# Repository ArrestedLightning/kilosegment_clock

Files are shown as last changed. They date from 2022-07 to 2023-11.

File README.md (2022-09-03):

Kilosegment Clock
==================

Contents of the Firmware directory is licensed under GPLv3.

All other content in this repository is licensed under CC BY 4.0.

Acknowledgments
=================

Firmware for this project is based substantially on John Bradnam's work here: https://create.arduino.cc/projecthub/john-bradnam/7-segment-array-clock-cd5b07

His project, in turn, was based in part upon Frugha's project here: https://hackaday.io/project/169632-7-segment-display-array-clock

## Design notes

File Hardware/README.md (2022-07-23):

Kilosegment Clock Hardware
===============

Rev A and Rev B should be functionally identical.  Rev A is designed with individual 7-segment displays, and Rev B uses 4-digit displays, which substantially reduces the number of through-hole pins that need to be soldered.

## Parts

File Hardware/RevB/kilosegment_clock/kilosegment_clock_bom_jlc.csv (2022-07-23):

Comment | Designator | Footprint | LCSC Part #
Battery_Cell | BT1 | BatteryHolder_CR2032-BS-6-1_1x2032 | C964764
0.1uF | C10,C11,C12,C13,C20,C21,C22,C24,C23 | C_0805_2012Metric_Pad1.18x1.45mm_HandSolder | C49678
1uF | C14,C15,C25,C1,C2,C3,C4,C5,C6,C7,C8,C9 | C_0805_2012Metric_Pad1.18x1.45mm_HandSolder | C28323
12pF | C16,C17 | C_0805_2012Metric_Pad1.18x1.45mm_HandSolder | C1792
20pF | C18,C19 | C_0805_2012Metric_Pad1.18x1.45mm_HandSolder | C1798
LED | D1 | LED_0805_2012Metric_Pad1.15x1.40mm_HandSolder | C84256
FJ5461AHred | D6,D5,D4,D3,D10,D9,D8,D7,D14,D13,D12,D11,D18,D17,D16,D15,D22,D21,D20,D19,D26,D25,D24,D23,D30,D29,D28,D27,D34,D33,D32,D31,D38,D37,D36,D35 | LED-SEG-TH_FJ5461AH | C54396
LM75BDP | IC1 | MSOP-8_3x3mm_P0.65mm | C2837470
USB_C_Receptacle_USB2.0 | J3 | USB_C_Receptacle_HRO_TYPE-C-31-M-12 | C165948
Speaker | LS1 | BUZ-TH_PKM13EPYH4002-B0 | C128650
AO3400A | Q1 | SOT-23_Handsoldering | C20917
2.7K | R1,R2 | R_0805_2012Metric_Pad1.20x1.40mm_HandSolder | C17530
0 | R3,R8 | R_0805_2012Metric_Pad1.20x1.40mm_HandSolder | C17477
5.1K | R4,R5,R9 | R_0805_2012Metric_Pad1.20x1.40mm_HandSolder | C27834
1K | R7,R6 | R_0805_2012Metric_Pad1.20x1.40mm_HandSolder | C17513
SW_Push | SW1,SW2,SW3,SW4 | SW_SPST_TL3342 | C318886
GN6932 | U0,U1,U2,U3,U4,U5,U6,U7,U8 | SOP-32_L21.0-W7.5-P1.27-LS10.4-BL | C265476
HT7533-1-SOT89 | U9 | SOT-89-3 | C14289
STM32F103C8T6 | U10 | LQFP-48_7x7mm_P0.5mm | C77994
SN74ACT244PWRG4 | U12,U11 | TSSOP-20_4.4x6.5mm_P0.65mm | C6930
LTR-303ALS-01 | U13 | SOT-363_SC-70-6_Handsoldering | C364577
32.768KHz | Y1 | Crystal_SMD_3215-2Pin_3.2x1.5mm | C32346
8MHz | Y2 | Crystal_SMD_5032-2Pin_5.0x3.2mm_HandSoldering | C115962

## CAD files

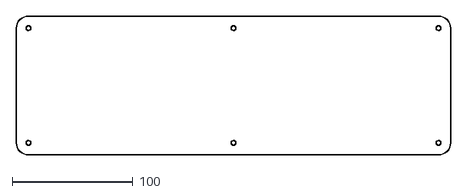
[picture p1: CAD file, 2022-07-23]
Hardware/RevB/kilosegment_clock/Board Outline.dxf
360.0 x 115.0

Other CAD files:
Hardware/RevB/Board Outline.FCStd
Hardware/RevA/Board Outline.FCStd

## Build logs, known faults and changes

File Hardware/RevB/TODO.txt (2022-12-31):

Label for D31 is in the wrong location (obviously not a functional issue).
Add a header input for 5V so it can be powered without USB.
Add letters below OSHW logo
Add more thermal isolation to temperature sensor IC.
Consider increasing capacitor size on display drivers and enhancing ground/power connections.
USB series and pull up resistors
Stronger pullup on reset pin

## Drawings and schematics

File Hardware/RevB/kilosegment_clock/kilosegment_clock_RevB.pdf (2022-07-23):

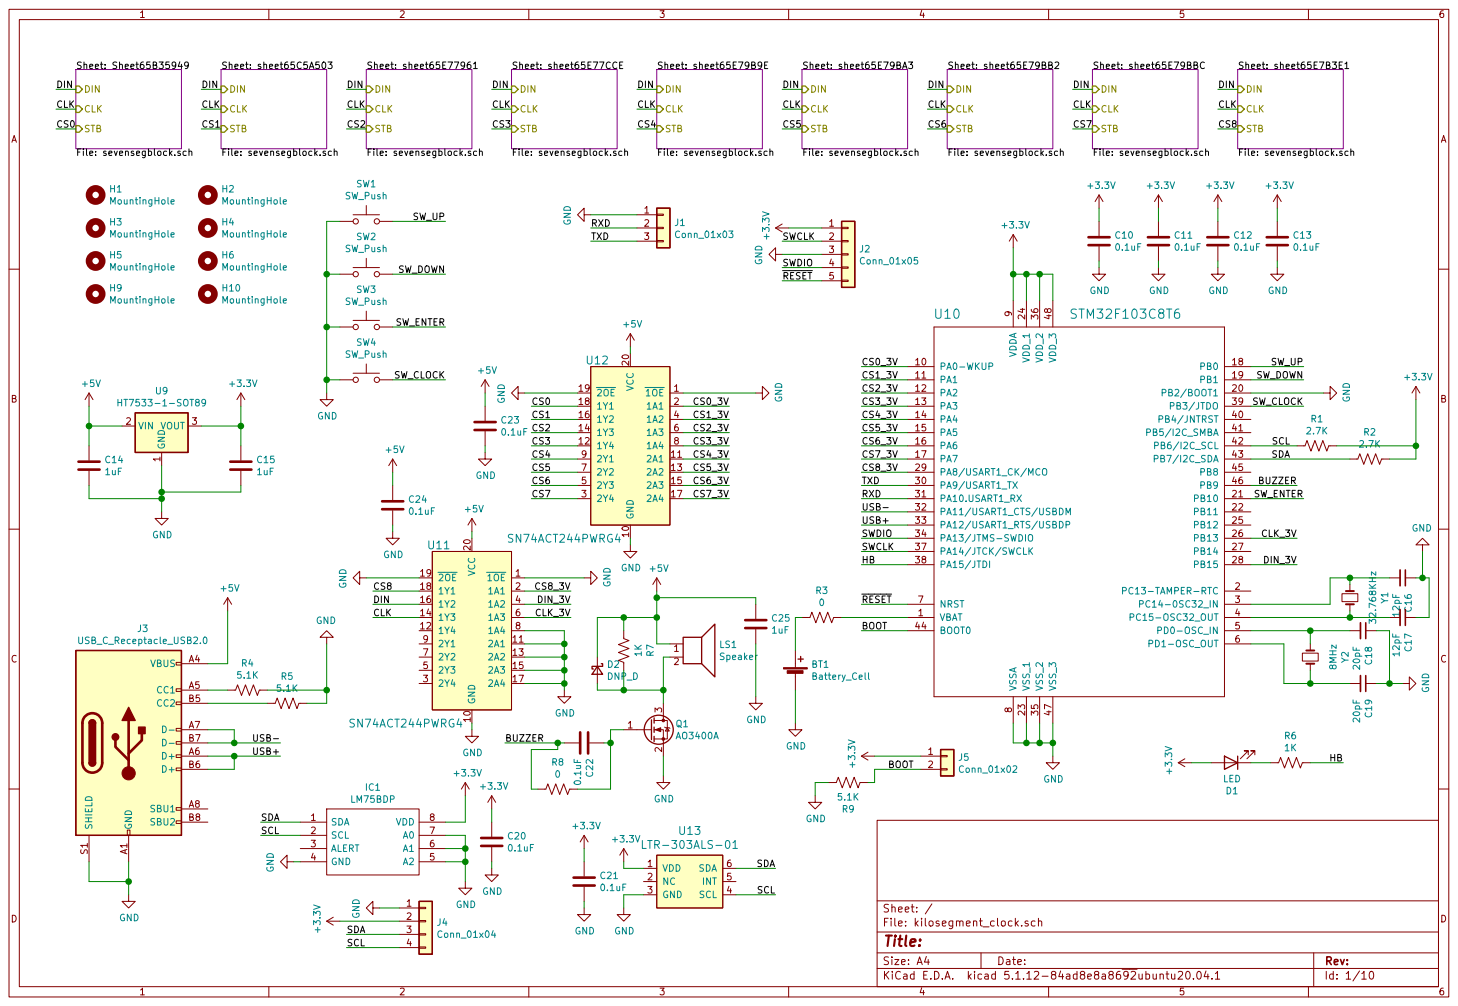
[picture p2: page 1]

File: sevensegblock.sch DIN
CLK
STB

Sheet: Sheet65B35949 File: sevensegblock.sch DIN
DIN

Sheet: sheet65C5A503 File: sevensegblock.sch DIN
CS8_3V CS0_3V DIN

Sheet: sheet65E77961 File: sevensegblock.sch DIN
SW_UP CLK DIN

Sheet: sheet65E79BA3 File: sevensegblock.sch DIN

Sheet: sheet65E79BB2 File: sevensegblock.sch DIN

Sheet: sheet65E7B3E1 File: sevensegblock.sch DIN

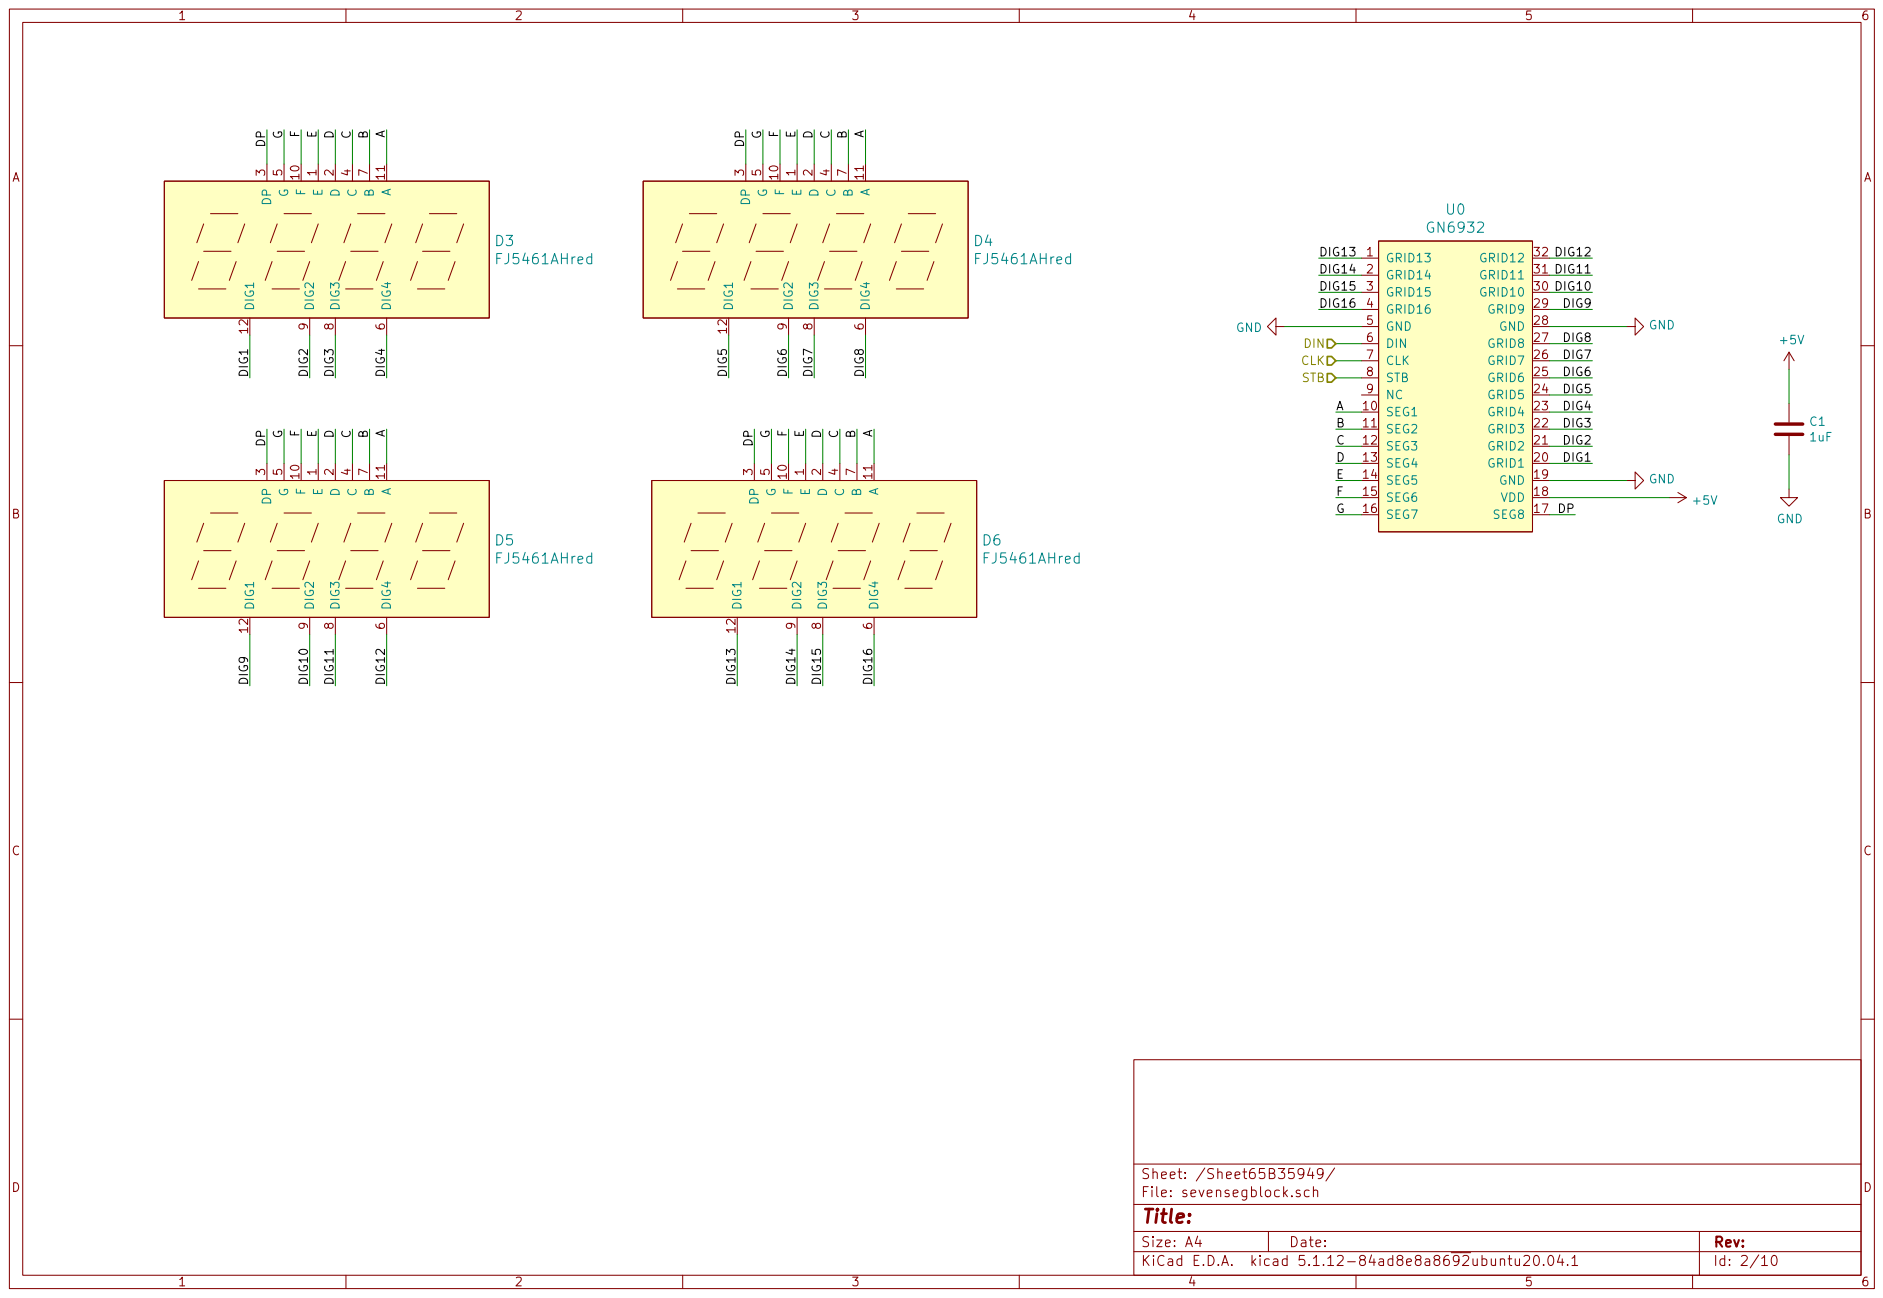
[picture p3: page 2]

File: sevensegblock.sch Sheet: /Sheet65B35949/
Id: 2/10 Title:

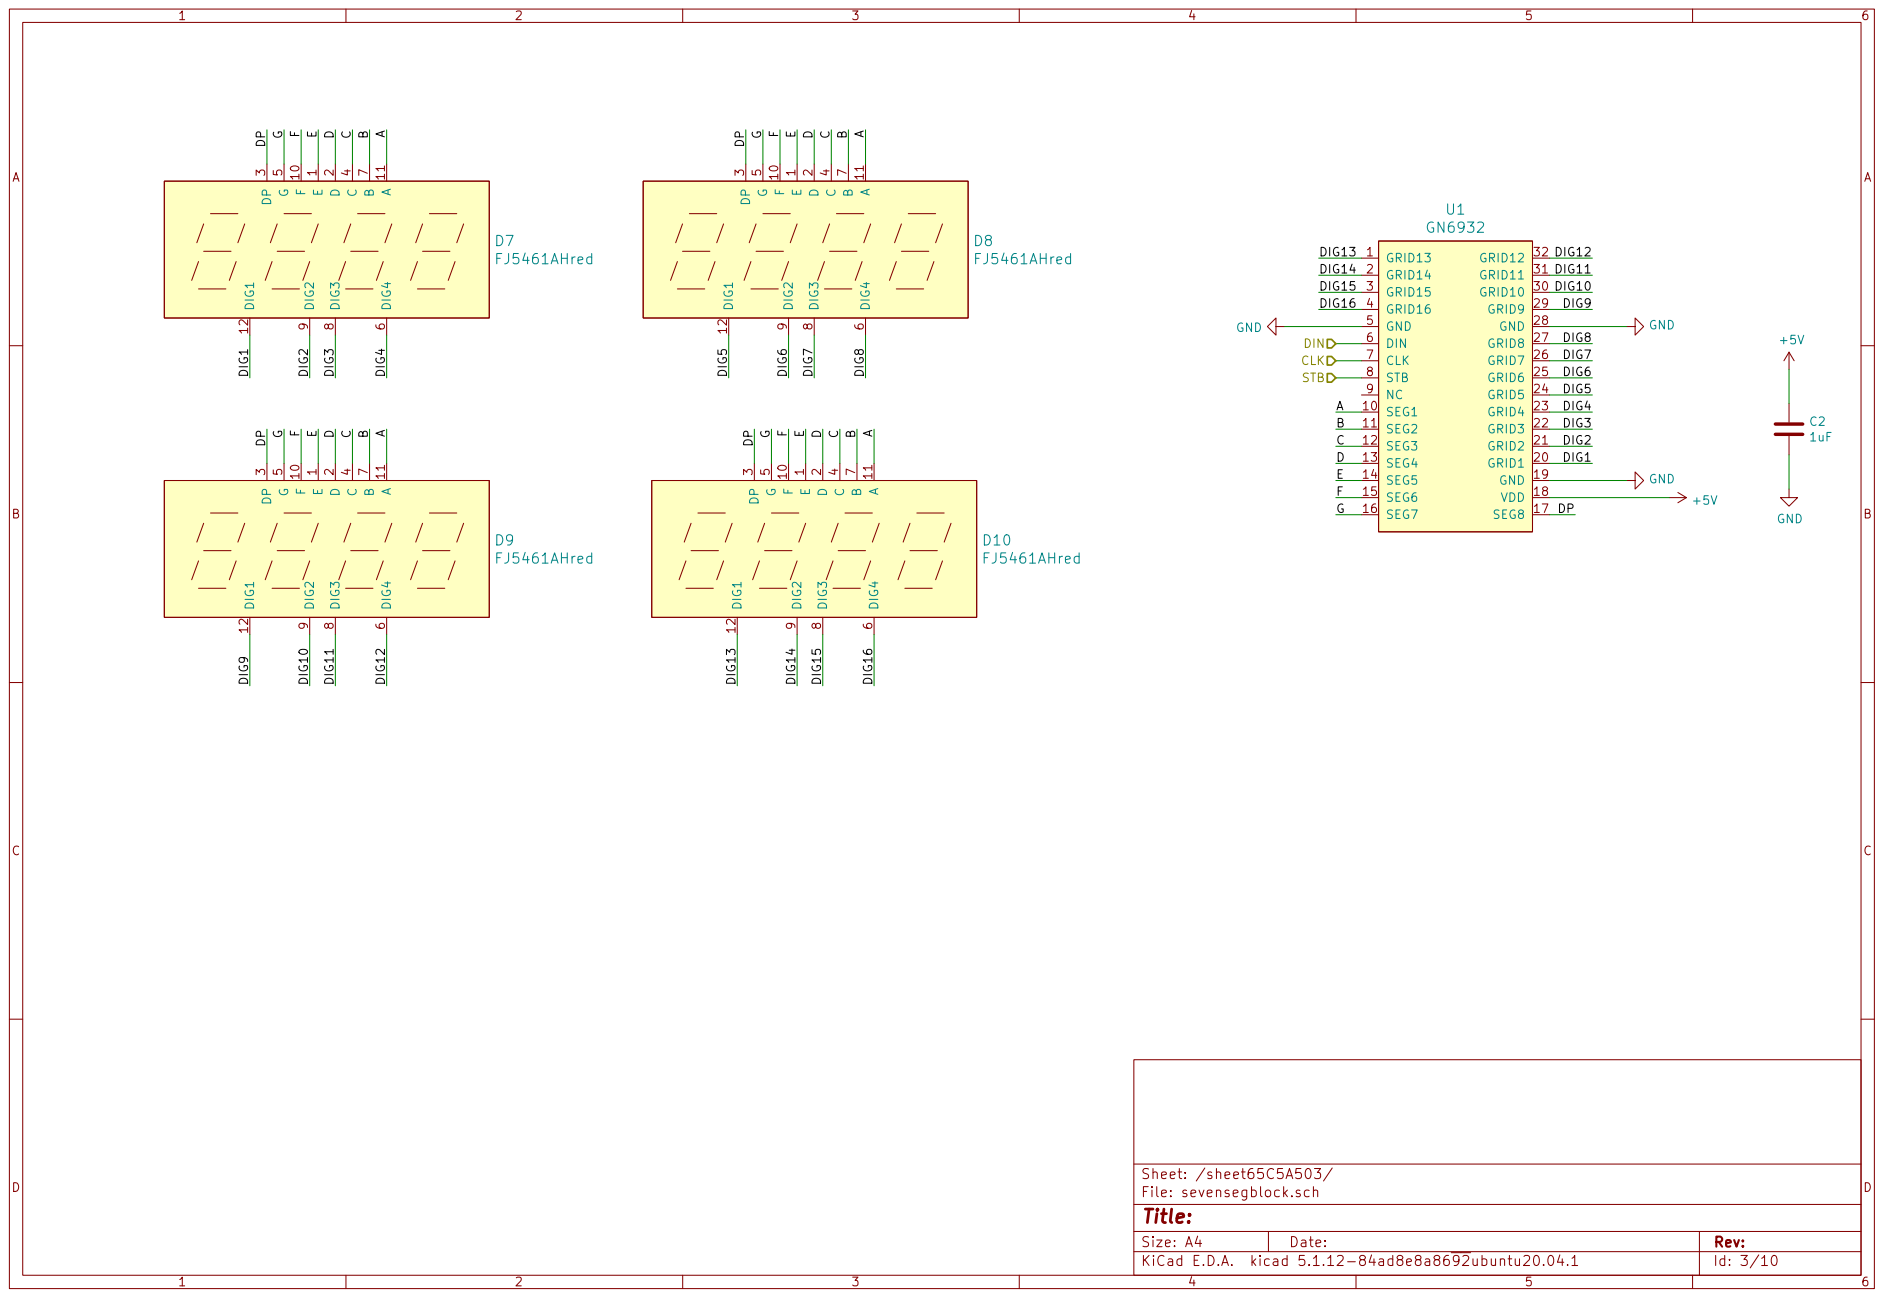
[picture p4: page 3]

File: sevensegblock.sch Sheet: /sheet65C5A503/
Id: 3/10 Title:

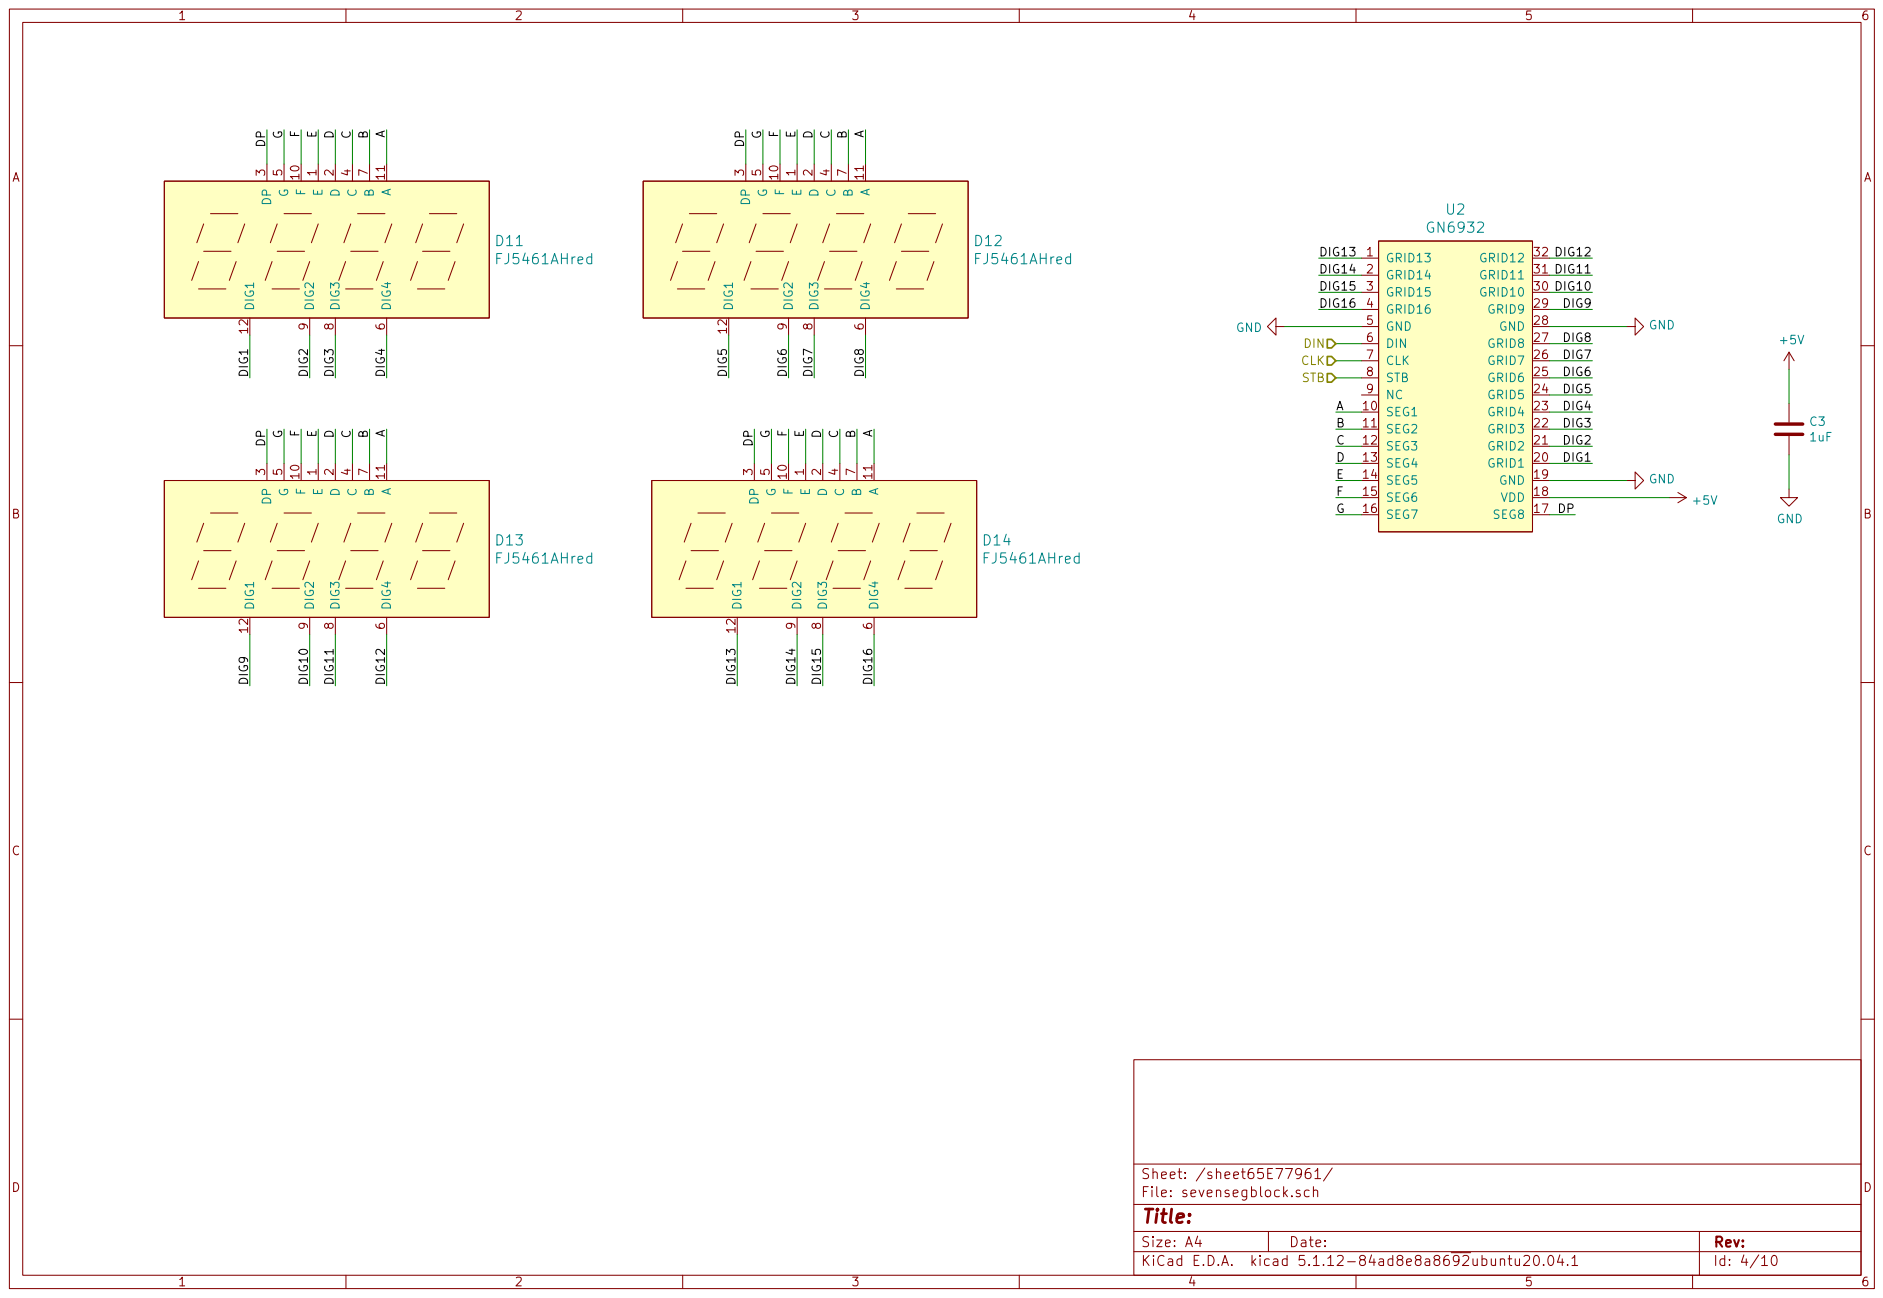
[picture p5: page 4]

File: sevensegblock.sch Sheet: /sheet65E77961/
Id: 4/10 Title:

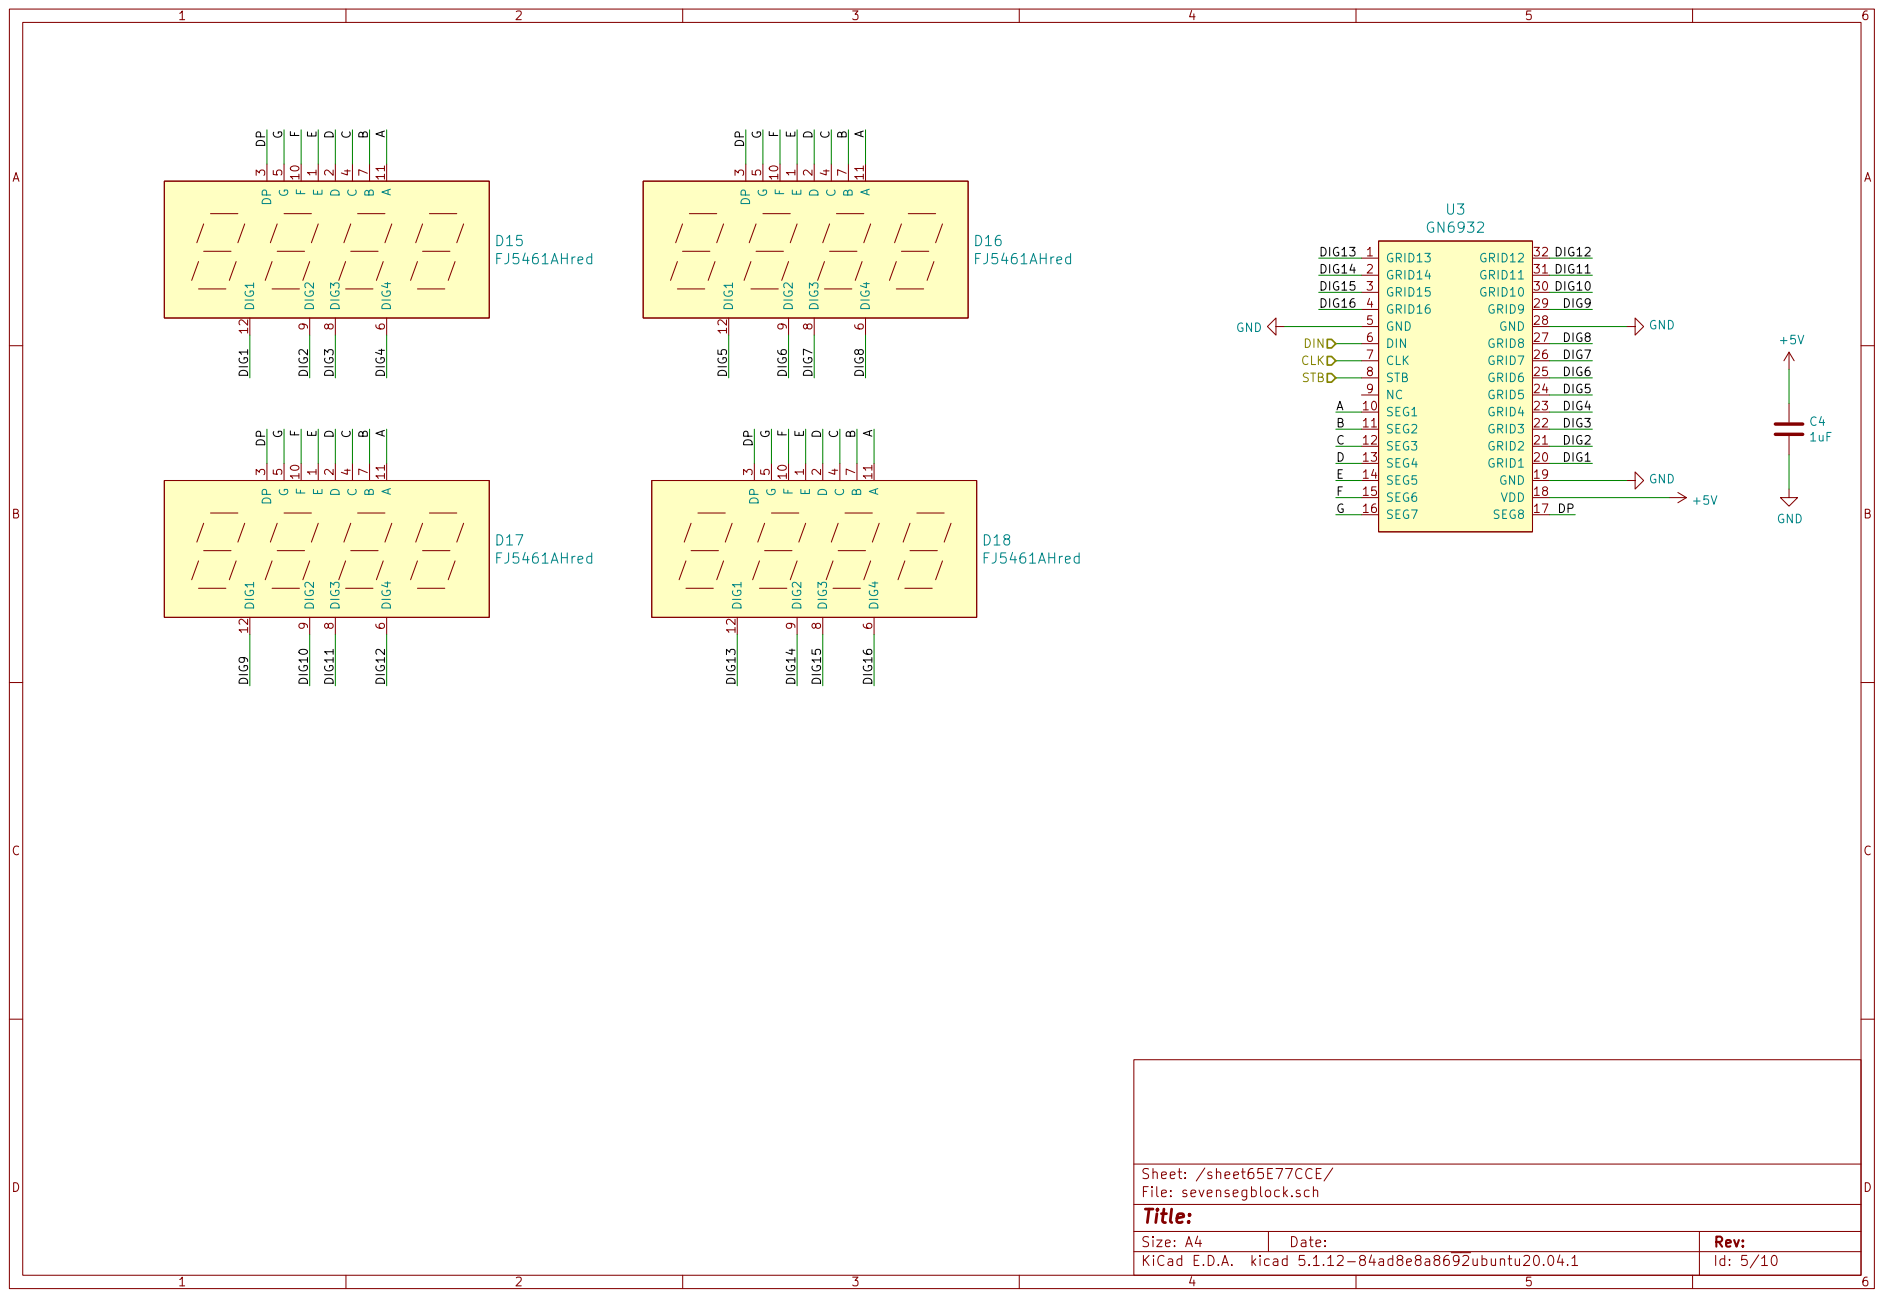
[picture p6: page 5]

File: sevensegblock.sch Sheet: /sheet65E77CCE/
Id: 5/10 Title:

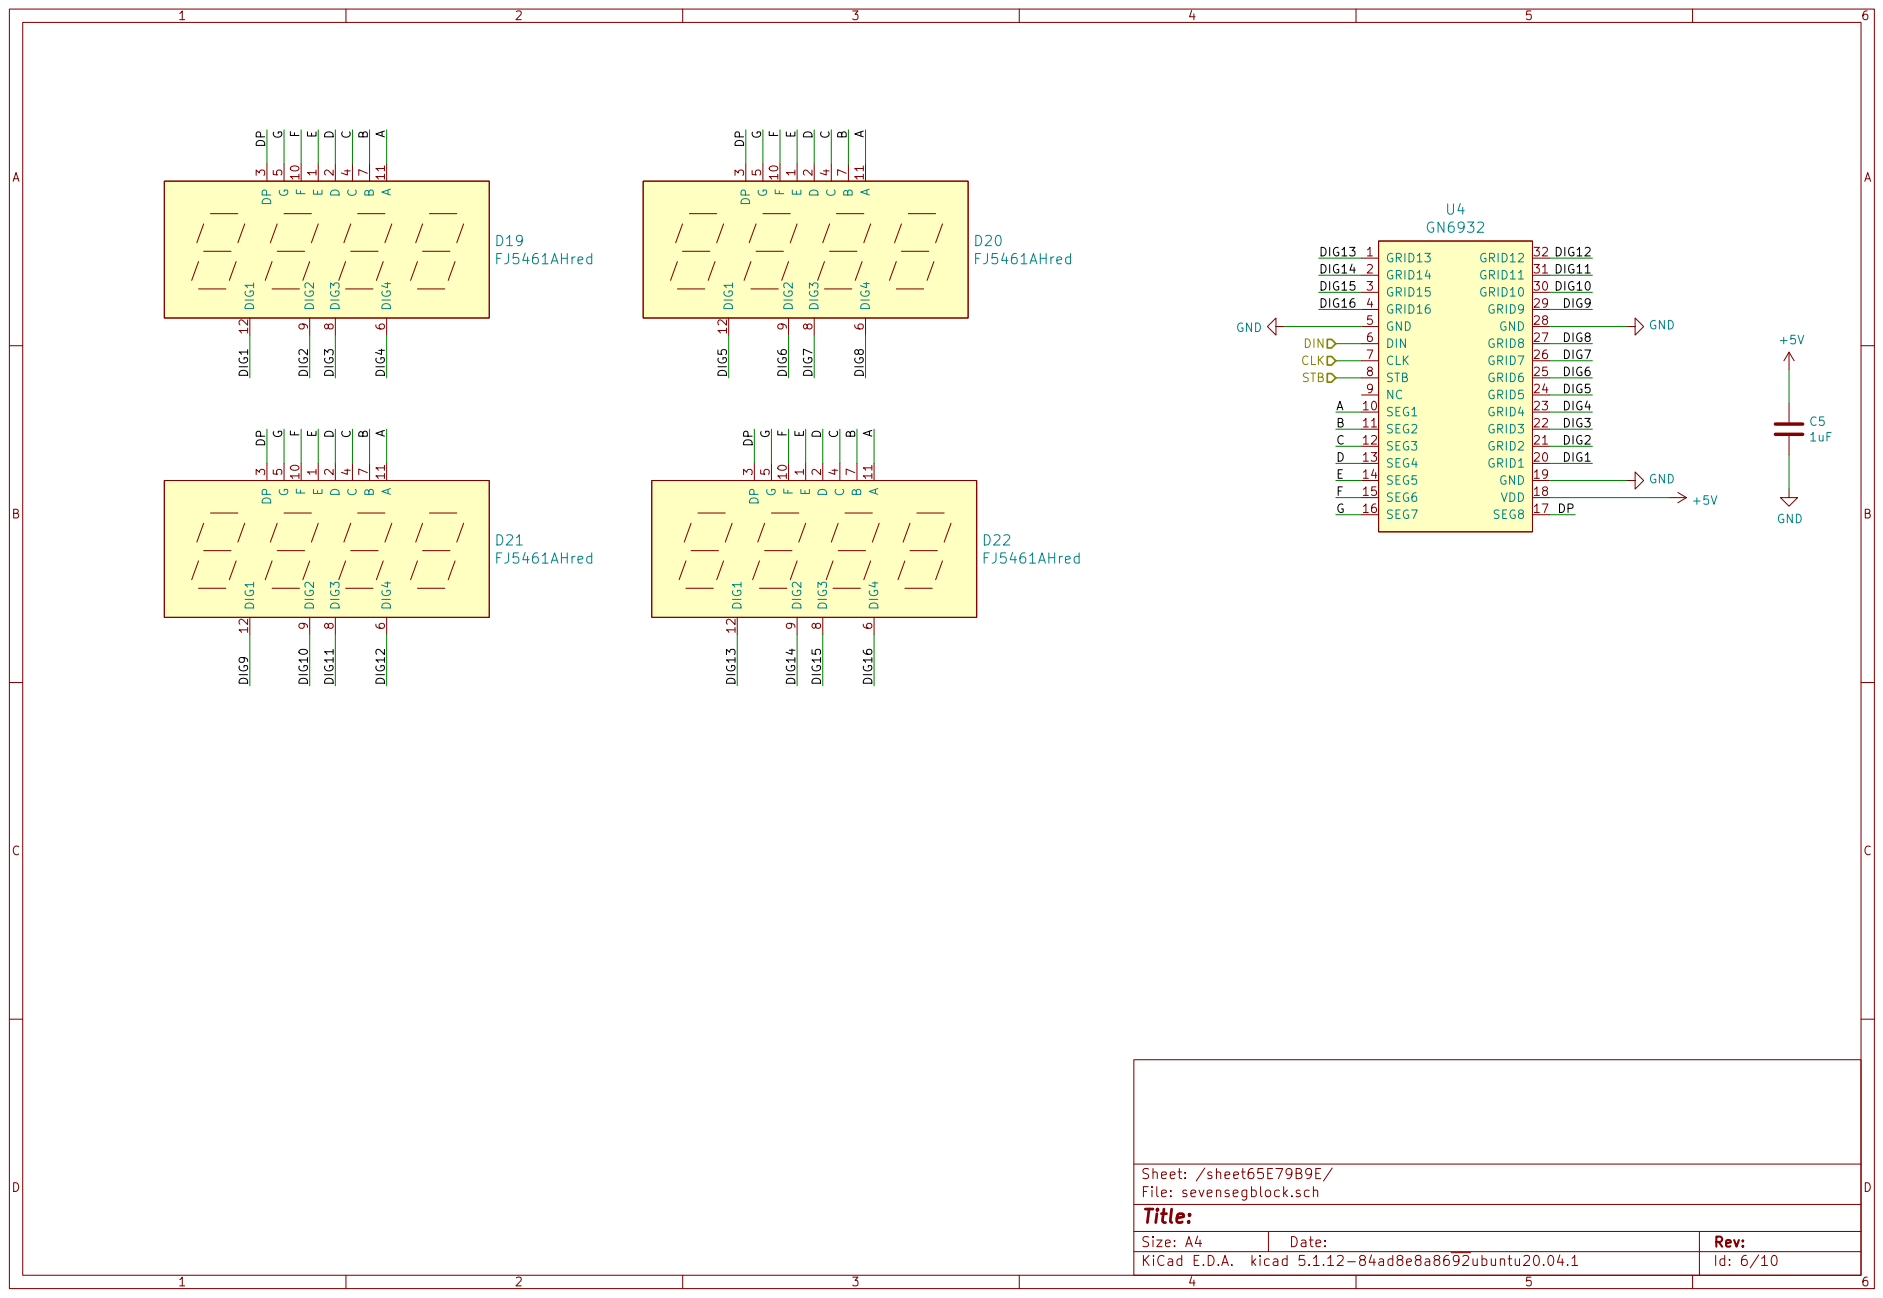
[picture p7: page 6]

File: sevensegblock.sch Sheet: /sheet65E79B9E/
Id: 6/10 Title:

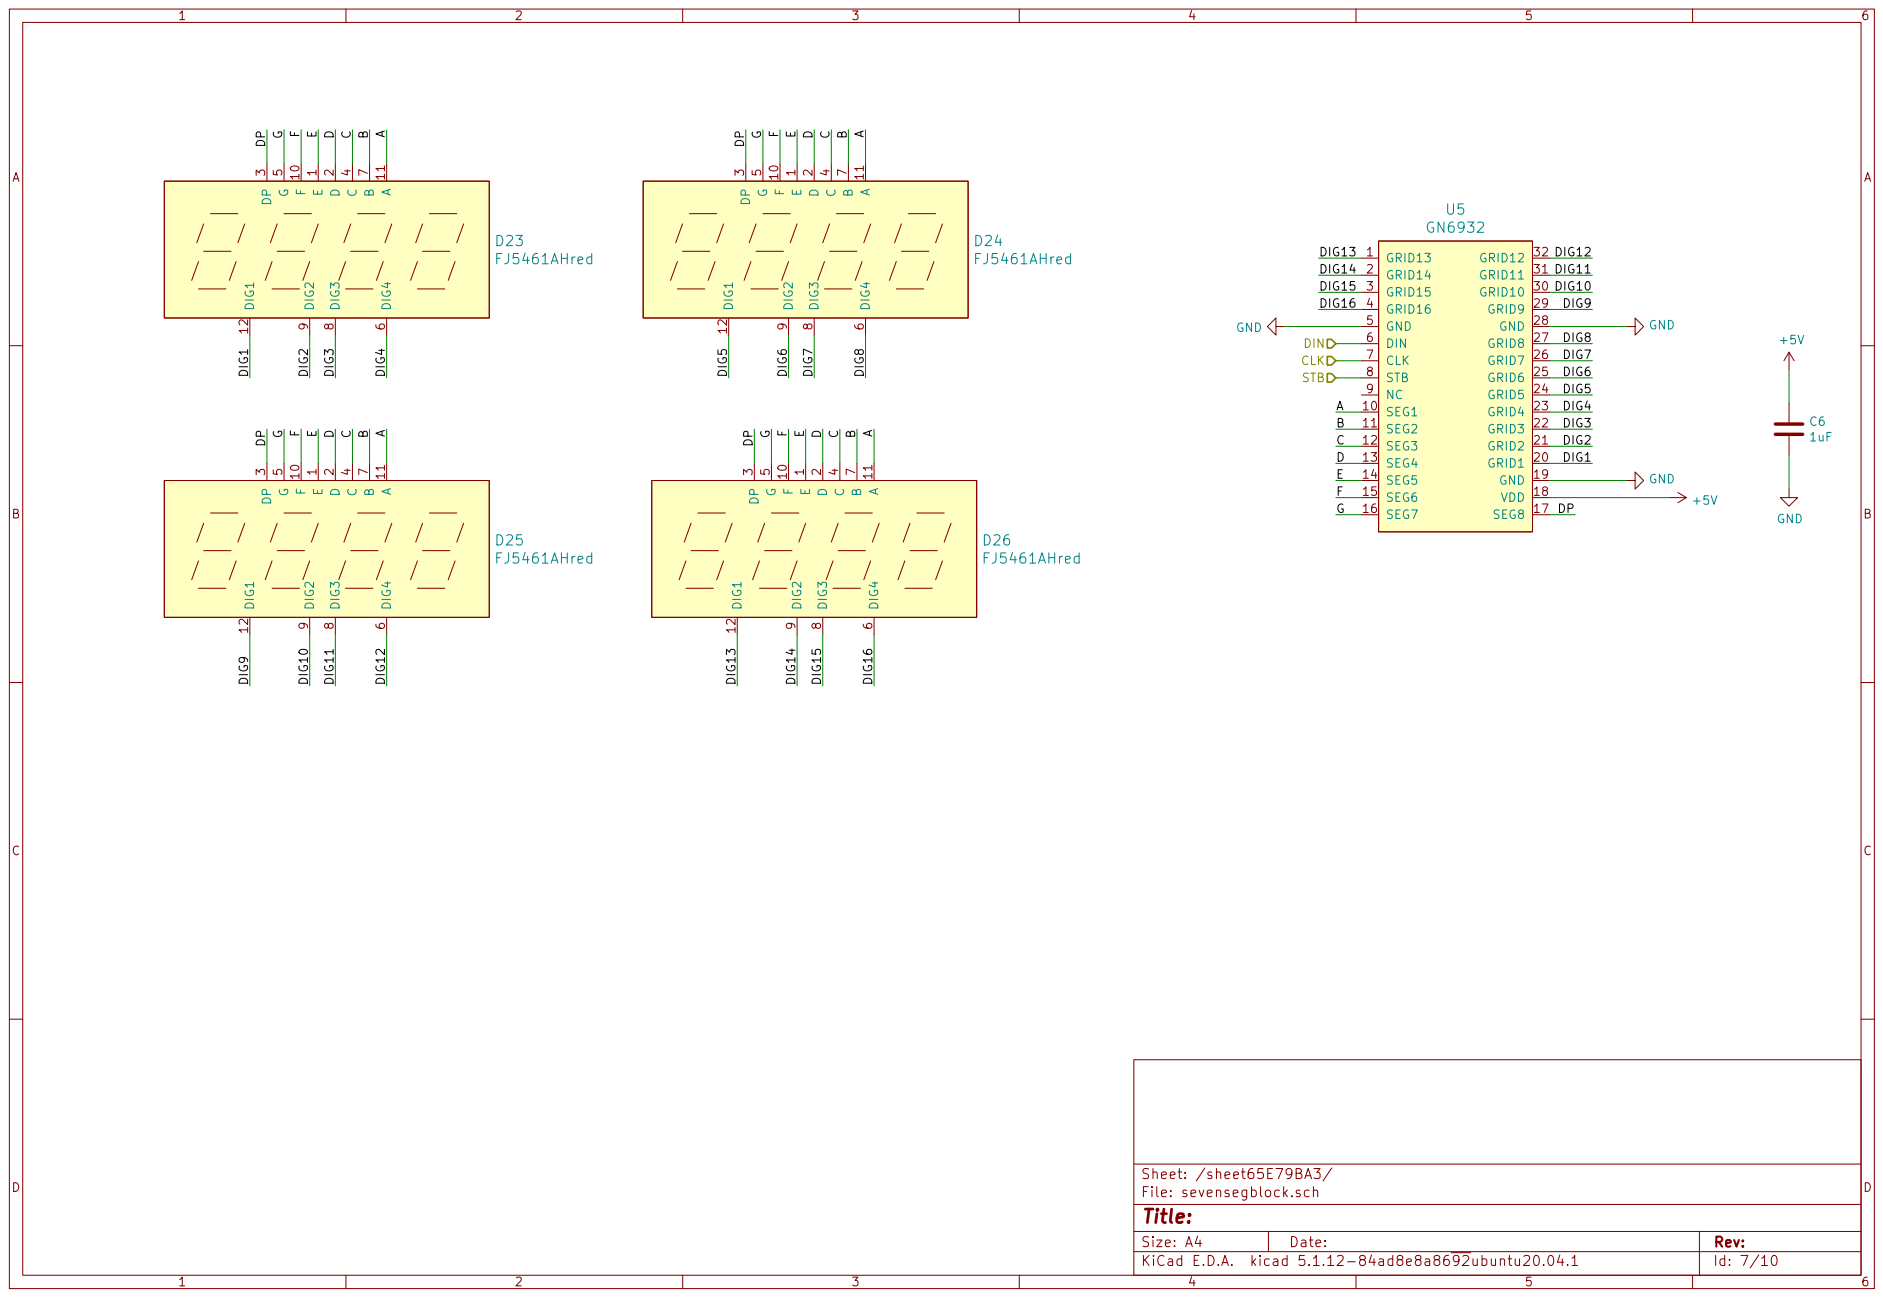
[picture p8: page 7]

File: sevensegblock.sch Sheet: /sheet65E79BA3/
Id: 7/10 Title:

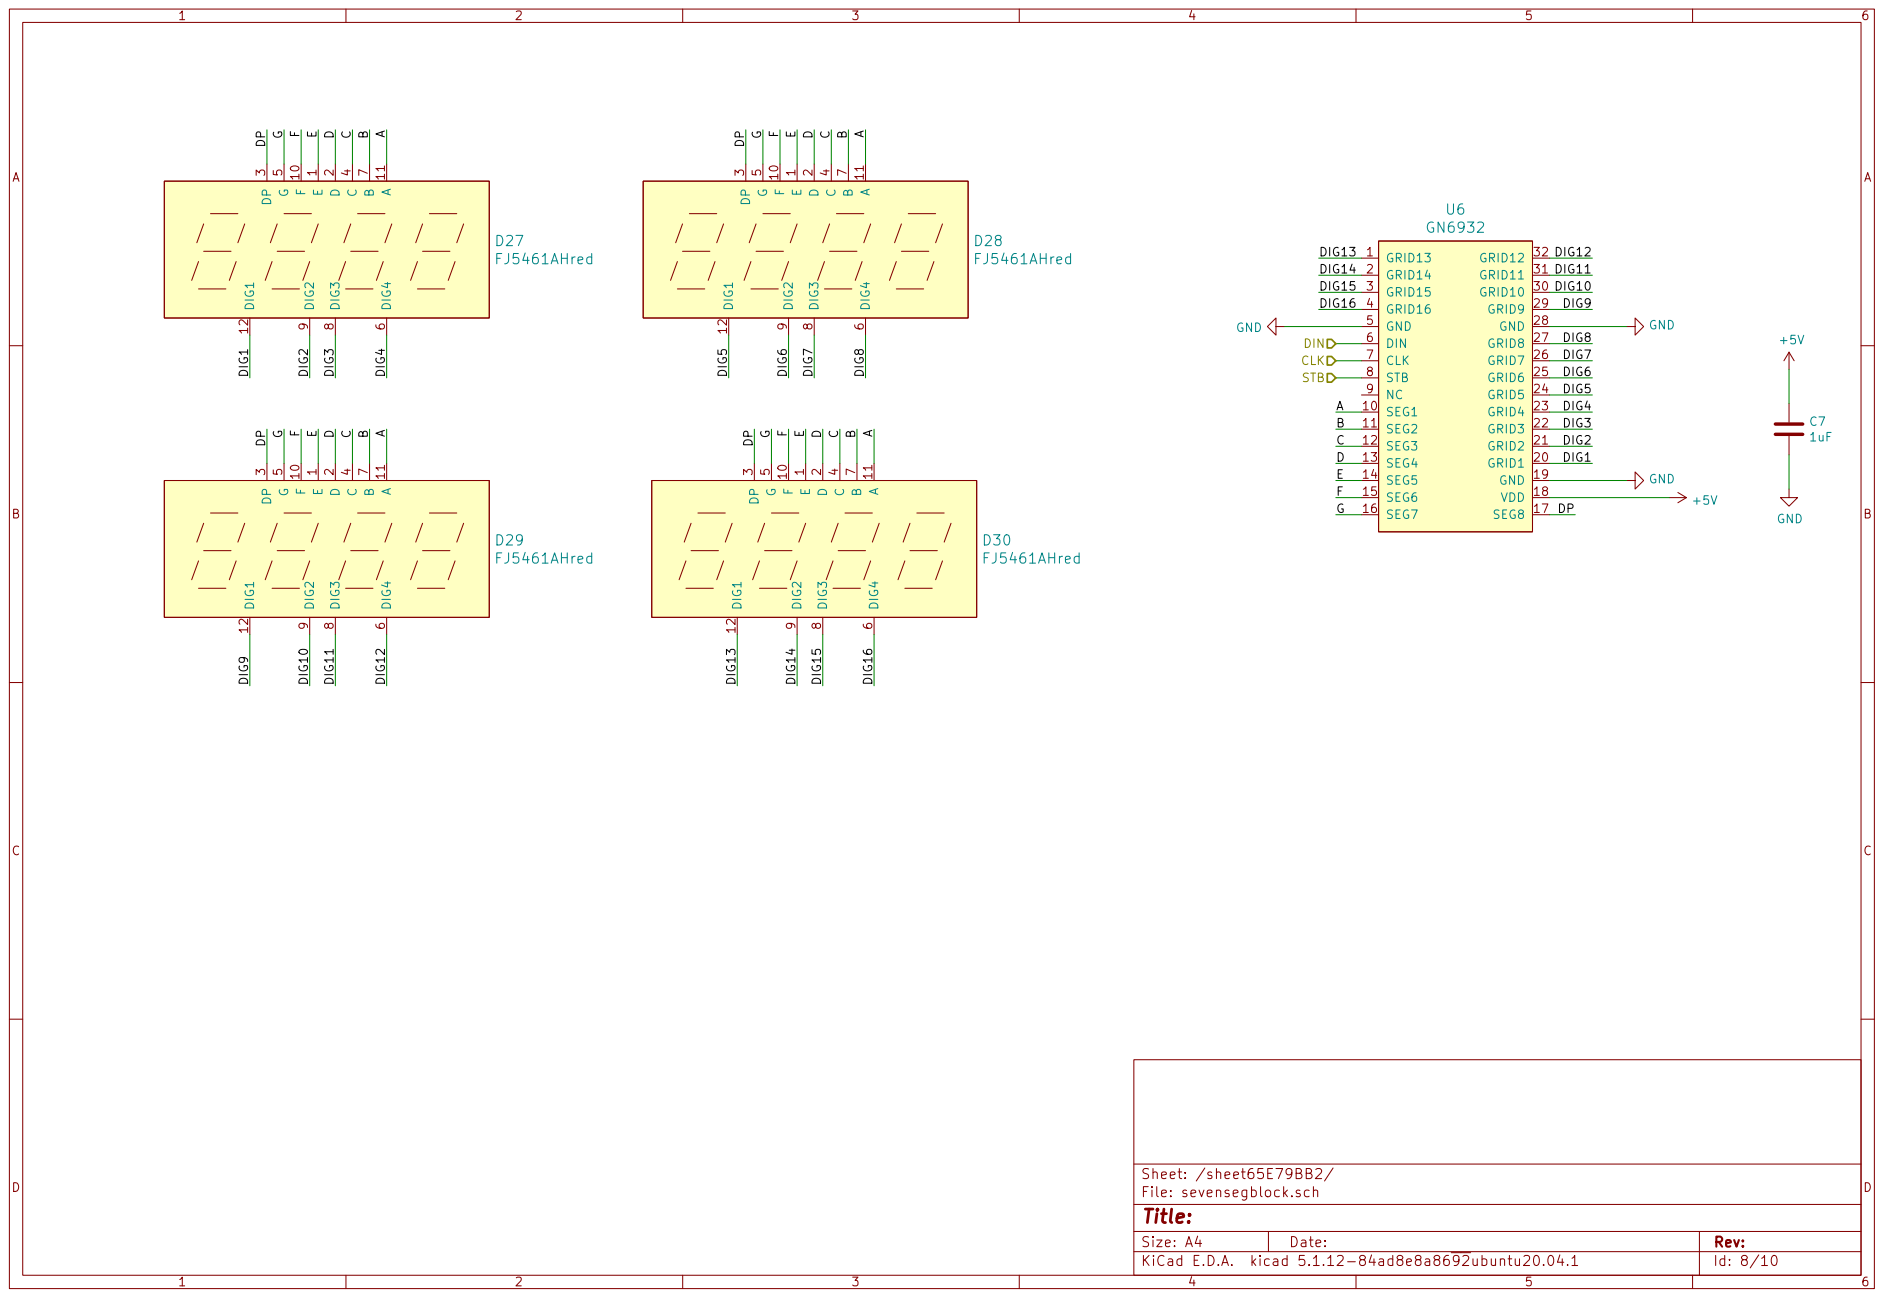
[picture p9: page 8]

File: sevensegblock.sch Sheet: /sheet65E79BB2/
Id: 8/10 Title:

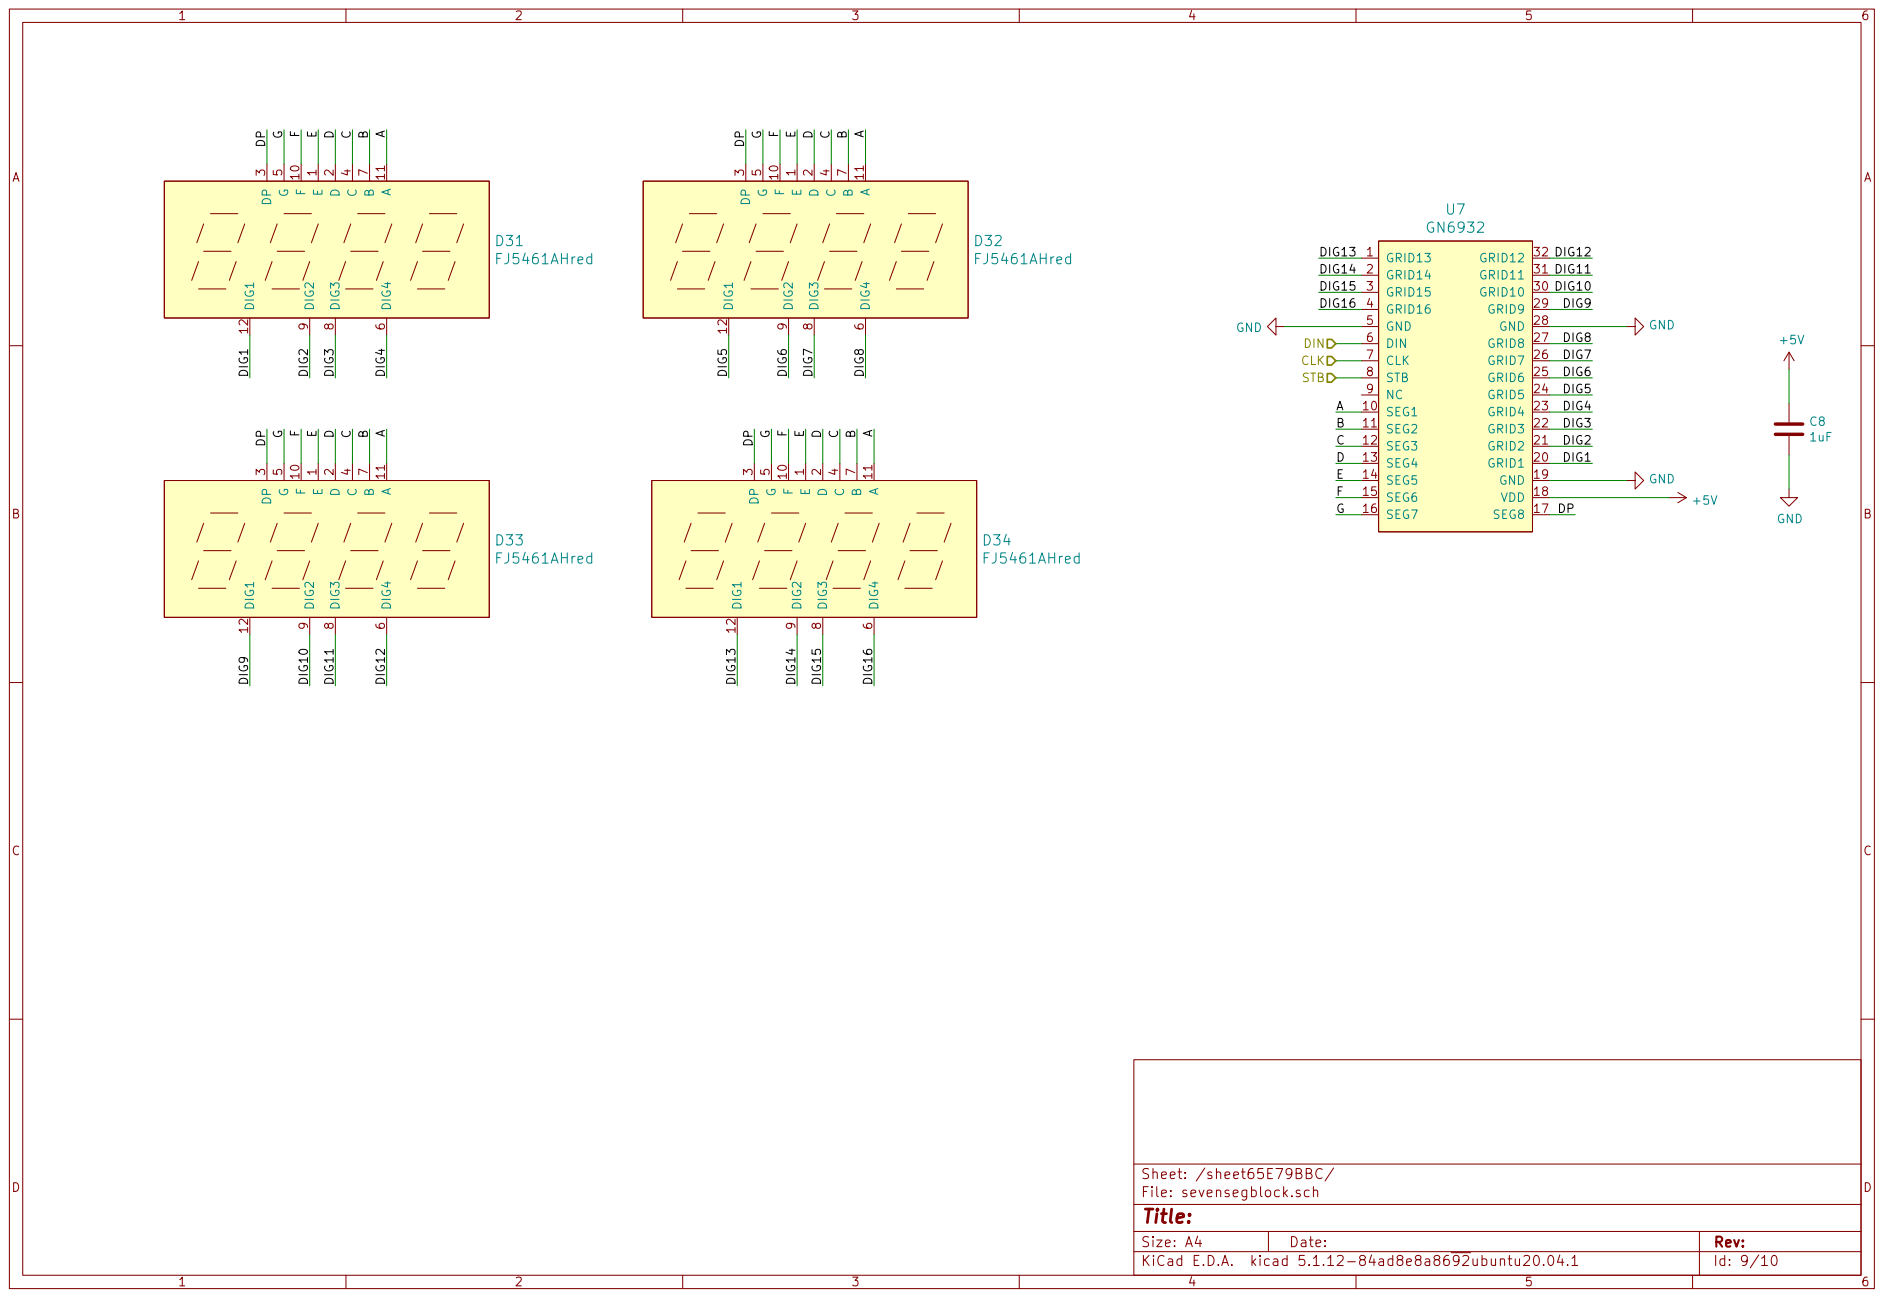
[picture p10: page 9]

File: sevensegblock.sch Sheet: /sheet65E79BBC/
Id: 9/10 Title:

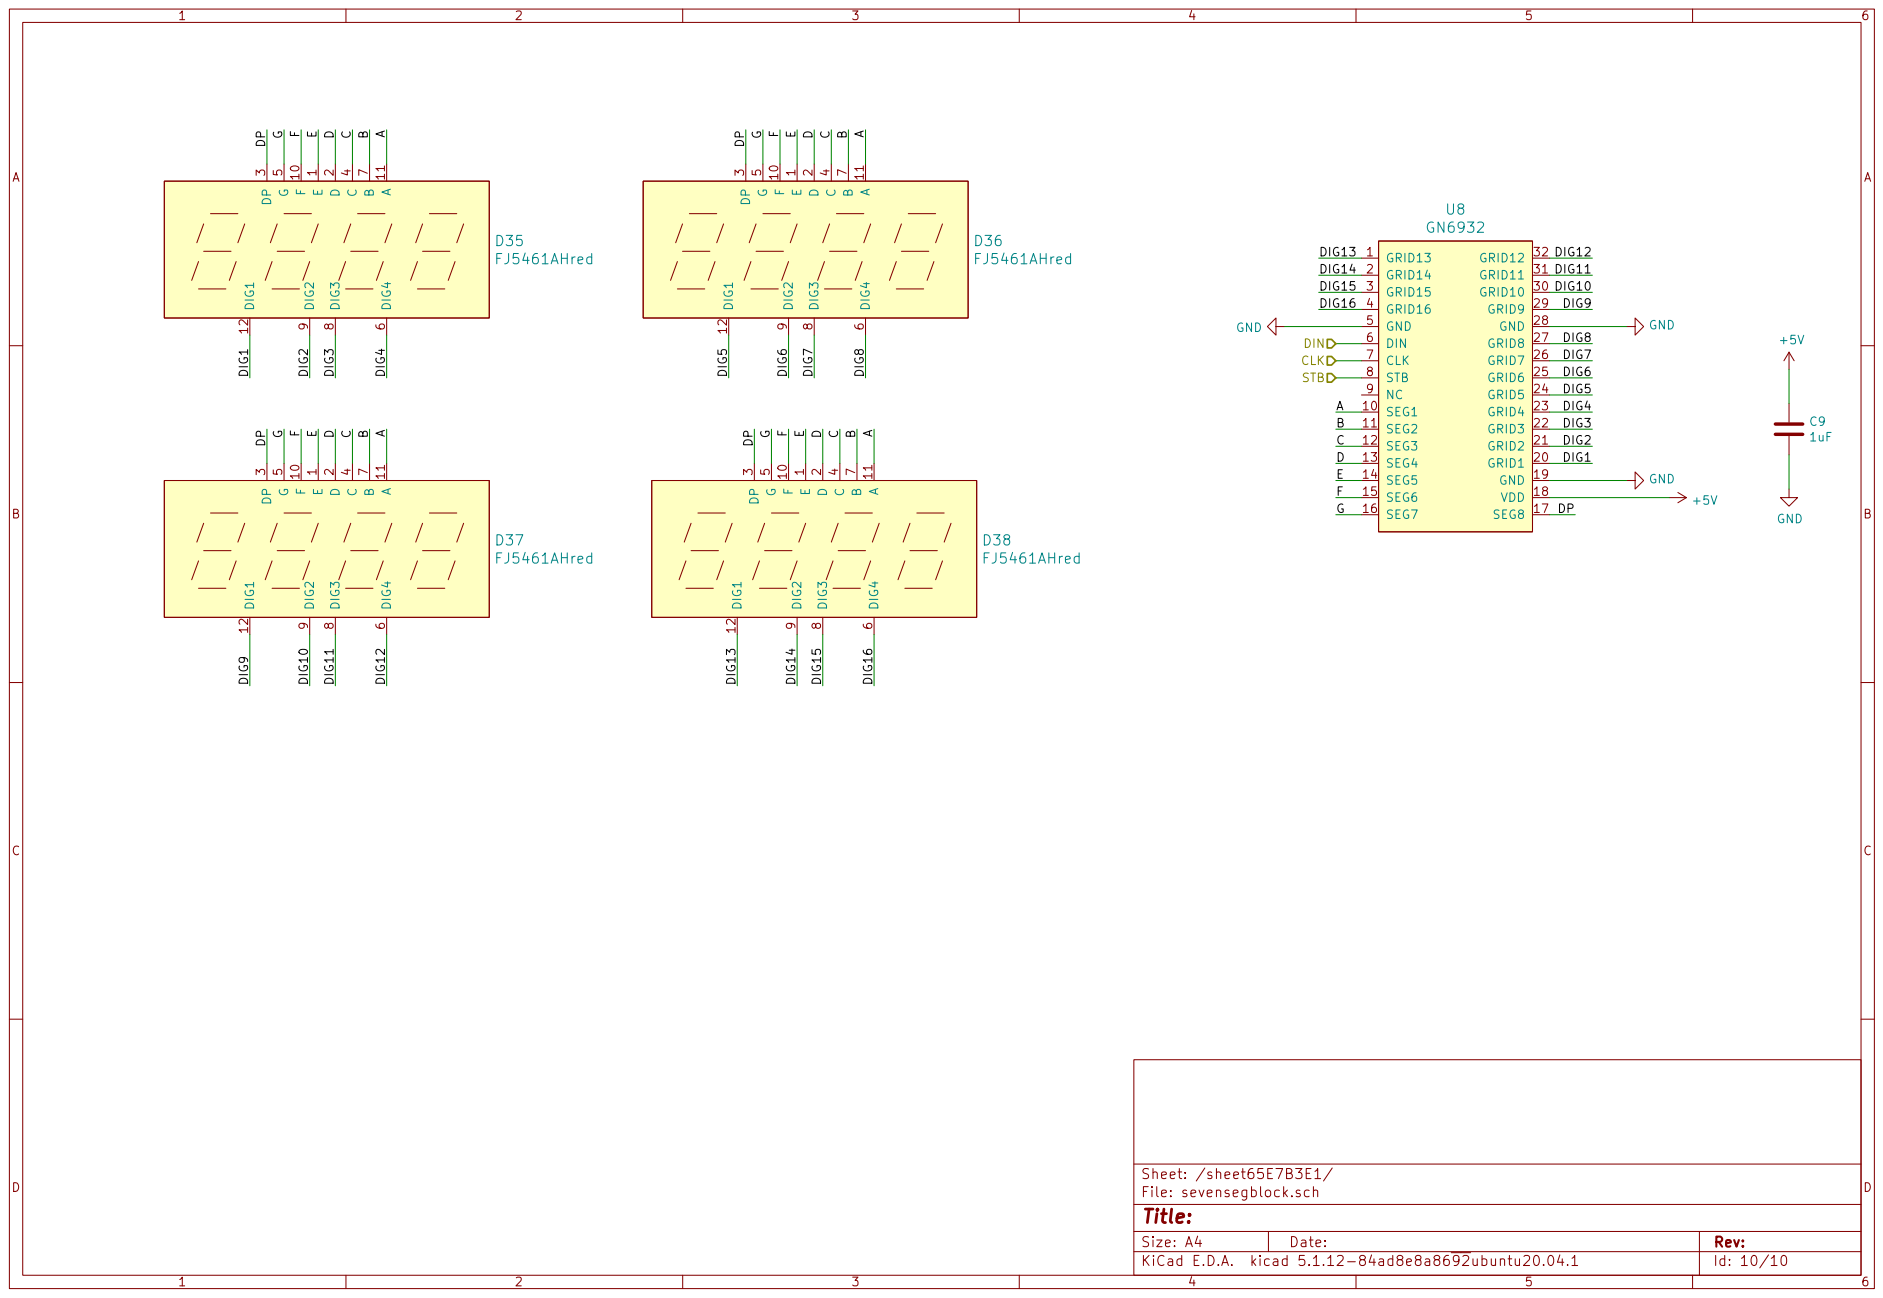
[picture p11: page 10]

File: sevensegblock.sch Sheet: /sheet65E7B3E1/
Id: 10/10 Title:

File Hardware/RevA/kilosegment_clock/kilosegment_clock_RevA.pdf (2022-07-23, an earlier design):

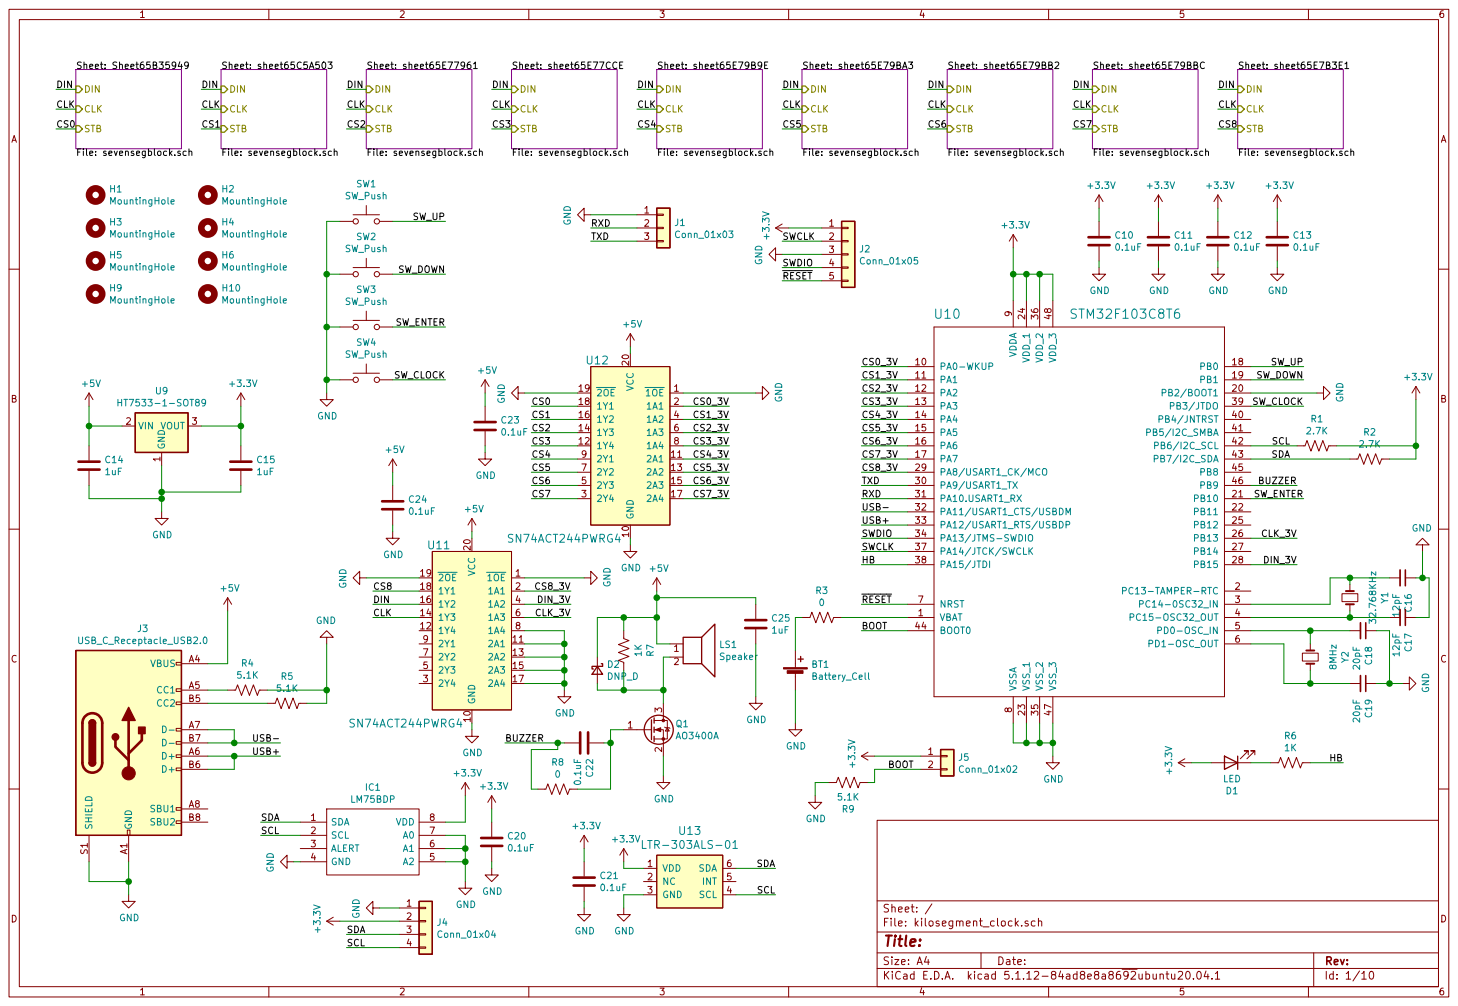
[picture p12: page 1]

File: sevensegblock.sch DIN
CLK
STB

Sheet: Sheet65B35949 File: sevensegblock.sch DIN
DIN

Sheet: sheet65C5A503 File: sevensegblock.sch DIN
CS8_3V CS0_3V DIN

Sheet: sheet65E77961 File: sevensegblock.sch DIN
SW_UP CLK DIN

Sheet: sheet65E79BA3 File: sevensegblock.sch DIN

Sheet: sheet65E79BB2 File: sevensegblock.sch DIN

Sheet: sheet65E7B3E1 File: sevensegblock.sch DIN

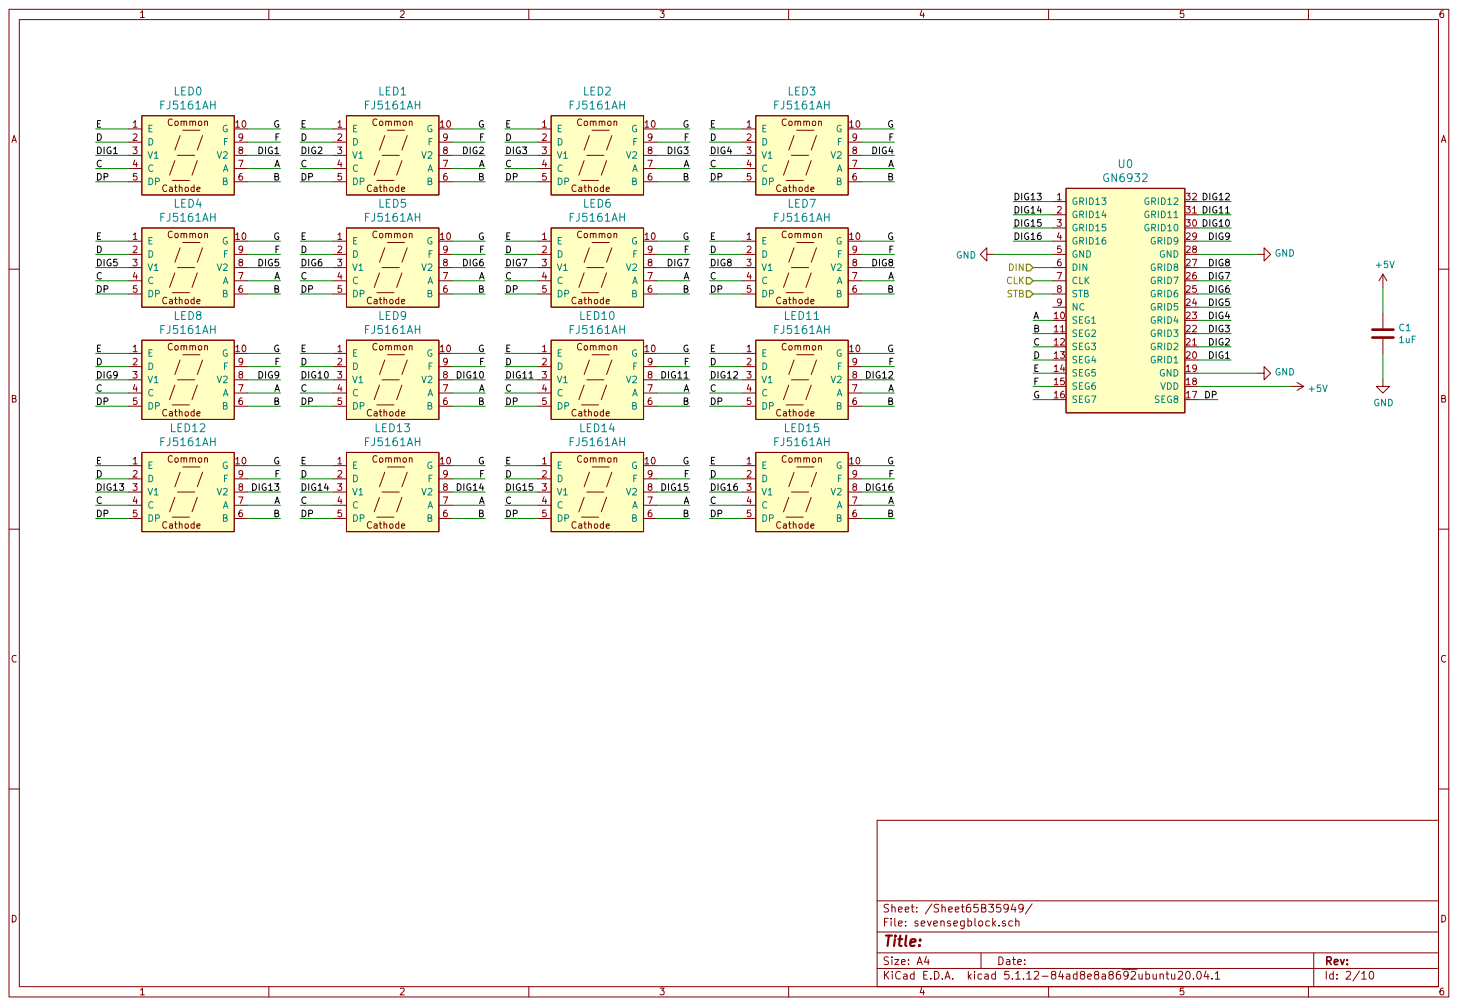
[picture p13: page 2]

File: sevensegblock.sch Sheet: /Sheet65B35949/
Id: 2/10 Title:


File: sevensegblock.sch Sheet: /sheet65C5A503/
Id: 3/10 Title:


File: sevensegblock.sch Sheet: /sheet65E77961/
Id: 4/10 Title:


File: sevensegblock.sch Sheet: /sheet65E77CCE/
Id: 5/10 Title:


File: sevensegblock.sch Sheet: /sheet65E79B9E/
Id: 6/10 Title:


File: sevensegblock.sch Sheet: /sheet65E79BA3/
Id: 7/10 Title:


File: sevensegblock.sch Sheet: /sheet65E79BB2/
Id: 8/10 Title:


File: sevensegblock.sch Sheet: /sheet65E79BBC/
Id: 9/10 Title:


File: sevensegblock.sch Sheet: /sheet65E7B3E1/
Id: 10/10 Title:

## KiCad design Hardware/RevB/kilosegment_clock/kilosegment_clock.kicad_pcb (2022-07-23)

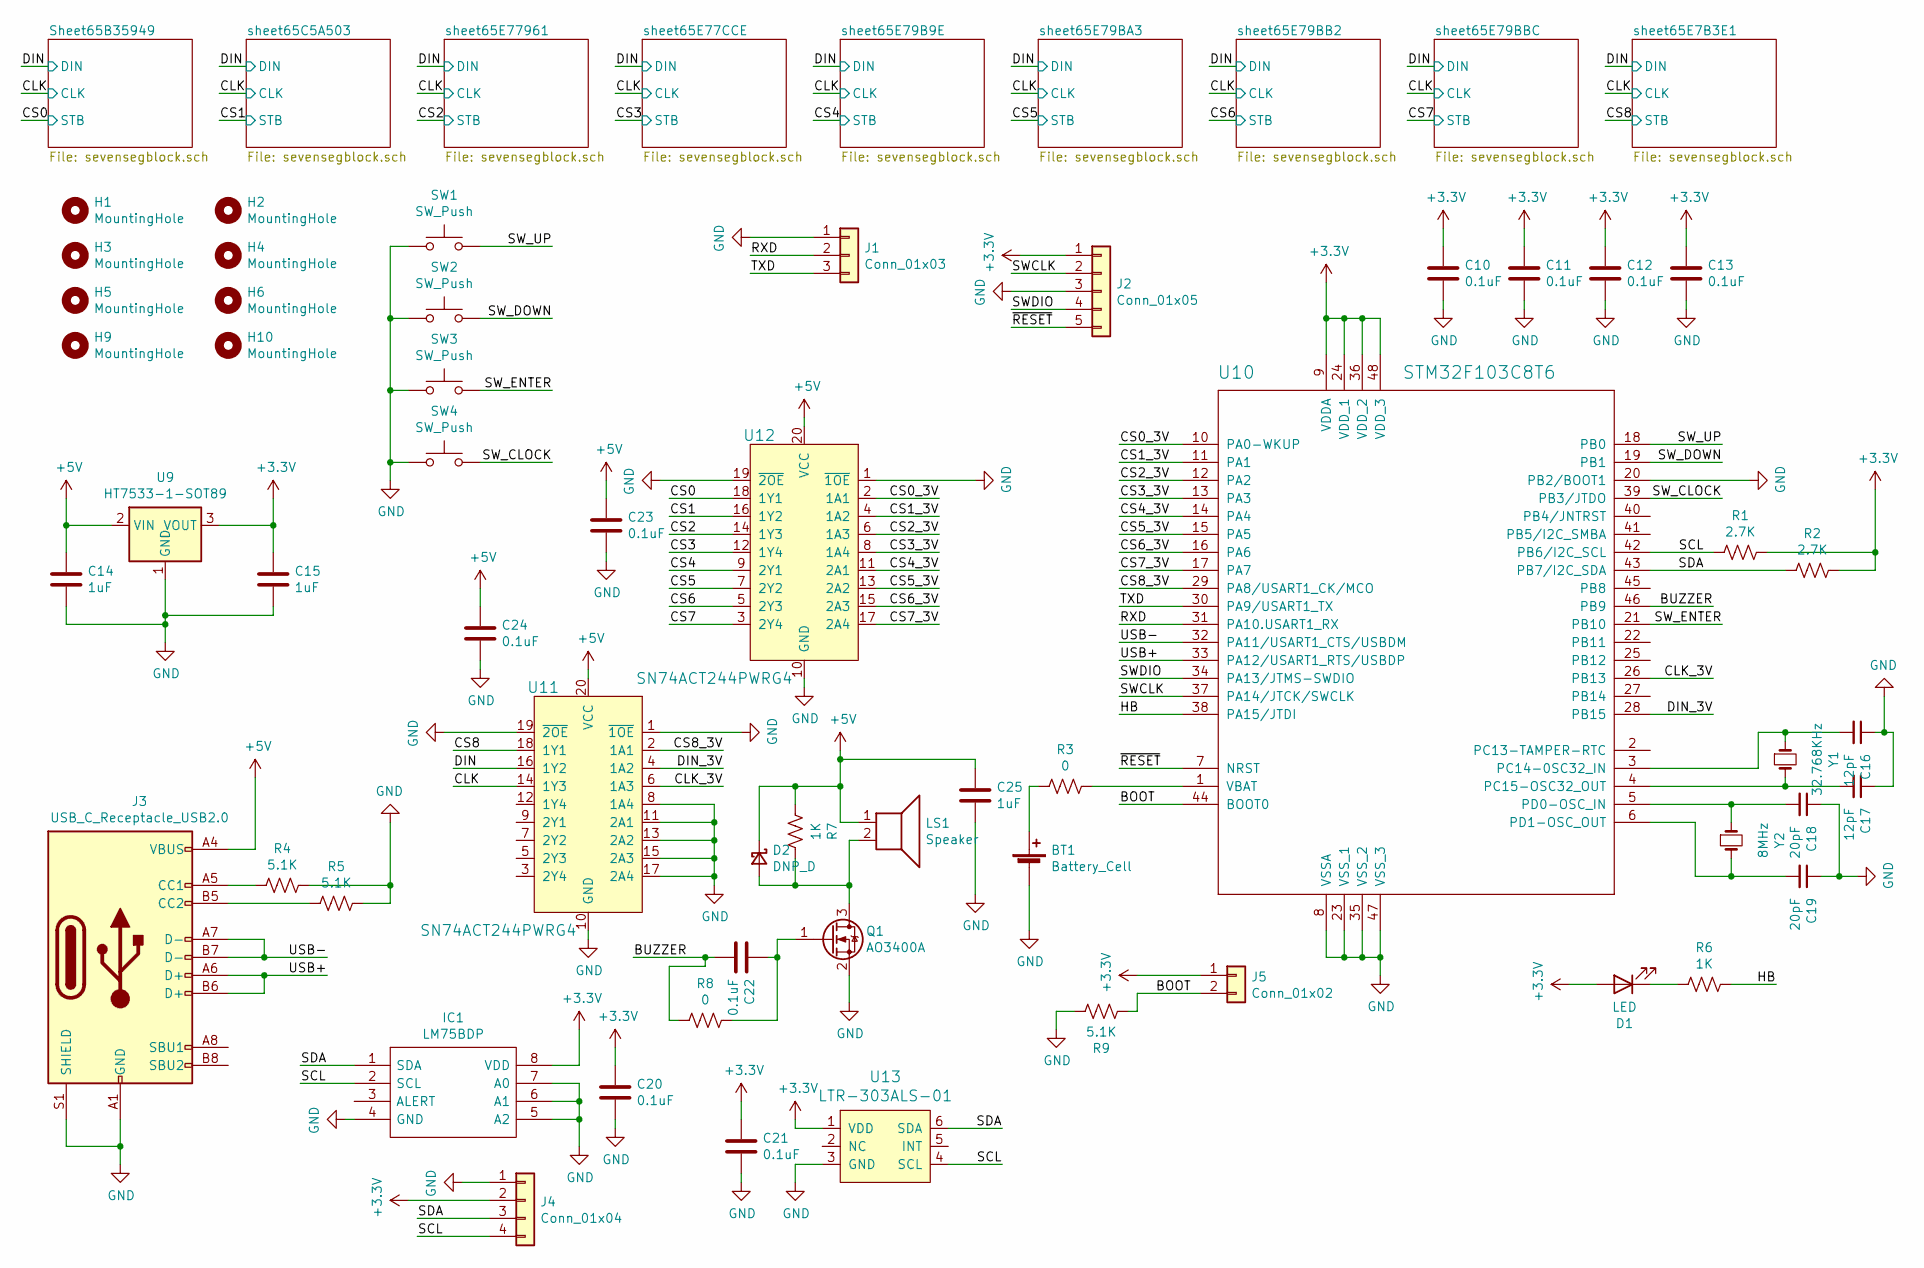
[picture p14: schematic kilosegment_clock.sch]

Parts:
BT1: Battery_Cell; BatteryHolder_CR2032-BS-6-1_1x2032; Digikey BH-49A-5-T-BK
C10, C11, C12, C13, C20, C21, C22, C23, C24: 0.1uF; C_0805_2012Metric_Pad1.18x1.45mm_HandSolder; Digikey 1276-1003-1-ND
C14, C15, C25: 1uF; C_0805_2012Metric_Pad1.18x1.45mm_HandSolder; Digikey 1276-1026-1-ND
C16, C17: 12pF; C_0805_2012Metric_Pad1.18x1.45mm_HandSolder; Digikey CML0805C0G120JT50V
C18, C19: 20pF; C_0805_2012Metric_Pad1.18x1.45mm_HandSolder; Digikey 738-CML0805C0G200JT50VCT-ND
D1: LED; LED_0805_2012Metric_Pad1.15x1.40mm_HandSolder; Digikey 754-1132-1-ND
D2: DNP_D; D_SOD-123
H1, H2, H3, H4, H5, H6, H9, H10: MountingHole; pcb_nut_m3
IC1: LM75BDP; MSOP-8_3x3mm_P0.65mm; Digikey 568-4768-1-ND
J1: Conn_01x03; PinHeader_1x03_P2.54mm_Vertical
J2: Conn_01x05; PinHeader_1x05_P2.54mm_Vertical
J3: USB_C_Receptacle_USB2.0; USB_C_Receptacle_HRO_TYPE-C-31-M-12; Digikey 664-12402012E212ACT-ND
J4: Conn_01x04; PinHeader_1x04_P2.54mm_Vertical
J5: Conn_01x02; PinHeader_1x02_P2.54mm_Vertical
LS1: Speaker; BUZ-TH_PKM13EPYH4002-B0; Digikey 490-4697-ND
Q1: AO3400A; SOT-23_Handsoldering; LCSC Part C20917
R1, R2: 2.7K; R_0805_2012Metric_Pad1.20x1.40mm_HandSolder; Digikey RMCF0805FT2K70CT-ND
R3, R8: 0; R_0805_2012Metric_Pad1.20x1.40mm_HandSolder; Digikey RMCF0805ZT0R00CT-ND
R4, R5, R9: 5.1K; R_0805_2012Metric_Pad1.20x1.40mm_HandSolder; Digikey RMCF0805FT5K10CT-ND
R6, R7: 1K; R_0805_2012Metric_Pad1.20x1.40mm_HandSolder; Digikey RMCF0805FT1K00CT-ND
SW1, SW2, SW3, SW4: SW_Push; SW_SPST_TL3342; Digikey CKN12222-1-ND
U9: HT7533-1-SOT89; SOT-89-3; Digikey 2129-RH5RL33AA-T1-FECT-ND
U10: STM32F103C8T6; LQFP-48_7x7mm_P0.5mm; Digikey 497-11517-ND
U11, U12: SN74ACT244PWRG4; TSSOP-20_4.4x6.5mm_P0.65mm; LCSC Part C6930
U13: LTR-303ALS-01; SOT-363_SC-70-6_Handsoldering; LCSC Part C364577
Y1: 32.768KHz; Crystal_SMD_3215-2Pin_3.2x1.5mm; Digikey 9H03200031-ND
Y2: 8MHz; Crystal_SMD_5032-2Pin_5.0x3.2mm_HandSoldering; Digikey XC2103CT-ND

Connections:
+3V3: C10.1, C11.1, C12.1, C13.1, C15.1, C20.1, C21.1, D1.2 (A), IC1.8 (VDD), J2.1, J4.2, J5.1, R1.1, R2.1, U9.3 (VOUT), U10.9 (VDDA), U10.24 (VDD_1), U10.36 (VDD_2), U10.48 (VDD_3), U13.1 (VDD)
+5V: C14.1, C23.1, C24.1, C25.1, D2.1 (K), J3.A4 (VBUS), J3.A9 (VBUS), J3.B4 (VBUS), J3.B9 (VBUS), LS1.1, R7.2, U9.2 (VIN), U11.20 (VCC), U12.20 (VCC); also elsewhere on the board
/BOOT: J5.2, R9.2, U10.44 (BOOT0)
/BUZZER: C22.2, R8.2, U10.46 (PB9)
/CLK: U11.14 (1Y3); also elsewhere on the board
/CLK_3V: U10.26 (PB13), U11.6 (1A3)
/CS0: U12.18 (1Y1); also elsewhere on the board
/CS0_3V: U10.10 (PA0-WKUP), U12.2 (1A1)
/CS1: U12.16 (1Y2); also elsewhere on the board
/CS1_3V: U10.11 (PA1), U12.4 (1A2)
/CS2: U12.14 (1Y3); also elsewhere on the board
/CS2_3V: U10.12 (PA2), U12.6 (1A3)
/CS3: U12.12 (1Y4); also elsewhere on the board
/CS3_3V: U10.13 (PA3), U12.8 (1A4)
/CS4: U12.9 (2Y1); also elsewhere on the board
/CS4_3V: U10.14 (PA4), U12.11 (2A1)
/CS5: U12.7 (2Y2); also elsewhere on the board
/CS5_3V: U10.15 (PA5), U12.13 (2A2)
/CS6: U12.5 (2Y3); also elsewhere on the board
/CS6_3V: U10.16 (PA6), U12.15 (2A3)
/CS7: U12.3 (2Y4); also elsewhere on the board
/CS7_3V: U10.17 (PA7), U12.17 (2A4)
/CS8: U11.18 (1Y1); also elsewhere on the board
/CS8_3V: U10.29 (PA8/USART1_CK/MCO), U11.2 (1A1)
/DIN: U11.16 (1Y2); also elsewhere on the board
/DIN_3V: U10.28 (PB15), U11.4 (1A2)
/HB: R6.1, U10.38 (PA15/JTDI)
/RXD: J1.2, U10.31 (PA10.USART1_RX)
/SCL: IC1.2 (SCL), J4.4, R1.2, U10.42 (PB6/I2C_SCL), U13.4 (SCL)
/SDA: IC1.1 (SDA), J4.3, R2.2, U10.43 (PB7/I2C_SDA), U13.6 (SDA)
/SWCLK: J2.2, U10.37 (PA14/JTCK/SWCLK)
/SWDIO: J2.4, U10.34 (PA13/JTMS-SWDIO)
/SW_CLOCK: SW4.2, U10.39 (PB3/JTDO)
/SW_DOWN: SW2.2, U10.19 (PB1)
/SW_ENTER: SW3.2, U10.21 (PB10)
/SW_UP: SW1.2, U10.18 (PB0)
/TXD: J1.3, U10.30 (PA9/USART1_TX)
/USB+: J3.A6 (D+), J3.B6 (D+), U10.33 (PA12/USART1_RTS/USBDP)
/USB-: J3.A7 (D-), J3.B7 (D-), U10.32 (PA11/USART1_CTS/USBDM)
/~RESET: J2.5, U10.7 (NRST)
GND: BT1.2 (-), C10.2, C11.2, C12.2, C13.2, C14.2, C15.2, C16.1, C17.1, C18.1, C19.1, C20.2, C21.2, C23.2, C24.2, C25.2, IC1.4 (GND), IC1.5 (A2), IC1.6 (A1), IC1.7 (A0), J1.1, J2.3, J3.A1 (GND), J3.A12 (GND), J3.B1 (GND), J3.B12 (GND), J3.S1 (SHIELD), J4.1, Q1.2 (S), R4.1, R5.1, R9.1, SW1.1, SW2.1, SW3.1, SW4.1, U9.1 (GND), U10.8 (VSSA), U10.20 (PB2/BOOT1), U10.23 (VSS_1), U10.35 (VSS_2), U10.47 (VSS_3), U11.1 (~1OE), U11.8 (1A4), U11.10 (GND), U11.11 (2A1), U11.13 (2A2), U11.15 (2A3), U11.17 (2A4), U11.19 (~2OE), U12.1 (~1OE), U12.10 (GND), U12.19 (~2OE), U13.3 (GND); also elsewhere on the board
unnamed: BT1.1 (+), R3.2
unnamed: C16.2, U10.3 (PC14-0SC32_IN), Y1.1
unnamed: C17.2, U10.4 (PC15-OSC32_OUT), Y1.2
unnamed: C18.2, U10.5 (PD0-OSC_IN), Y2.1
unnamed: C19.2, U10.6 (PD1-OSC_OUT), Y2.2
unnamed: C22.1, Q1.1 (G), R8.1
unnamed: D1.1 (K), R6.2
unnamed: D2.2 (A), LS1.2, Q1.3 (D), R7.1
unnamed: J3.A5 (CC1), R4.2
unnamed: J3.B5 (CC2), R5.2
unnamed: R3.1, U10.1 (VBAT)

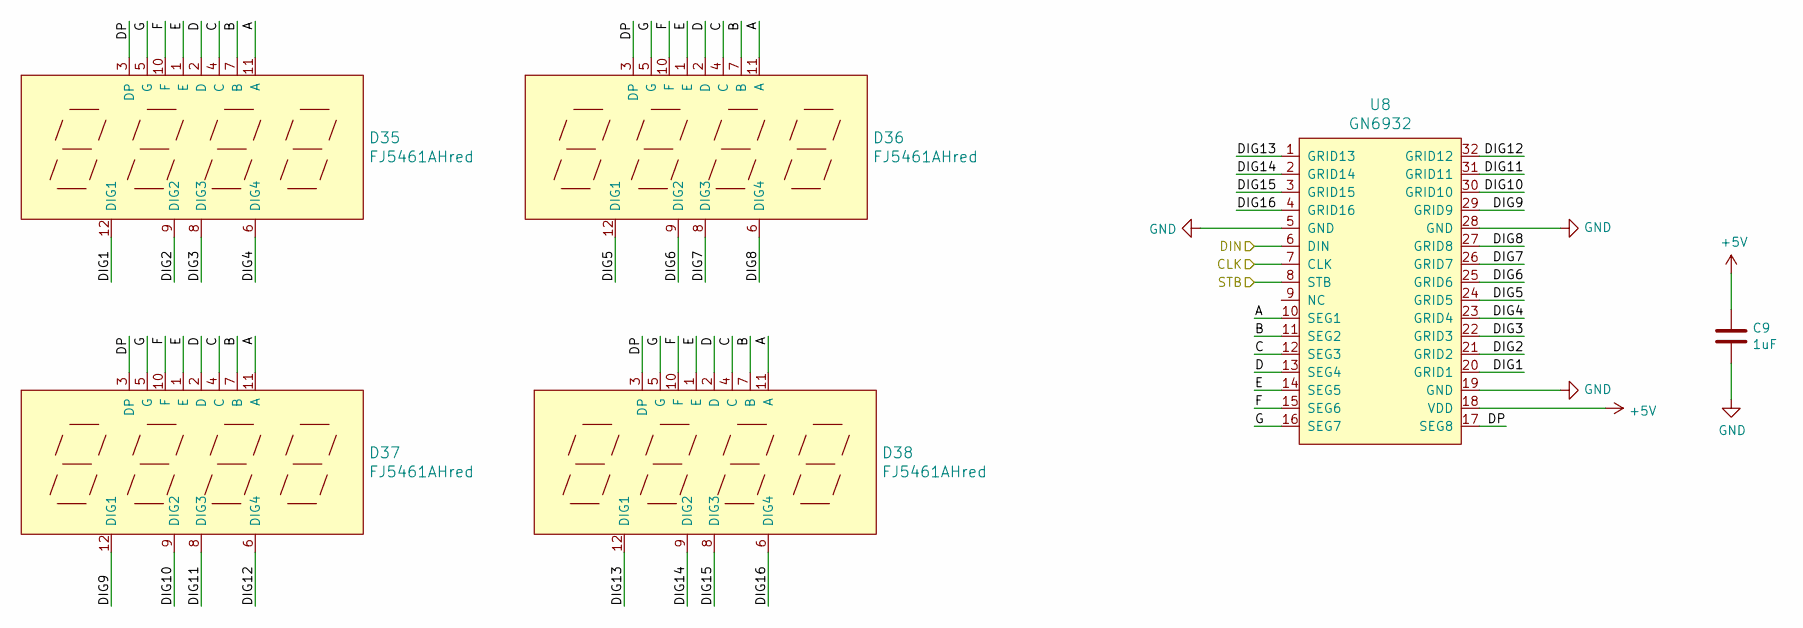
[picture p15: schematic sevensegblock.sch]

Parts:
C1: 1uF; C_0805_2012Metric_Pad1.18x1.45mm_HandSolder; Digikey 1276-1026-1-ND
D3, D4, D5, D6: FJ5461AHred; LED-SEG-TH_FJ5461AH; LCSC Part C54396
U0: GN6932; SOP-32_L21.0-W7.5-P1.27-LS10.4-BL; LCSC Part C265476

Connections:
+5V: C1.1, U0.18 (VDD); also elsewhere on the board
/CLK: U0.7 (CLK); also elsewhere on the board
/CS0: U0.8 (STB); also elsewhere on the board
/DIN: U0.6 (DIN); also elsewhere on the board
/Sheet65B35949/A: D3.11 (A), D4.11 (A), D5.11 (A), D6.11 (A), U0.10 (SEG1)
/Sheet65B35949/B: D3.7 (B), D4.7 (B), D5.7 (B), D6.7 (B), U0.11 (SEG2)
/Sheet65B35949/C: D3.4 (C), D4.4 (C), D5.4 (C), D6.4 (C), U0.12 (SEG3)
/Sheet65B35949/D: D3.2 (D), D4.2 (D), D5.2 (D), D6.2 (D), U0.13 (SEG4)
/Sheet65B35949/DIG1: D3.12 (DIG1), U0.20 (GRID1)
/Sheet65B35949/DIG2: D3.9 (DIG2), U0.21 (GRID2)
/Sheet65B35949/DIG3: D3.8 (DIG3), U0.22 (GRID3)
/Sheet65B35949/DIG4: D3.6 (DIG4), U0.23 (GRID4)
/Sheet65B35949/DIG5: D4.12 (DIG1), U0.24 (GRID5)
/Sheet65B35949/DIG6: D4.9 (DIG2), U0.25 (GRID6)
/Sheet65B35949/DIG7: D4.8 (DIG3), U0.26 (GRID7)
/Sheet65B35949/DIG8: D4.6 (DIG4), U0.27 (GRID8)
/Sheet65B35949/DIG9: D5.12 (DIG1), U0.29 (GRID9)
/Sheet65B35949/DIG10: D5.9 (DIG2), U0.30 (GRID10)
/Sheet65B35949/DIG11: D5.8 (DIG3), U0.31 (GRID11)
/Sheet65B35949/DIG12: D5.6 (DIG4), U0.32 (GRID12)
/Sheet65B35949/DIG13: D6.12 (DIG1), U0.1 (GRID13)
/Sheet65B35949/DIG14: D6.9 (DIG2), U0.2 (GRID14)
/Sheet65B35949/DIG15: D6.8 (DIG3), U0.3 (GRID15)
/Sheet65B35949/DIG16: D6.6 (DIG4), U0.4 (GRID16)
/Sheet65B35949/DP: D3.3 (DP), D4.3 (DP), D5.3 (DP), D6.3 (DP), U0.17 (SEG8)
/Sheet65B35949/E: D3.1 (E), D4.1 (E), D5.1 (E), D6.1 (E), U0.14 (SEG5)
/Sheet65B35949/F: D3.10 (F), D4.10 (F), D5.10 (F), D6.10 (F), U0.15 (SEG6)
/Sheet65B35949/G: D3.5 (G), D4.5 (G), D5.5 (G), D6.5 (G), U0.16 (SEG7)
GND: C1.2, U0.5 (GND), U0.19 (GND), U0.28 (GND); also elsewhere on the board

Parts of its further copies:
C2, C3, C4, C5, C6, C7, C8, C9: 1uF; C_0805_2012Metric_Pad1.18x1.45mm_HandSolder; Digikey 1276-1026-1-ND
D7, D8, D9, D10, D11, D12, D13, D14, D15, D16, D17, D18, D19, D20, D21, D22, D23, D24, D25, D26, D27, D28, D29, D30, D31, D32, D33, D34, D35, D36, D37, D38: FJ5461AHred; LED-SEG-TH_FJ5461AH; LCSC Part C54396
U1, U2, U3, U4, U5, U6, U7, U8: GN6932; SOP-32_L21.0-W7.5-P1.27-LS10.4-BL; LCSC Part C265476

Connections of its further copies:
+5V: C2.1, C3.1, C4.1, C5.1, C6.1, C7.1, C8.1, C9.1, U1.18 (VDD), U2.18 (VDD), U3.18 (VDD), U4.18 (VDD), U5.18 (VDD), U6.18 (VDD), U7.18 (VDD), U8.18 (VDD); also elsewhere on the board
/CLK: U1.7 (CLK), U2.7 (CLK), U3.7 (CLK), U4.7 (CLK), U5.7 (CLK), U6.7 (CLK), U7.7 (CLK), U8.7 (CLK); also elsewhere on the board
/CS1: U1.8 (STB); also elsewhere on the board
/CS2: U2.8 (STB); also elsewhere on the board
/CS3: U3.8 (STB); also elsewhere on the board
/CS4: U4.8 (STB); also elsewhere on the board
/CS5: U5.8 (STB); also elsewhere on the board
/CS6: U6.8 (STB); also elsewhere on the board
/CS7: U7.8 (STB); also elsewhere on the board
/CS8: U8.8 (STB); also elsewhere on the board
/DIN: U1.6 (DIN), U2.6 (DIN), U3.6 (DIN), U4.6 (DIN), U5.6 (DIN), U6.6 (DIN), U7.6 (DIN), U8.6 (DIN); also elsewhere on the board
/sheet65C5A503/A: D7.11 (A), D8.11 (A), D9.11 (A), D10.11 (A), U1.10 (SEG1)
/sheet65C5A503/B: D7.7 (B), D8.7 (B), D9.7 (B), D10.7 (B), U1.11 (SEG2)
/sheet65C5A503/C: D7.4 (C), D8.4 (C), D9.4 (C), D10.4 (C), U1.12 (SEG3)
/sheet65C5A503/D: D7.2 (D), D8.2 (D), D9.2 (D), D10.2 (D), U1.13 (SEG4)
/sheet65C5A503/DIG1: D7.12 (DIG1), U1.20 (GRID1)
/sheet65C5A503/DIG2: D7.9 (DIG2), U1.21 (GRID2)
/sheet65C5A503/DIG3: D7.8 (DIG3), U1.22 (GRID3)
/sheet65C5A503/DIG4: D7.6 (DIG4), U1.23 (GRID4)
/sheet65C5A503/DIG5: D8.12 (DIG1), U1.24 (GRID5)
/sheet65C5A503/DIG6: D8.9 (DIG2), U1.25 (GRID6)
/sheet65C5A503/DIG7: D8.8 (DIG3), U1.26 (GRID7)
/sheet65C5A503/DIG8: D8.6 (DIG4), U1.27 (GRID8)
/sheet65C5A503/DIG9: D9.12 (DIG1), U1.29 (GRID9)
/sheet65C5A503/DIG10: D9.9 (DIG2), U1.30 (GRID10)
/sheet65C5A503/DIG11: D9.8 (DIG3), U1.31 (GRID11)
/sheet65C5A503/DIG12: D9.6 (DIG4), U1.32 (GRID12)
/sheet65C5A503/DIG13: D10.12 (DIG1), U1.1 (GRID13)
/sheet65C5A503/DIG14: D10.9 (DIG2), U1.2 (GRID14)
/sheet65C5A503/DIG15: D10.8 (DIG3), U1.3 (GRID15)
/sheet65C5A503/DIG16: D10.6 (DIG4), U1.4 (GRID16)
/sheet65C5A503/DP: D7.3 (DP), D8.3 (DP), D9.3 (DP), D10.3 (DP), U1.17 (SEG8)
/sheet65C5A503/E: D7.1 (E), D8.1 (E), D9.1 (E), D10.1 (E), U1.14 (SEG5)
/sheet65C5A503/F: D7.10 (F), D8.10 (F), D9.10 (F), D10.10 (F), U1.15 (SEG6)
/sheet65C5A503/G: D7.5 (G), D8.5 (G), D9.5 (G), D10.5 (G), U1.16 (SEG7)
/sheet65E7B3E1/A: D35.11 (A), D36.11 (A), D37.11 (A), D38.11 (A), U8.10 (SEG1)
/sheet65E7B3E1/B: D35.7 (B), D36.7 (B), D37.7 (B), D38.7 (B), U8.11 (SEG2)
/sheet65E7B3E1/C: D35.4 (C), D36.4 (C), D37.4 (C), D38.4 (C), U8.12 (SEG3)
/sheet65E7B3E1/D: D35.2 (D), D36.2 (D), D37.2 (D), D38.2 (D), U8.13 (SEG4)
/sheet65E7B3E1/DIG1: D35.12 (DIG1), U8.20 (GRID1)
/sheet65E7B3E1/DIG2: D35.9 (DIG2), U8.21 (GRID2)
/sheet65E7B3E1/DIG3: D35.8 (DIG3), U8.22 (GRID3)
/sheet65E7B3E1/DIG4: D35.6 (DIG4), U8.23 (GRID4)
/sheet65E7B3E1/DIG5: D36.12 (DIG1), U8.24 (GRID5)
/sheet65E7B3E1/DIG6: D36.9 (DIG2), U8.25 (GRID6)
/sheet65E7B3E1/DIG7: D36.8 (DIG3), U8.26 (GRID7)
/sheet65E7B3E1/DIG8: D36.6 (DIG4), U8.27 (GRID8)
/sheet65E7B3E1/DIG9: D37.12 (DIG1), U8.29 (GRID9)
/sheet65E7B3E1/DIG10: D37.9 (DIG2), U8.30 (GRID10)
/sheet65E7B3E1/DIG11: D37.8 (DIG3), U8.31 (GRID11)
/sheet65E7B3E1/DIG12: D37.6 (DIG4), U8.32 (GRID12)
/sheet65E7B3E1/DIG13: D38.12 (DIG1), U8.1 (GRID13)
/sheet65E7B3E1/DIG14: D38.9 (DIG2), U8.2 (GRID14)
/sheet65E7B3E1/DIG15: D38.8 (DIG3), U8.3 (GRID15)
/sheet65E7B3E1/DIG16: D38.6 (DIG4), U8.4 (GRID16)
/sheet65E7B3E1/DP: D35.3 (DP), D36.3 (DP), D37.3 (DP), D38.3 (DP), U8.17 (SEG8)
/sheet65E7B3E1/E: D35.1 (E), D36.1 (E), D37.1 (E), D38.1 (E), U8.14 (SEG5)
/sheet65E7B3E1/F: D35.10 (F), D36.10 (F), D37.10 (F), D38.10 (F), U8.15 (SEG6)
/sheet65E7B3E1/G: D35.5 (G), D36.5 (G), D37.5 (G), D38.5 (G), U8.16 (SEG7)
/sheet65E77CCE/A: D15.11 (A), D16.11 (A), D17.11 (A), D18.11 (A), U3.10 (SEG1)
/sheet65E77CCE/B: D15.7 (B), D16.7 (B), D17.7 (B), D18.7 (B), U3.11 (SEG2)
/sheet65E77CCE/C: D15.4 (C), D16.4 (C), D17.4 (C), D18.4 (C), U3.12 (SEG3)
/sheet65E77CCE/D: D15.2 (D), D16.2 (D), D17.2 (D), D18.2 (D), U3.13 (SEG4)
/sheet65E77CCE/DIG1: D15.12 (DIG1), U3.20 (GRID1)
/sheet65E77CCE/DIG2: D15.9 (DIG2), U3.21 (GRID2)
/sheet65E77CCE/DIG3: D15.8 (DIG3), U3.22 (GRID3)
/sheet65E77CCE/DIG4: D15.6 (DIG4), U3.23 (GRID4)
/sheet65E77CCE/DIG5: D16.12 (DIG1), U3.24 (GRID5)
/sheet65E77CCE/DIG6: D16.9 (DIG2), U3.25 (GRID6)
/sheet65E77CCE/DIG7: D16.8 (DIG3), U3.26 (GRID7)
/sheet65E77CCE/DIG8: D16.6 (DIG4), U3.27 (GRID8)
/sheet65E77CCE/DIG9: D17.12 (DIG1), U3.29 (GRID9)
/sheet65E77CCE/DIG10: D17.9 (DIG2), U3.30 (GRID10)
/sheet65E77CCE/DIG11: D17.8 (DIG3), U3.31 (GRID11)
/sheet65E77CCE/DIG12: D17.6 (DIG4), U3.32 (GRID12)
/sheet65E77CCE/DIG13: D18.12 (DIG1), U3.1 (GRID13)
/sheet65E77CCE/DIG14: D18.9 (DIG2), U3.2 (GRID14)
/sheet65E77CCE/DIG15: D18.8 (DIG3), U3.3 (GRID15)
/sheet65E77CCE/DIG16: D18.6 (DIG4), U3.4 (GRID16)
/sheet65E77CCE/DP: D15.3 (DP), D16.3 (DP), D17.3 (DP), D18.3 (DP), U3.17 (SEG8)
/sheet65E77CCE/E: D15.1 (E), D16.1 (E), D17.1 (E), D18.1 (E), U3.14 (SEG5)
/sheet65E77CCE/F: D15.10 (F), D16.10 (F), D17.10 (F), D18.10 (F), U3.15 (SEG6)
/sheet65E77CCE/G: D15.5 (G), D16.5 (G), D17.5 (G), D18.5 (G), U3.16 (SEG7)
/sheet65E79B9E/A: D19.11 (A), D20.11 (A), D21.11 (A), D22.11 (A), U4.10 (SEG1)
/sheet65E79B9E/B: D19.7 (B), D20.7 (B), D21.7 (B), D22.7 (B), U4.11 (SEG2)
/sheet65E79B9E/C: D19.4 (C), D20.4 (C), D21.4 (C), D22.4 (C), U4.12 (SEG3)
/sheet65E79B9E/D: D19.2 (D), D20.2 (D), D21.2 (D), D22.2 (D), U4.13 (SEG4)
/sheet65E79B9E/DIG1: D19.12 (DIG1), U4.20 (GRID1)
/sheet65E79B9E/DIG2: D19.9 (DIG2), U4.21 (GRID2)
/sheet65E79B9E/DIG3: D19.8 (DIG3), U4.22 (GRID3)
/sheet65E79B9E/DIG4: D19.6 (DIG4), U4.23 (GRID4)
/sheet65E79B9E/DIG5: D20.12 (DIG1), U4.24 (GRID5)
/sheet65E79B9E/DIG6: D20.9 (DIG2), U4.25 (GRID6)
/sheet65E79B9E/DIG7: D20.8 (DIG3), U4.26 (GRID7)
/sheet65E79B9E/DIG8: D20.6 (DIG4), U4.27 (GRID8)
/sheet65E79B9E/DIG9: D21.12 (DIG1), U4.29 (GRID9)
/sheet65E79B9E/DIG10: D21.9 (DIG2), U4.30 (GRID10)
/sheet65E79B9E/DIG11: D21.8 (DIG3), U4.31 (GRID11)
/sheet65E79B9E/DIG12: D21.6 (DIG4), U4.32 (GRID12)
/sheet65E79B9E/DIG13: D22.12 (DIG1), U4.1 (GRID13)
/sheet65E79B9E/DIG14: D22.9 (DIG2), U4.2 (GRID14)
/sheet65E79B9E/DIG15: D22.8 (DIG3), U4.3 (GRID15)
/sheet65E79B9E/DIG16: D22.6 (DIG4), U4.4 (GRID16)
/sheet65E79B9E/DP: D19.3 (DP), D20.3 (DP), D21.3 (DP), D22.3 (DP), U4.17 (SEG8)
/sheet65E79B9E/E: D19.1 (E), D20.1 (E), D21.1 (E), D22.1 (E), U4.14 (SEG5)
/sheet65E79B9E/F: D19.10 (F), D20.10 (F), D21.10 (F), D22.10 (F), U4.15 (SEG6)
/sheet65E79B9E/G: D19.5 (G), D20.5 (G), D21.5 (G), D22.5 (G), U4.16 (SEG7)
/sheet65E79BA3/A: D23.11 (A), D24.11 (A), D25.11 (A), D26.11 (A), U5.10 (SEG1)
/sheet65E79BA3/B: D23.7 (B), D24.7 (B), D25.7 (B), D26.7 (B), U5.11 (SEG2)
/sheet65E79BA3/C: D23.4 (C), D24.4 (C), D25.4 (C), D26.4 (C), U5.12 (SEG3)
/sheet65E79BA3/D: D23.2 (D), D24.2 (D), D25.2 (D), D26.2 (D), U5.13 (SEG4)
/sheet65E79BA3/DIG1: D23.12 (DIG1), U5.20 (GRID1)
/sheet65E79BA3/DIG2: D23.9 (DIG2), U5.21 (GRID2)
/sheet65E79BA3/DIG3: D23.8 (DIG3), U5.22 (GRID3)
/sheet65E79BA3/DIG4: D23.6 (DIG4), U5.23 (GRID4)
/sheet65E79BA3/DIG5: D24.12 (DIG1), U5.24 (GRID5)
/sheet65E79BA3/DIG6: D24.9 (DIG2), U5.25 (GRID6)
/sheet65E79BA3/DIG7: D24.8 (DIG3), U5.26 (GRID7)
/sheet65E79BA3/DIG8: D24.6 (DIG4), U5.27 (GRID8)
/sheet65E79BA3/DIG9: D25.12 (DIG1), U5.29 (GRID9)
/sheet65E79BA3/DIG10: D25.9 (DIG2), U5.30 (GRID10)
/sheet65E79BA3/DIG11: D25.8 (DIG3), U5.31 (GRID11)
/sheet65E79BA3/DIG12: D25.6 (DIG4), U5.32 (GRID12)
/sheet65E79BA3/DIG13: D26.12 (DIG1), U5.1 (GRID13)
/sheet65E79BA3/DIG14: D26.9 (DIG2), U5.2 (GRID14)
/sheet65E79BA3/DIG15: D26.8 (DIG3), U5.3 (GRID15)
/sheet65E79BA3/DIG16: D26.6 (DIG4), U5.4 (GRID16)
/sheet65E79BA3/DP: D23.3 (DP), D24.3 (DP), D25.3 (DP), D26.3 (DP), U5.17 (SEG8)
/sheet65E79BA3/E: D23.1 (E), D24.1 (E), D25.1 (E), D26.1 (E), U5.14 (SEG5)
/sheet65E79BA3/F: D23.10 (F), D24.10 (F), D25.10 (F), D26.10 (F), U5.15 (SEG6)
/sheet65E79BA3/G: D23.5 (G), D24.5 (G), D25.5 (G), D26.5 (G), U5.16 (SEG7)
/sheet65E79BB2/A: D27.11 (A), D28.11 (A), D29.11 (A), D30.11 (A), U6.10 (SEG1)
/sheet65E79BB2/B: D27.7 (B), D28.7 (B), D29.7 (B), D30.7 (B), U6.11 (SEG2)
/sheet65E79BB2/C: D27.4 (C), D28.4 (C), D29.4 (C), D30.4 (C), U6.12 (SEG3)
/sheet65E79BB2/D: D27.2 (D), D28.2 (D), D29.2 (D), D30.2 (D), U6.13 (SEG4)
/sheet65E79BB2/DIG1: D27.12 (DIG1), U6.20 (GRID1)
/sheet65E79BB2/DIG2: D27.9 (DIG2), U6.21 (GRID2)
/sheet65E79BB2/DIG3: D27.8 (DIG3), U6.22 (GRID3)
/sheet65E79BB2/DIG4: D27.6 (DIG4), U6.23 (GRID4)
/sheet65E79BB2/DIG5: D28.12 (DIG1), U6.24 (GRID5)
/sheet65E79BB2/DIG6: D28.9 (DIG2), U6.25 (GRID6)
/sheet65E79BB2/DIG7: D28.8 (DIG3), U6.26 (GRID7)
/sheet65E79BB2/DIG8: D28.6 (DIG4), U6.27 (GRID8)
/sheet65E79BB2/DIG9: D29.12 (DIG1), U6.29 (GRID9)
/sheet65E79BB2/DIG10: D29.9 (DIG2), U6.30 (GRID10)
/sheet65E79BB2/DIG11: D29.8 (DIG3), U6.31 (GRID11)
/sheet65E79BB2/DIG12: D29.6 (DIG4), U6.32 (GRID12)
/sheet65E79BB2/DIG13: D30.12 (DIG1), U6.1 (GRID13)
/sheet65E79BB2/DIG14: D30.9 (DIG2), U6.2 (GRID14)
/sheet65E79BB2/DIG15: D30.8 (DIG3), U6.3 (GRID15)
/sheet65E79BB2/DIG16: D30.6 (DIG4), U6.4 (GRID16)
/sheet65E79BB2/DP: D27.3 (DP), D28.3 (DP), D29.3 (DP), D30.3 (DP), U6.17 (SEG8)
/sheet65E79BB2/E: D27.1 (E), D28.1 (E), D29.1 (E), D30.1 (E), U6.14 (SEG5)
/sheet65E79BB2/F: D27.10 (F), D28.10 (F), D29.10 (F), D30.10 (F), U6.15 (SEG6)
/sheet65E79BB2/G: D27.5 (G), D28.5 (G), D29.5 (G), D30.5 (G), U6.16 (SEG7)
/sheet65E79BBC/A: D31.11 (A), D32.11 (A), D33.11 (A), D34.11 (A), U7.10 (SEG1)
/sheet65E79BBC/B: D31.7 (B), D32.7 (B), D33.7 (B), D34.7 (B), U7.11 (SEG2)
/sheet65E79BBC/C: D31.4 (C), D32.4 (C), D33.4 (C), D34.4 (C), U7.12 (SEG3)
/sheet65E79BBC/D: D31.2 (D), D32.2 (D), D33.2 (D), D34.2 (D), U7.13 (SEG4)
/sheet65E79BBC/DIG1: D31.12 (DIG1), U7.20 (GRID1)
/sheet65E79BBC/DIG2: D31.9 (DIG2), U7.21 (GRID2)
/sheet65E79BBC/DIG3: D31.8 (DIG3), U7.22 (GRID3)
/sheet65E79BBC/DIG4: D31.6 (DIG4), U7.23 (GRID4)
/sheet65E79BBC/DIG5: D32.12 (DIG1), U7.24 (GRID5)
/sheet65E79BBC/DIG6: D32.9 (DIG2), U7.25 (GRID6)
/sheet65E79BBC/DIG7: D32.8 (DIG3), U7.26 (GRID7)
/sheet65E79BBC/DIG8: D32.6 (DIG4), U7.27 (GRID8)
/sheet65E79BBC/DIG9: D33.12 (DIG1), U7.29 (GRID9)
/sheet65E79BBC/DIG10: D33.9 (DIG2), U7.30 (GRID10)
/sheet65E79BBC/DIG11: D33.8 (DIG3), U7.31 (GRID11)
/sheet65E79BBC/DIG12: D33.6 (DIG4), U7.32 (GRID12)
/sheet65E79BBC/DIG13: D34.12 (DIG1), U7.1 (GRID13)
/sheet65E79BBC/DIG14: D34.9 (DIG2), U7.2 (GRID14)
/sheet65E79BBC/DIG15: D34.8 (DIG3), U7.3 (GRID15)
/sheet65E79BBC/DIG16: D34.6 (DIG4), U7.4 (GRID16)
/sheet65E79BBC/DP: D31.3 (DP), D32.3 (DP), D33.3 (DP), D34.3 (DP), U7.17 (SEG8)
/sheet65E79BBC/E: D31.1 (E), D32.1 (E), D33.1 (E), D34.1 (E), U7.14 (SEG5)
/sheet65E79BBC/F: D31.10 (F), D32.10 (F), D33.10 (F), D34.10 (F), U7.15 (SEG6)
/sheet65E79BBC/G: D31.5 (G), D32.5 (G), D33.5 (G), D34.5 (G), U7.16 (SEG7)
/sheet65E77961/A: D11.11 (A), D12.11 (A), D13.11 (A), D14.11 (A), U2.10 (SEG1)
/sheet65E77961/B: D11.7 (B), D12.7 (B), D13.7 (B), D14.7 (B), U2.11 (SEG2)
/sheet65E77961/C: D11.4 (C), D12.4 (C), D13.4 (C), D14.4 (C), U2.12 (SEG3)
/sheet65E77961/D: D11.2 (D), D12.2 (D), D13.2 (D), D14.2 (D), U2.13 (SEG4)
/sheet65E77961/DIG1: D11.12 (DIG1), U2.20 (GRID1)
/sheet65E77961/DIG2: D11.9 (DIG2), U2.21 (GRID2)
/sheet65E77961/DIG3: D11.8 (DIG3), U2.22 (GRID3)
/sheet65E77961/DIG4: D11.6 (DIG4), U2.23 (GRID4)
/sheet65E77961/DIG5: D12.12 (DIG1), U2.24 (GRID5)
/sheet65E77961/DIG6: D12.9 (DIG2), U2.25 (GRID6)
/sheet65E77961/DIG7: D12.8 (DIG3), U2.26 (GRID7)
/sheet65E77961/DIG8: D12.6 (DIG4), U2.27 (GRID8)
/sheet65E77961/DIG9: D13.12 (DIG1), U2.29 (GRID9)
/sheet65E77961/DIG10: D13.9 (DIG2), U2.30 (GRID10)
/sheet65E77961/DIG11: D13.8 (DIG3), U2.31 (GRID11)
/sheet65E77961/DIG12: D13.6 (DIG4), U2.32 (GRID12)
/sheet65E77961/DIG13: D14.12 (DIG1), U2.1 (GRID13)
/sheet65E77961/DIG14: D14.9 (DIG2), U2.2 (GRID14)
/sheet65E77961/DIG15: D14.8 (DIG3), U2.3 (GRID15)
/sheet65E77961/DIG16: D14.6 (DIG4), U2.4 (GRID16)
/sheet65E77961/DP: D11.3 (DP), D12.3 (DP), D13.3 (DP), D14.3 (DP), U2.17 (SEG8)
/sheet65E77961/E: D11.1 (E), D12.1 (E), D13.1 (E), D14.1 (E), U2.14 (SEG5)
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

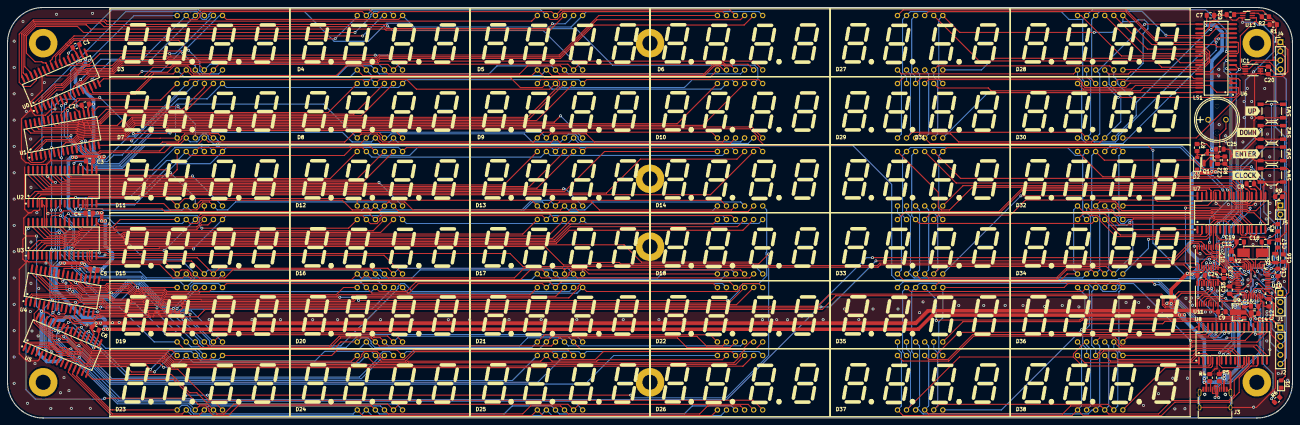
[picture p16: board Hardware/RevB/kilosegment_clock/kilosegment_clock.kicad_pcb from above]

Board: 2 copper layers, 360.0 x 115.0 mm, 113 parts (1 on the bottom side), 268 nets.

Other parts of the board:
kibuzzard-6249F0CC, kibuzzard-6249F13F, kibuzzard-6249F15D, kibuzzard-6249F086: G***; label

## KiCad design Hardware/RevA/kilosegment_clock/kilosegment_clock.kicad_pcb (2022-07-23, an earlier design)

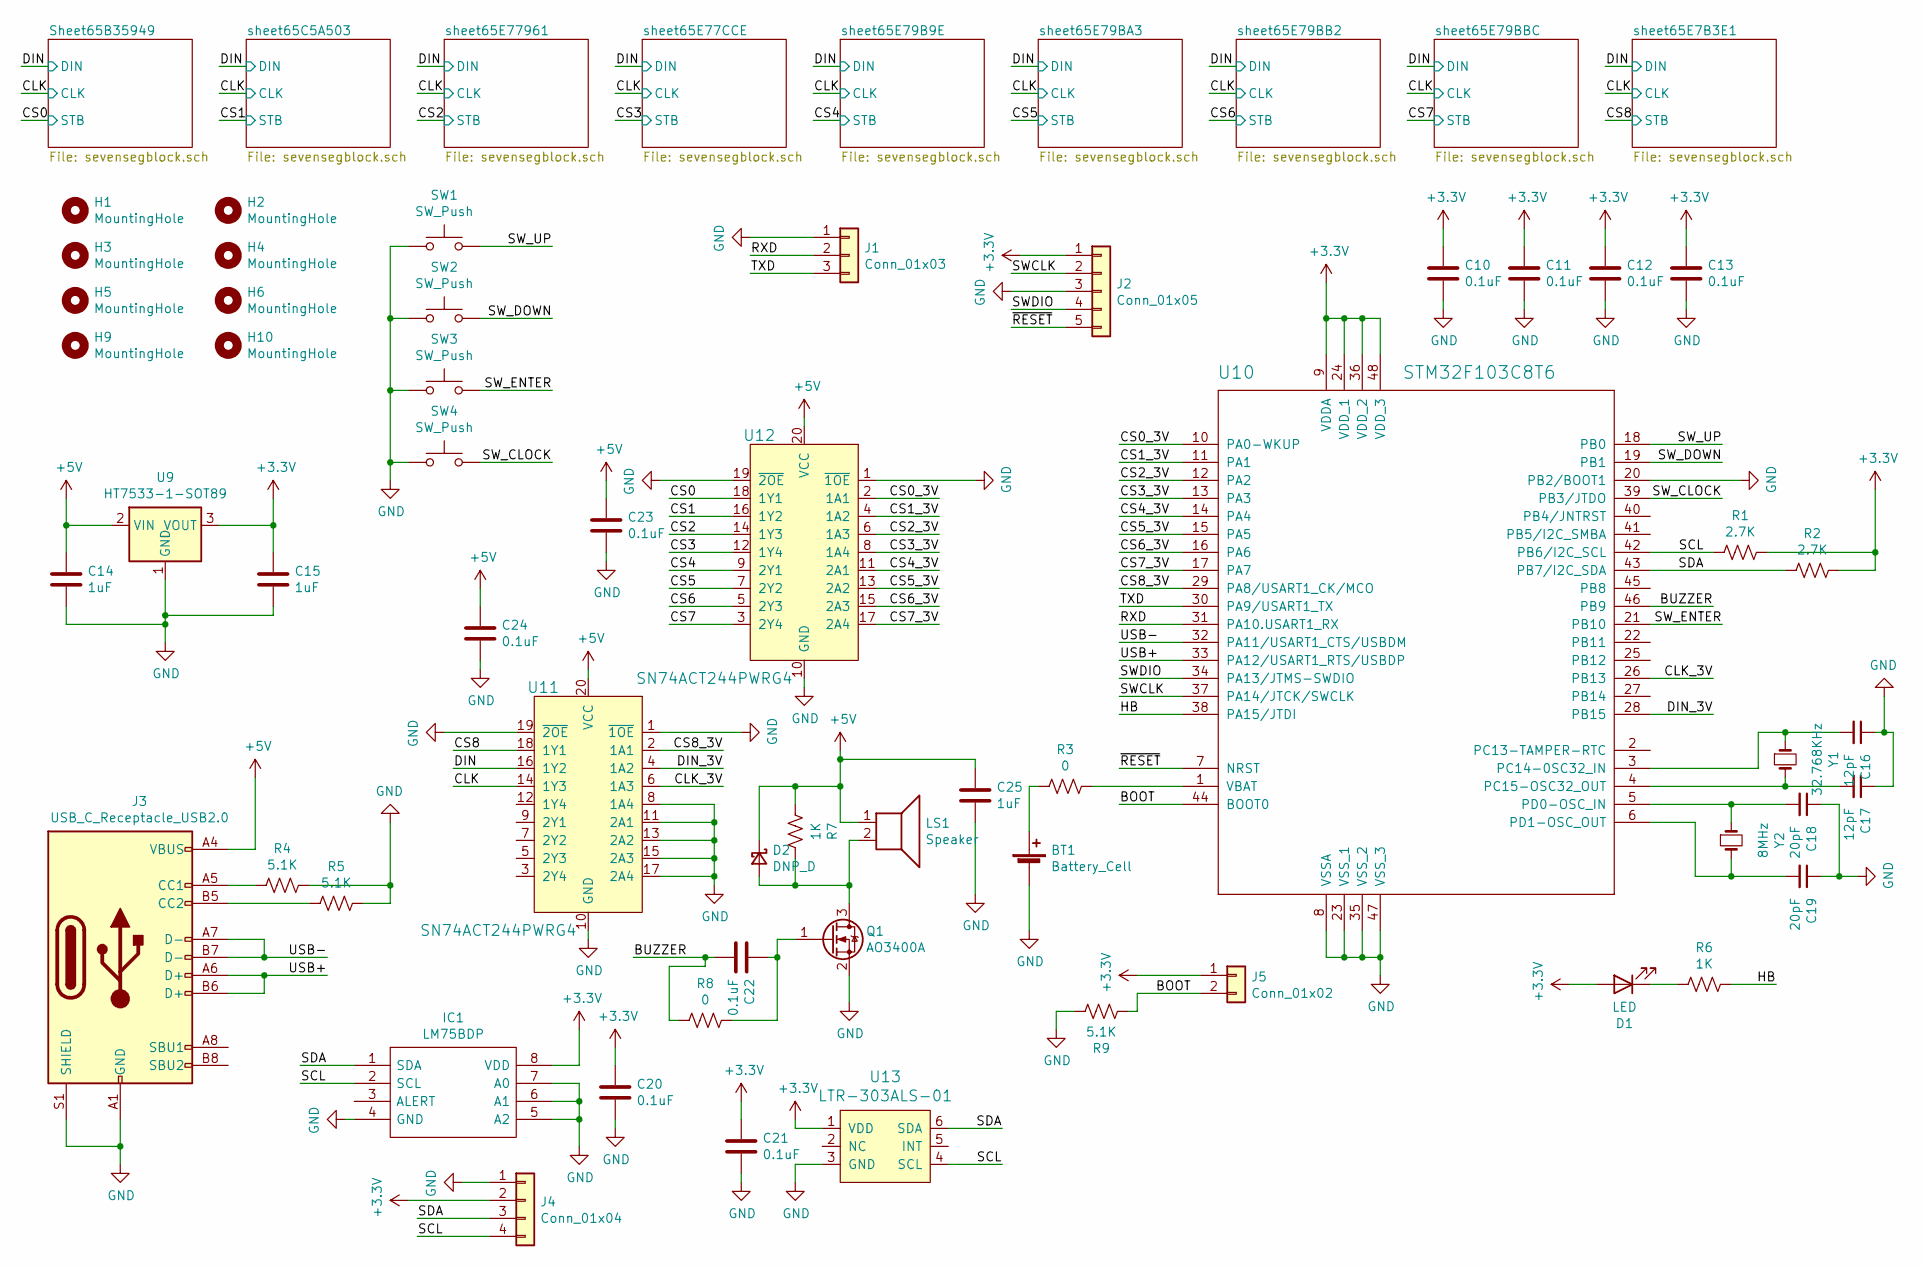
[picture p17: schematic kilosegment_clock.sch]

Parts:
BT1: Battery_Cell; BatteryHolder_CR2032-BS-6-1_1x2032; Digikey BH-49A-5-T-BK
C10, C11, C12, C13, C20, C21, C22, C23, C24: 0.1uF; C_0805_2012Metric_Pad1.18x1.45mm_HandSolder; Digikey 1276-1003-1-ND
C14, C15, C25: 1uF; C_0805_2012Metric_Pad1.18x1.45mm_HandSolder; Digikey 1276-1026-1-ND
C16, C17: 12pF; C_0805_2012Metric_Pad1.18x1.45mm_HandSolder; Digikey CML0805C0G120JT50V
C18, C19: 20pF; C_0805_2012Metric_Pad1.18x1.45mm_HandSolder; Digikey 738-CML0805C0G200JT50VCT-ND
D1: LED; LED_0805_2012Metric_Pad1.15x1.40mm_HandSolder; Digikey 754-1132-1-ND
D2: DNP_D; D_SOD-123
H1, H2, H3, H4, H5, H6, H9, H10: MountingHole; pcb_nut_m3
IC1: LM75BDP; MSOP-8_3x3mm_P0.65mm; Digikey 568-4768-1-ND
J1: Conn_01x03; PinHeader_1x03_P2.54mm_Vertical
J2: Conn_01x05; PinHeader_1x05_P2.54mm_Vertical
J3: USB_C_Receptacle_USB2.0; USB_C_Receptacle_HRO_TYPE-C-31-M-12; Digikey 664-12402012E212ACT-ND
J4: Conn_01x04; PinHeader_1x04_P2.54mm_Vertical
J5: Conn_01x02; PinHeader_1x02_P2.54mm_Vertical
LS1: Speaker; BUZ-TH_PKM13EPYH4002-B0; Digikey 490-4697-ND
Q1: AO3400A; SOT-23_Handsoldering; LCSC Part C20917
R1, R2: 2.7K; R_0805_2012Metric_Pad1.20x1.40mm_HandSolder; Digikey RMCF0805FT2K70CT-ND
R3, R8: 0; R_0805_2012Metric_Pad1.20x1.40mm_HandSolder; Digikey RMCF0805ZT0R00CT-ND
R4, R5, R9: 5.1K; R_0805_2012Metric_Pad1.20x1.40mm_HandSolder; Digikey RMCF0805FT5K10CT-ND
R6, R7: 1K; R_0805_2012Metric_Pad1.20x1.40mm_HandSolder; Digikey RMCF0805FT1K00CT-ND
SW1, SW2, SW3, SW4: SW_Push; SW_SPST_TL3342; Digikey CKN12222-1-ND
U9: HT7533-1-SOT89; SOT-89-3; Digikey 2129-RH5RL33AA-T1-FECT-ND
U10: STM32F103C8T6; LQFP-48_7x7mm_P0.5mm; Digikey 497-11517-ND
U11, U12: SN74ACT244PWRG4; TSSOP-20_4.4x6.5mm_P0.65mm; LCSC Part C6930
U13: LTR-303ALS-01; SOT-363_SC-70-6_Handsoldering; LCSC Part C364577
Y1: 32.768KHz; Crystal_SMD_3215-2Pin_3.2x1.5mm; Digikey 9H03200031-ND
Y2: 8MHz; Crystal_SMD_5032-2Pin_5.0x3.2mm_HandSoldering; Digikey XC2103CT-ND

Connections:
+3V3: C10.1, C11.1, C12.1, C13.1, C15.1, C20.1, C21.1, D1.2 (A), IC1.8 (VDD), J2.1, J4.2, J5.1, R1.1, R2.1, U9.3 (VOUT), U10.9 (VDDA), U10.24 (VDD_1), U10.36 (VDD_2), U10.48 (VDD_3), U13.1 (VDD)
+5V: C14.1, C23.1, C24.1, C25.1, D2.1 (K), J3.A4 (VBUS), J3.A9 (VBUS), J3.B4 (VBUS), J3.B9 (VBUS), LS1.1, R7.2, U9.2 (VIN), U11.20 (VCC), U12.20 (VCC); also elsewhere on the board
/BOOT: J5.2, R9.2, U10.44 (BOOT0)
/BUZZER: C22.2, R8.2, U10.46 (PB9)
/CLK: U11.14 (1Y3); also elsewhere on the board
/CLK_3V: U10.26 (PB13), U11.6 (1A3)
/CS0: U12.18 (1Y1); also elsewhere on the board
/CS0_3V: U10.10 (PA0-WKUP), U12.2 (1A1)
/CS1: U12.16 (1Y2); also elsewhere on the board
/CS1_3V: U10.11 (PA1), U12.4 (1A2)
/CS2: U12.14 (1Y3); also elsewhere on the board
/CS2_3V: U10.12 (PA2), U12.6 (1A3)
/CS3: U12.12 (1Y4); also elsewhere on the board
/CS3_3V: U10.13 (PA3), U12.8 (1A4)
/CS4: U12.9 (2Y1); also elsewhere on the board
/CS4_3V: U10.14 (PA4), U12.11 (2A1)
/CS5: U12.7 (2Y2); also elsewhere on the board
/CS5_3V: U10.15 (PA5), U12.13 (2A2)
/CS6: U12.5 (2Y3); also elsewhere on the board
/CS6_3V: U10.16 (PA6), U12.15 (2A3)
/CS7: U12.3 (2Y4); also elsewhere on the board
/CS7_3V: U10.17 (PA7), U12.17 (2A4)
/CS8: U11.18 (1Y1); also elsewhere on the board
/CS8_3V: U10.29 (PA8/USART1_CK/MCO), U11.2 (1A1)
/DIN: U11.16 (1Y2); also elsewhere on the board
/DIN_3V: U10.28 (PB15), U11.4 (1A2)
/HB: R6.1, U10.38 (PA15/JTDI)
/RXD: J1.2, U10.31 (PA10.USART1_RX)
/SCL: IC1.2 (SCL), J4.4, R1.2, U10.42 (PB6/I2C_SCL), U13.4 (SCL)
/SDA: IC1.1 (SDA), J4.3, R2.2, U10.43 (PB7/I2C_SDA), U13.6 (SDA)
/SWCLK: J2.2, U10.37 (PA14/JTCK/SWCLK)
/SWDIO: J2.4, U10.34 (PA13/JTMS-SWDIO)
/SW_CLOCK: SW4.2, U10.39 (PB3/JTDO)
/SW_DOWN: SW2.2, U10.19 (PB1)
/SW_ENTER: SW3.2, U10.21 (PB10)
/SW_UP: SW1.2, U10.18 (PB0)
/TXD: J1.3, U10.30 (PA9/USART1_TX)
/USB+: J3.A6 (D+), J3.B6 (D+), U10.33 (PA12/USART1_RTS/USBDP)
/USB-: J3.A7 (D-), J3.B7 (D-), U10.32 (PA11/USART1_CTS/USBDM)
/~RESET: J2.5, U10.7 (NRST)
GND: BT1.2 (-), C10.2, C11.2, C12.2, C13.2, C14.2, C15.2, C16.1, C17.1, C18.1, C19.1, C20.2, C21.2, C23.2, C24.2, C25.2, IC1.4 (GND), IC1.5 (A2), IC1.6 (A1), IC1.7 (A0), J1.1, J2.3, J3.A1 (GND), J3.A12 (GND), J3.B1 (GND), J3.B12 (GND), J3.S1 (SHIELD), J4.1, Q1.2 (S), R4.1, R5.1, R9.1, SW1.1, SW2.1, SW3.1, SW4.1, U9.1 (GND), U10.8 (VSSA), U10.20 (PB2/BOOT1), U10.23 (VSS_1), U10.35 (VSS_2), U10.47 (VSS_3), U11.1 (~1OE), U11.8 (1A4), U11.10 (GND), U11.11 (2A1), U11.13 (2A2), U11.15 (2A3), U11.17 (2A4), U11.19 (~2OE), U12.1 (~1OE), U12.10 (GND), U12.19 (~2OE), U13.3 (GND); also elsewhere on the board
unnamed: BT1.1 (+), R3.2
unnamed: C16.2, U10.3 (PC14-0SC32_IN), Y1.1
unnamed: C17.2, U10.4 (PC15-OSC32_OUT), Y1.2
unnamed: C18.2, U10.5 (PD0-OSC_IN), Y2.1
unnamed: C19.2, U10.6 (PD1-OSC_OUT), Y2.2
unnamed: C22.1, Q1.1 (G), R8.1
unnamed: D1.1 (K), R6.2
unnamed: D2.2 (A), LS1.2, Q1.3 (D), R7.1
unnamed: J3.A5 (CC1), R4.2
unnamed: J3.B5 (CC2), R5.2
unnamed: R3.1, U10.1 (VBAT)

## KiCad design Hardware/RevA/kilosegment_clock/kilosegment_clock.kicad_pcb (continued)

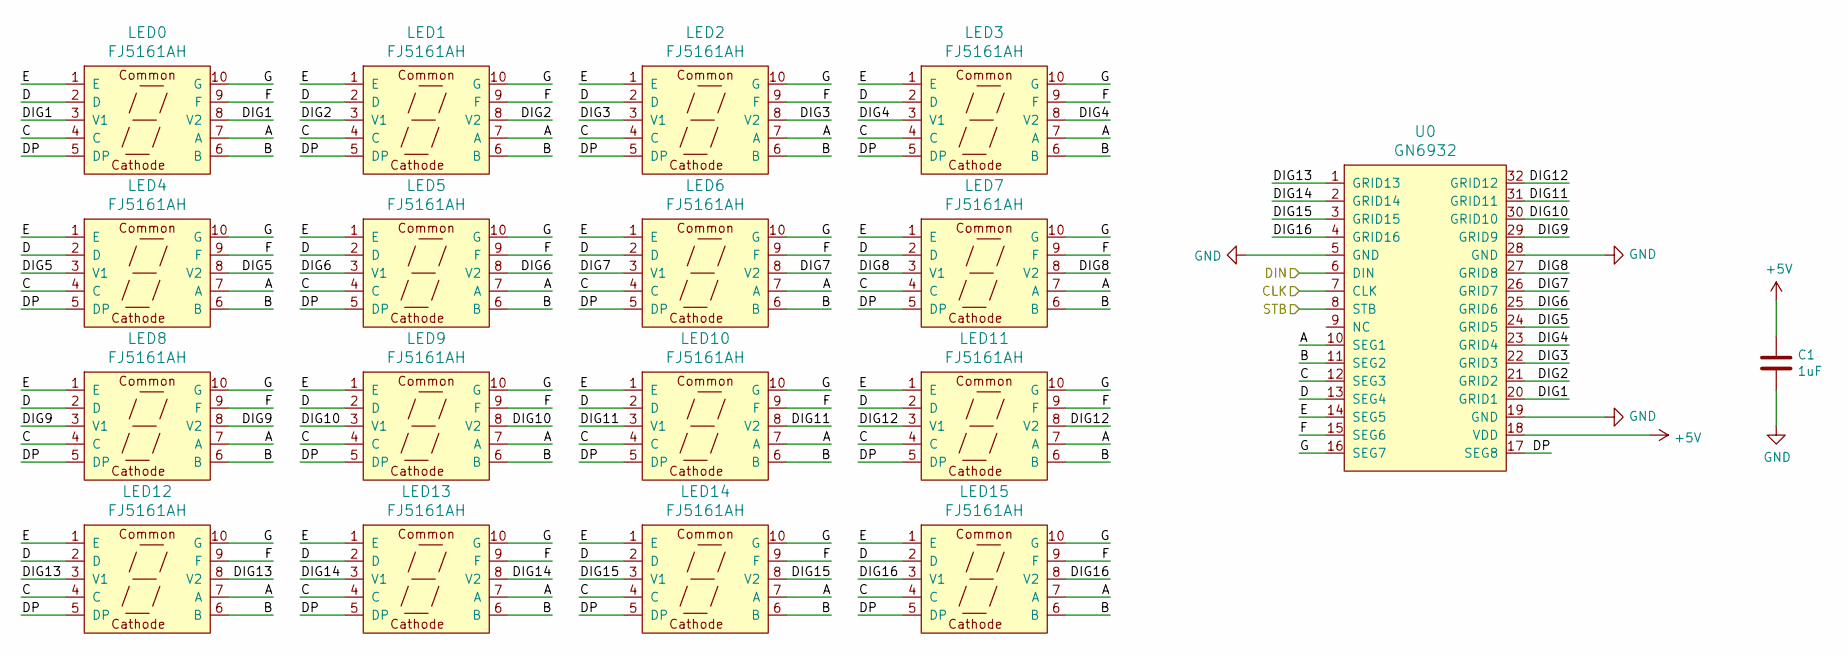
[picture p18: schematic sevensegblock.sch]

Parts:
C1: 1uF; C_0805_2012Metric_Pad1.18x1.45mm_HandSolder; Digikey 1276-1026-1-ND
LED0: FJ5161AH; LED-SEG-TH_FJ5161BH; LCSC Part C8092, C141367
LED1, LED2, LED3, LED4, LED5, LED6, LED7, LED8, LED9, LED10, LED11, LED12, LED13, LED14, LED15: FJ5161AH; LED-SEG-TH_FJ5161BH; LCSC Part C8092
U0: GN6932; SOP-32_L21.0-W7.5-P1.27-LS10.4-BL; LCSC Part C265476

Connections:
+5V: C1.1, U0.18 (VDD); also elsewhere on the board
/CLK: U0.7 (CLK); also elsewhere on the board
/CS0: U0.8 (STB); also elsewhere on the board
/DIN: U0.6 (DIN); also elsewhere on the board
/Sheet65B35949/A: LED0.7 (A), LED1.7 (A), LED2.7 (A), LED3.7 (A), LED4.7 (A), LED5.7 (A), LED6.7 (A), LED7.7 (A), LED8.7 (A), LED9.7 (A), LED10.7 (A), LED11.7 (A), LED12.7 (A), LED13.7 (A), LED14.7 (A), LED15.7 (A), U0.10 (SEG1)
/Sheet65B35949/B: LED0.6 (B), LED1.6 (B), LED2.6 (B), LED3.6 (B), LED4.6 (B), LED5.6 (B), LED6.6 (B), LED7.6 (B), LED8.6 (B), LED9.6 (B), LED10.6 (B), LED11.6 (B), LED12.6 (B), LED13.6 (B), LED14.6 (B), LED15.6 (B), U0.11 (SEG2)
/Sheet65B35949/C: LED0.4 (C), LED1.4 (C), LED2.4 (C), LED3.4 (C), LED4.4 (C), LED5.4 (C), LED6.4 (C), LED7.4 (C), LED8.4 (C), LED9.4 (C), LED10.4 (C), LED11.4 (C), LED12.4 (C), LED13.4 (C), LED14.4 (C), LED15.4 (C), U0.12 (SEG3)
/Sheet65B35949/D: LED0.2 (D), LED1.2 (D), LED2.2 (D), LED3.2 (D), LED4.2 (D), LED5.2 (D), LED6.2 (D), LED7.2 (D), LED8.2 (D), LED9.2 (D), LED10.2 (D), LED11.2 (D), LED12.2 (D), LED13.2 (D), LED14.2 (D), LED15.2 (D), U0.13 (SEG4)
/Sheet65B35949/DIG1: LED0.3 (V1), LED0.8 (V2), U0.20 (GRID1)
/Sheet65B35949/DIG2: LED1.3 (V1), LED1.8 (V2), U0.21 (GRID2)
/Sheet65B35949/DIG3: LED2.3 (V1), LED2.8 (V2), U0.22 (GRID3)
/Sheet65B35949/DIG4: LED3.3 (V1), LED3.8 (V2), U0.23 (GRID4)
/Sheet65B35949/DIG5: LED4.3 (V1), LED4.8 (V2), U0.24 (GRID5)
/Sheet65B35949/DIG6: LED5.3 (V1), LED5.8 (V2), U0.25 (GRID6)
/Sheet65B35949/DIG7: LED6.3 (V1), LED6.8 (V2), U0.26 (GRID7)
/Sheet65B35949/DIG8: LED7.3 (V1), LED7.8 (V2), U0.27 (GRID8)
/Sheet65B35949/DIG9: LED8.3 (V1), LED8.8 (V2), U0.29 (GRID9)
/Sheet65B35949/DIG10: LED9.3 (V1), LED9.8 (V2), U0.30 (GRID10)
/Sheet65B35949/DIG11: LED10.3 (V1), LED10.8 (V2), U0.31 (GRID11)
/Sheet65B35949/DIG12: LED11.3 (V1), LED11.8 (V2), U0.32 (GRID12)
/Sheet65B35949/DIG13: LED12.3 (V1), LED12.8 (V2), U0.1 (GRID13)
/Sheet65B35949/DIG14: LED13.3 (V1), LED13.8 (V2), U0.2 (GRID14)
/Sheet65B35949/DIG15: LED14.3 (V1), LED14.8 (V2), U0.3 (GRID15)
/Sheet65B35949/DIG16: LED15.3 (V1), LED15.8 (V2), U0.4 (GRID16)
/Sheet65B35949/DP: LED0.5 (DP), LED1.5 (DP), LED2.5 (DP), LED3.5 (DP), LED4.5 (DP), LED5.5 (DP), LED6.5 (DP), LED7.5 (DP), LED8.5 (DP), LED9.5 (DP), LED10.5 (DP), LED11.5 (DP), LED12.5 (DP), LED13.5 (DP), LED14.5 (DP), LED15.5 (DP), U0.17 (SEG8)
/Sheet65B35949/E: LED0.1 (E), LED1.1 (E), LED2.1 (E), LED3.1 (E), LED4.1 (E), LED5.1 (E), LED6.1 (E), LED7.1 (E), LED8.1 (E), LED9.1 (E), LED10.1 (E), LED11.1 (E), LED12.1 (E), LED13.1 (E), LED14.1 (E), LED15.1 (E), U0.14 (SEG5)
/Sheet65B35949/F: LED0.9 (F), LED1.9 (F), LED2.9 (F), LED3.9 (F), LED4.9 (F), LED5.9 (F), LED6.9 (F), LED7.9 (F), LED8.9 (F), LED9.9 (F), LED10.9 (F), LED11.9 (F), LED12.9 (F), LED13.9 (F), LED14.9 (F), LED15.9 (F), U0.15 (SEG6)
/Sheet65B35949/G: LED0.10 (G), LED1.10 (G), LED2.10 (G), LED3.10 (G), LED4.10 (G), LED5.10 (G), LED6.10 (G), LED7.10 (G), LED8.10 (G), LED9.10 (G), LED10.10 (G), LED11.10 (G), LED12.10 (G), LED13.10 (G), LED14.10 (G), LED15.10 (G), U0.16 (SEG7)
GND: C1.2, U0.5 (GND), U0.19 (GND), U0.28 (GND); also elsewhere on the board

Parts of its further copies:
C2, C3, C4, C5, C6, C7, C8, C9: 1uF; C_0805_2012Metric_Pad1.18x1.45mm_HandSolder; Digikey 1276-1026-1-ND
LED16, LED32, LED48, LED64, LED80, LED96, LED112, LED128: FJ5161AH; LED-SEG-TH_FJ5161BH; LCSC Part C8092, C141367
LED17, LED18, LED19, LED20, LED21, LED22, LED23, LED24, LED25, LED26, LED27, LED28, LED29, LED30, LED31, LED33, LED34, LED35, LED36, LED37, LED38, LED39, LED40, LED41, LED42, LED43, LED44, LED45, LED46, LED47, LED49, LED50, LED51, LED52, LED53, LED54, LED55, LED56, LED57, LED58, LED59, LED60, LED61, LED62, LED63, LED65, LED66, LED67, LED68, LED69, LED70, LED71, LED72, LED73, LED74, LED75, LED76, LED77, LED78, LED79, LED81, LED82, LED83, LED84, LED85, LED86, LED87, LED88, LED89, LED90, LED91, LED92, LED93, LED94, LED95, LED97, LED98, LED99, LED100, LED101, LED102, LED103, LED104, LED105, LED106, LED107, LED108, LED109, LED110, LED111, LED113, LED114, LED115, LED116, LED117, LED118, LED119, LED120, LED121, LED122, LED123, LED124, LED125, LED126, LED127, LED129, LED130, LED131, LED132, LED133, LED134, LED135, LED136, LED137, LED138, LED139, LED140, LED141, LED142, LED143: FJ5161AH; LED-SEG-TH_FJ5161BH; LCSC Part C8092
U1, U2, U3, U4, U5, U6, U7, U8: GN6932; SOP-32_L21.0-W7.5-P1.27-LS10.4-BL; LCSC Part C265476

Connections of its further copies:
+5V: C2.1, C3.1, C4.1, C5.1, C6.1, C7.1, C8.1, C9.1, U1.18 (VDD), U2.18 (VDD), U3.18 (VDD), U4.18 (VDD), U5.18 (VDD), U6.18 (VDD), U7.18 (VDD), U8.18 (VDD); also elsewhere on the board
/CLK: U1.7 (CLK), U2.7 (CLK), U3.7 (CLK), U4.7 (CLK), U5.7 (CLK), U6.7 (CLK), U7.7 (CLK), U8.7 (CLK); also elsewhere on the board
/CS1: U1.8 (STB); also elsewhere on the board
/CS2: U2.8 (STB); also elsewhere on the board
/CS3: U3.8 (STB); also elsewhere on the board
/CS4: U4.8 (STB); also elsewhere on the board
/CS5: U5.8 (STB); also elsewhere on the board
/CS6: U6.8 (STB); also elsewhere on the board
/CS7: U7.8 (STB); also elsewhere on the board
/CS8: U8.8 (STB); also elsewhere on the board
/DIN: U1.6 (DIN), U2.6 (DIN), U3.6 (DIN), U4.6 (DIN), U5.6 (DIN), U6.6 (DIN), U7.6 (DIN), U8.6 (DIN); also elsewhere on the board
/sheet65C5A503/A: LED16.7 (A), LED17.7 (A), LED18.7 (A), LED19.7 (A), LED20.7 (A), LED21.7 (A), LED22.7 (A), LED23.7 (A), LED24.7 (A), LED25.7 (A), LED26.7 (A), LED27.7 (A), LED28.7 (A), LED29.7 (A), LED30.7 (A), LED31.7 (A), U1.10 (SEG1)
/sheet65C5A503/B: LED16.6 (B), LED17.6 (B), LED18.6 (B), LED19.6 (B), LED20.6 (B), LED21.6 (B), LED22.6 (B), LED23.6 (B), LED24.6 (B), LED25.6 (B), LED26.6 (B), LED27.6 (B), LED28.6 (B), LED29.6 (B), LED30.6 (B), LED31.6 (B), U1.11 (SEG2)
/sheet65C5A503/C: LED16.4 (C), LED17.4 (C), LED18.4 (C), LED19.4 (C), LED20.4 (C), LED21.4 (C), LED22.4 (C), LED23.4 (C), LED24.4 (C), LED25.4 (C), LED26.4 (C), LED27.4 (C), LED28.4 (C), LED29.4 (C), LED30.4 (C), LED31.4 (C), U1.12 (SEG3)
/sheet65C5A503/D: LED16.2 (D), LED17.2 (D), LED18.2 (D), LED19.2 (D), LED20.2 (D), LED21.2 (D), LED22.2 (D), LED23.2 (D), LED24.2 (D), LED25.2 (D), LED26.2 (D), LED27.2 (D), LED28.2 (D), LED29.2 (D), LED30.2 (D), LED31.2 (D), U1.13 (SEG4)
/sheet65C5A503/DIG1: LED16.3 (V1), LED16.8 (V2), U1.20 (GRID1)
/sheet65C5A503/DIG2: LED17.3 (V1), LED17.8 (V2), U1.21 (GRID2)
/sheet65C5A503/DIG3: LED18.3 (V1), LED18.8 (V2), U1.22 (GRID3)
/sheet65C5A503/DIG4: LED19.3 (V1), LED19.8 (V2), U1.23 (GRID4)
/sheet65C5A503/DIG5: LED20.3 (V1), LED20.8 (V2), U1.24 (GRID5)
/sheet65C5A503/DIG6: LED21.3 (V1), LED21.8 (V2), U1.25 (GRID6)
/sheet65C5A503/DIG7: LED22.3 (V1), LED22.8 (V2), U1.26 (GRID7)
/sheet65C5A503/DIG8: LED23.3 (V1), LED23.8 (V2), U1.27 (GRID8)
/sheet65C5A503/DIG9: LED24.3 (V1), LED24.8 (V2), U1.29 (GRID9)
/sheet65C5A503/DIG10: LED25.3 (V1), LED25.8 (V2), U1.30 (GRID10)
/sheet65C5A503/DIG11: LED26.3 (V1), LED26.8 (V2), U1.31 (GRID11)
/sheet65C5A503/DIG12: LED27.3 (V1), LED27.8 (V2), U1.32 (GRID12)
/sheet65C5A503/DIG13: LED28.3 (V1), LED28.8 (V2), U1.1 (GRID13)
/sheet65C5A503/DIG14: LED29.3 (V1), LED29.8 (V2), U1.2 (GRID14)
/sheet65C5A503/DIG15: LED30.3 (V1), LED30.8 (V2), U1.3 (GRID15)
/sheet65C5A503/DIG16: LED31.3 (V1), LED31.8 (V2), U1.4 (GRID16)
/sheet65C5A503/DP: LED16.5 (DP), LED17.5 (DP), LED18.5 (DP), LED19.5 (DP), LED20.5 (DP), LED21.5 (DP), LED22.5 (DP), LED23.5 (DP), LED24.5 (DP), LED25.5 (DP), LED26.5 (DP), LED27.5 (DP), LED28.5 (DP), LED29.5 (DP), LED30.5 (DP), LED31.5 (DP), U1.17 (SEG8)
/sheet65C5A503/E: LED16.1 (E), LED17.1 (E), LED18.1 (E), LED19.1 (E), LED20.1 (E), LED21.1 (E), LED22.1 (E), LED23.1 (E), LED24.1 (E), LED25.1 (E), LED26.1 (E), LED27.1 (E), LED28.1 (E), LED29.1 (E), LED30.1 (E), LED31.1 (E), U1.14 (SEG5)
/sheet65C5A503/F: LED16.9 (F), LED17.9 (F), LED18.9 (F), LED19.9 (F), LED20.9 (F), LED21.9 (F), LED22.9 (F), LED23.9 (F), LED24.9 (F), LED25.9 (F), LED26.9 (F), LED27.9 (F), LED28.9 (F), LED29.9 (F), LED30.9 (F), LED31.9 (F), U1.15 (SEG6)
/sheet65C5A503/G: LED16.10 (G), LED17.10 (G), LED18.10 (G), LED19.10 (G), LED20.10 (G), LED21.10 (G), LED22.10 (G), LED23.10 (G), LED24.10 (G), LED25.10 (G), LED26.10 (G), LED27.10 (G), LED28.10 (G), LED29.10 (G), LED30.10 (G), LED31.10 (G), U1.16 (SEG7)
/sheet65E7B3E1/A: LED128.7 (A), LED129.7 (A), LED130.7 (A), LED131.7 (A), LED132.7 (A), LED133.7 (A), LED134.7 (A), LED135.7 (A), LED136.7 (A), LED137.7 (A), LED138.7 (A), LED139.7 (A), LED140.7 (A), LED141.7 (A), LED142.7 (A), LED143.7 (A), U8.10 (SEG1)
/sheet65E7B3E1/B: LED128.6 (B), LED129.6 (B), LED130.6 (B), LED131.6 (B), LED132.6 (B), LED133.6 (B), LED134.6 (B), LED135.6 (B), LED136.6 (B), LED137.6 (B), LED138.6 (B), LED139.6 (B), LED140.6 (B), LED141.6 (B), LED142.6 (B), LED143.6 (B), U8.11 (SEG2)
/sheet65E7B3E1/C: LED128.4 (C), LED129.4 (C), LED130.4 (C), LED131.4 (C), LED132.4 (C), LED133.4 (C), LED134.4 (C), LED135.4 (C), LED136.4 (C), LED137.4 (C), LED138.4 (C), LED139.4 (C), LED140.4 (C), LED141.4 (C), LED142.4 (C), LED143.4 (C), U8.12 (SEG3)
/sheet65E7B3E1/D: LED128.2 (D), LED129.2 (D), LED130.2 (D), LED131.2 (D), LED132.2 (D), LED133.2 (D), LED134.2 (D), LED135.2 (D), LED136.2 (D), LED137.2 (D), LED138.2 (D), LED139.2 (D), LED140.2 (D), LED141.2 (D), LED142.2 (D), LED143.2 (D), U8.13 (SEG4)
/sheet65E7B3E1/DIG1: LED128.3 (V1), LED128.8 (V2), U8.20 (GRID1)
/sheet65E7B3E1/DIG2: LED129.3 (V1), LED129.8 (V2), U8.21 (GRID2)
/sheet65E7B3E1/DIG3: LED130.3 (V1), LED130.8 (V2), U8.22 (GRID3)
/sheet65E7B3E1/DIG4: LED131.3 (V1), LED131.8 (V2), U8.23 (GRID4)
/sheet65E7B3E1/DIG5: LED132.3 (V1), LED132.8 (V2), U8.24 (GRID5)
/sheet65E7B3E1/DIG6: LED133.3 (V1), LED133.8 (V2), U8.25 (GRID6)
/sheet65E7B3E1/DIG7: LED134.3 (V1), LED134.8 (V2), U8.26 (GRID7)
/sheet65E7B3E1/DIG8: LED135.3 (V1), LED135.8 (V2), U8.27 (GRID8)
/sheet65E7B3E1/DIG9: LED136.3 (V1), LED136.8 (V2), U8.29 (GRID9)
/sheet65E7B3E1/DIG10: LED137.3 (V1), LED137.8 (V2), U8.30 (GRID10)
/sheet65E7B3E1/DIG11: LED138.3 (V1), LED138.8 (V2), U8.31 (GRID11)
/sheet65E7B3E1/DIG12: LED139.3 (V1), LED139.8 (V2), U8.32 (GRID12)
/sheet65E7B3E1/DIG13: LED140.3 (V1), LED140.8 (V2), U8.1 (GRID13)
/sheet65E7B3E1/DIG14: LED141.3 (V1), LED141.8 (V2), U8.2 (GRID14)
/sheet65E7B3E1/DIG15: LED142.3 (V1), LED142.8 (V2), U8.3 (GRID15)
/sheet65E7B3E1/DIG16: LED143.3 (V1), LED143.8 (V2), U8.4 (GRID16)
/sheet65E7B3E1/DP: LED128.5 (DP), LED129.5 (DP), LED130.5 (DP), LED131.5 (DP), LED132.5 (DP), LED133.5 (DP), LED134.5 (DP), LED135.5 (DP), LED136.5 (DP), LED137.5 (DP), LED138.5 (DP), LED139.5 (DP), LED140.5 (DP), LED141.5 (DP), LED142.5 (DP), LED143.5 (DP), U8.17 (SEG8)
/sheet65E7B3E1/E: LED128.1 (E), LED129.1 (E), LED130.1 (E), LED131.1 (E), LED132.1 (E), LED133.1 (E), LED134.1 (E), LED135.1 (E), LED136.1 (E), LED137.1 (E), LED138.1 (E), LED139.1 (E), LED140.1 (E), LED141.1 (E), LED142.1 (E), LED143.1 (E), U8.14 (SEG5)
/sheet65E7B3E1/F: LED128.9 (F), LED129.9 (F), LED130.9 (F), LED131.9 (F), LED132.9 (F), LED133.9 (F), LED134.9 (F), LED135.9 (F), LED136.9 (F), LED137.9 (F), LED138.9 (F), LED139.9 (F), LED140.9 (F), LED141.9 (F), LED142.9 (F), LED143.9 (F), U8.15 (SEG6)
/sheet65E7B3E1/G: LED128.10 (G), LED129.10 (G), LED130.10 (G), LED131.10 (G), LED132.10 (G), LED133.10 (G), LED134.10 (G), LED135.10 (G), LED136.10 (G), LED137.10 (G), LED138.10 (G), LED139.10 (G), LED140.10 (G), LED141.10 (G), LED142.10 (G), LED143.10 (G), U8.16 (SEG7)
/sheet65E77CCE/A: LED48.7 (A), LED49.7 (A), LED50.7 (A), LED51.7 (A), LED52.7 (A), LED53.7 (A), LED54.7 (A), LED55.7 (A), LED56.7 (A), LED57.7 (A), LED58.7 (A), LED59.7 (A), LED60.7 (A), LED61.7 (A), LED62.7 (A), LED63.7 (A), U3.10 (SEG1)
/sheet65E77CCE/B: LED48.6 (B), LED49.6 (B), LED50.6 (B), LED51.6 (B), LED52.6 (B), LED53.6 (B), LED54.6 (B), LED55.6 (B), LED56.6 (B), LED57.6 (B), LED58.6 (B), LED59.6 (B), LED60.6 (B), LED61.6 (B), LED62.6 (B), LED63.6 (B), U3.11 (SEG2)
/sheet65E77CCE/C: LED48.4 (C), LED49.4 (C), LED50.4 (C), LED51.4 (C), LED52.4 (C), LED53.4 (C), LED54.4 (C), LED55.4 (C), LED56.4 (C), LED57.4 (C), LED58.4 (C), LED59.4 (C), LED60.4 (C), LED61.4 (C), LED62.4 (C), LED63.4 (C), U3.12 (SEG3)
/sheet65E77CCE/D: LED48.2 (D), LED49.2 (D), LED50.2 (D), LED51.2 (D), LED52.2 (D), LED53.2 (D), LED54.2 (D), LED55.2 (D), LED56.2 (D), LED57.2 (D), LED58.2 (D), LED59.2 (D), LED60.2 (D), LED61.2 (D), LED62.2 (D), LED63.2 (D), U3.13 (SEG4)
/sheet65E77CCE/DIG1: LED48.3 (V1), LED48.8 (V2), U3.20 (GRID1)
/sheet65E77CCE/DIG2: LED49.3 (V1), LED49.8 (V2), U3.21 (GRID2)
/sheet65E77CCE/DIG3: LED50.3 (V1), LED50.8 (V2), U3.22 (GRID3)
/sheet65E77CCE/DIG4: LED51.3 (V1), LED51.8 (V2), U3.23 (GRID4)
/sheet65E77CCE/DIG5: LED52.3 (V1), LED52.8 (V2), U3.24 (GRID5)
/sheet65E77CCE/DIG6: LED53.3 (V1), LED53.8 (V2), U3.25 (GRID6)
/sheet65E77CCE/DIG7: LED54.3 (V1), LED54.8 (V2), U3.26 (GRID7)
/sheet65E77CCE/DIG8: LED55.3 (V1), LED55.8 (V2), U3.27 (GRID8)
/sheet65E77CCE/DIG9: LED56.3 (V1), LED56.8 (V2), U3.29 (GRID9)
/sheet65E77CCE/DIG10: LED57.3 (V1), LED57.8 (V2), U3.30 (GRID10)
/sheet65E77CCE/DIG11: LED58.3 (V1), LED58.8 (V2), U3.31 (GRID11)
/sheet65E77CCE/DIG12: LED59.3 (V1), LED59.8 (V2), U3.32 (GRID12)
/sheet65E77CCE/DIG13: LED60.3 (V1), LED60.8 (V2), U3.1 (GRID13)
/sheet65E77CCE/DIG14: LED61.3 (V1), LED61.8 (V2), U3.2 (GRID14)
/sheet65E77CCE/DIG15: LED62.3 (V1), LED62.8 (V2), U3.3 (GRID15)
/sheet65E77CCE/DIG16: LED63.3 (V1), LED63.8 (V2), U3.4 (GRID16)
/sheet65E77CCE/DP: LED48.5 (DP), LED49.5 (DP), LED50.5 (DP), LED51.5 (DP), LED52.5 (DP), LED53.5 (DP), LED54.5 (DP), LED55.5 (DP), LED56.5 (DP), LED57.5 (DP), LED58.5 (DP), LED59.5 (DP), LED60.5 (DP), LED61.5 (DP), LED62.5 (DP), LED63.5 (DP), U3.17 (SEG8)
/sheet65E77CCE/E: LED48.1 (E), LED49.1 (E), LED50.1 (E), LED51.1 (E), LED52.1 (E), LED53.1 (E), LED54.1 (E), LED55.1 (E), LED56.1 (E), LED57.1 (E), LED58.1 (E), LED59.1 (E), LED60.1 (E), LED61.1 (E), LED62.1 (E), LED63.1 (E), U3.14 (SEG5)
/sheet65E77CCE/F: LED48.9 (F), LED49.9 (F), LED50.9 (F), LED51.9 (F), LED52.9 (F), LED53.9 (F), LED54.9 (F), LED55.9 (F), LED56.9 (F), LED57.9 (F), LED58.9 (F), LED59.9 (F), LED60.9 (F), LED61.9 (F), LED62.9 (F), LED63.9 (F), U3.15 (SEG6)
/sheet65E77CCE/G: LED48.10 (G), LED49.10 (G), LED50.10 (G), LED51.10 (G), LED52.10 (G), LED53.10 (G), LED54.10 (G), LED55.10 (G), LED56.10 (G), LED57.10 (G), LED58.10 (G), LED59.10 (G), LED60.10 (G), LED61.10 (G), LED62.10 (G), LED63.10 (G), U3.16 (SEG7)
/sheet65E79B9E/A: LED64.7 (A), LED65.7 (A), LED66.7 (A), LED67.7 (A), LED68.7 (A), LED69.7 (A), LED70.7 (A), LED71.7 (A), LED72.7 (A), LED73.7 (A), LED74.7 (A), LED75.7 (A), LED76.7 (A), LED77.7 (A), LED78.7 (A), LED79.7 (A), U4.10 (SEG1)
/sheet65E79B9E/B: LED64.6 (B), LED65.6 (B), LED66.6 (B), LED67.6 (B), LED68.6 (B), LED69.6 (B), LED70.6 (B), LED71.6 (B), LED72.6 (B), LED73.6 (B), LED74.6 (B), LED75.6 (B), LED76.6 (B), LED77.6 (B), LED78.6 (B), LED79.6 (B), U4.11 (SEG2)
/sheet65E79B9E/C: LED64.4 (C), LED65.4 (C), LED66.4 (C), LED67.4 (C), LED68.4 (C), LED69.4 (C), LED70.4 (C), LED71.4 (C), LED72.4 (C), LED73.4 (C), LED74.4 (C), LED75.4 (C), LED76.4 (C), LED77.4 (C), LED78.4 (C), LED79.4 (C), U4.12 (SEG3)
/sheet65E79B9E/D: LED64.2 (D), LED65.2 (D), LED66.2 (D), LED67.2 (D), LED68.2 (D), LED69.2 (D), LED70.2 (D), LED71.2 (D), LED72.2 (D), LED73.2 (D), LED74.2 (D), LED75.2 (D), LED76.2 (D), LED77.2 (D), LED78.2 (D), LED79.2 (D), U4.13 (SEG4)
/sheet65E79B9E/DIG1: LED64.3 (V1), LED64.8 (V2), U4.20 (GRID1)
/sheet65E79B9E/DIG2: LED65.3 (V1), LED65.8 (V2), U4.21 (GRID2)
/sheet65E79B9E/DIG3: LED66.3 (V1), LED66.8 (V2), U4.22 (GRID3)
/sheet65E79B9E/DIG4: LED67.3 (V1), LED67.8 (V2), U4.23 (GRID4)
/sheet65E79B9E/DIG5: LED68.3 (V1), LED68.8 (V2), U4.24 (GRID5)
/sheet65E79B9E/DIG6: LED69.3 (V1), LED69.8 (V2), U4.25 (GRID6)
/sheet65E79B9E/DIG7: LED70.3 (V1), LED70.8 (V2), U4.26 (GRID7)
/sheet65E79B9E/DIG8: LED71.3 (V1), LED71.8 (V2), U4.27 (GRID8)
/sheet65E79B9E/DIG9: LED72.3 (V1), LED72.8 (V2), U4.29 (GRID9)
/sheet65E79B9E/DIG10: LED73.3 (V1), LED73.8 (V2), U4.30 (GRID10)
/sheet65E79B9E/DIG11: LED74.3 (V1), LED74.8 (V2), U4.31 (GRID11)
/sheet65E79B9E/DIG12: LED75.3 (V1), LED75.8 (V2), U4.32 (GRID12)
/sheet65E79B9E/DIG13: LED76.3 (V1), LED76.8 (V2), U4.1 (GRID13)
/sheet65E79B9E/DIG14: LED77.3 (V1), LED77.8 (V2), U4.2 (GRID14)
/sheet65E79B9E/DIG15: LED78.3 (V1), LED78.8 (V2), U4.3 (GRID15)
/sheet65E79B9E/DIG16: LED79.3 (V1), LED79.8 (V2), U4.4 (GRID16)
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

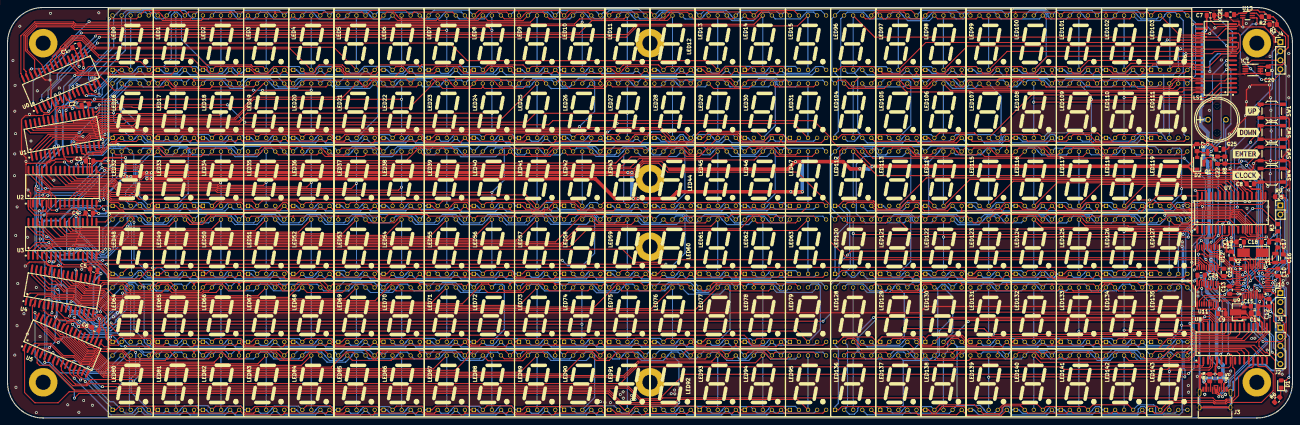
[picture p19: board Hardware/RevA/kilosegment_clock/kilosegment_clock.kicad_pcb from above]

Board: 2 copper layers, 360.0 x 115.0 mm, 221 parts (1 on the bottom side), 268 nets.

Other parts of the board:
kibuzzard-6249F0CC, kibuzzard-6249F13F, kibuzzard-6249F15D, kibuzzard-6249F086: G***; label

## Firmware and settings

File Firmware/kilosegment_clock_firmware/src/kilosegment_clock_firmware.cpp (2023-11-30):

/*---------------------------------------------------
 * 7 Segment array clock
 *
 * Based on clock by Frugha (https://hackaday.io/project/169632-7-segment-display-array-clock)
 *
 * Modifications by John Bradnam (jbrad2089@gmail.com)
 * - Changed hardware to use 0.28" 7 segment displays.
 * - MAX7219 device, digit and segments order has been changed to simply an otherwise
 *   complex PCB board routing.
 * - Hardware uses Arduino Mini Pro, DS1302 RTC and 4 push buttons
 * - Added Alarm function with selectable alarm music
 * - Added Brightness setting
 * - Added Setup screen to set time, date, alarm, music and brightness
 * - Added Date screen (displays for two seconds when ENTER button is pressed
 * Update 2020-06-16
 * - Added date format option on configuration screen
 * - Increased date screen timeout from 2 to 5 seconds
 * - Added a configuarble choice of font for date display
 *
 * Modifications by ArrestedLightning
 * 2022-07-24
 * - Modified to suport Kilosegment clock board hardware
 * -- GN6932 display drivers, onboard RTC
 * - Support temperature sensor
 * - Expand ASCII table
 * - Add second page of settings.
 * - Add built-in version number and build date
 * 2023-03-19
 * - Added function to auto-show date at configurable interval
 * 2023-10-12
 * - Added basic command-line interface
 *--------------------------------------------------*/

#include <SPI.h>
#include <STM32RTC.h>
#include <FlashStorage_STM32F1.h>
#include <LTR303.h>
#include <Temperature_LM75_Derived.h>
#include <HardwareSerial.h>
#include <IWatchdog.h>
#include "Button.h"
#include "Tunes.h"
#include "Digits.h"
#include "mapping.h"
#include "xx6932.h"
#include "kilosegment_clock_firmware.h"
#include "kilosegment_clock_bootloader.h"
#include "build_info.h"
extern "C" {
  #include "cli.h"
}


/* Pin definitions */
#define LED_CLK   PB13
#define LED_DIN   PB14 //not used
#define LED_DOUT  PB15


#define SPEAKER   PB9
#define SW_UP     PB0
#define SW_DOWN   PB1
#define SW_ENTER  PB10
#define SW_CLOCK  PB3

#define HB_LED    PA15

#define NUM_DISPLAY_DRIVERS 9

//time to press the clock button to exit the menu
#define CLOCK_BUTTON_HOLD_TIME  1000

//I really wanted to support more than this, but this is all ST will support with their libraries,
//and right now I can't bring myself to fork and maintain all the libraries that would need to change
//to support dates farther in the future.
//In all likelyhood, it will never even matter.  If someone is still using one of these in the year
//2100, you have my sincere apologies.
#define MAX_YEAR 100

#ifdef WANT_DEBUG
#define debug_println(...)  Serial1.println(__VA_ARGS__)
#else
#define debug_println(...)
#endif

/* Get the rtc object */
STM32RTC& rtc = STM32RTC::getInstance();

//EEPROM handling
#define EEPROM_ADDRESS 0
#define EEPROM_MAGIC 0x0BAD0DAD

#define WANT_CLI 1

//boolean values seem like they can have problems when saved to and loaded from flash
//if a value other than 0 or 1 is loaded, so use uint8_t for all boolean values.
typedef struct {
  uint32_t magic;
  uint8_t alarmEnable;
  uint8_t alarmMinute;
  uint8_t alarmHour;
  uint8_t format12hr;
  uint8_t brightness;
  uint8_t tune;
  uint8_t tempMode;
  uint8_t formatDmy;
  uint8_t squareFont;
  uint8_t autoBrightness;
  uint8_t colonMode;
  uint8_t amPmIndMode;
  uint8_t auto_show_date_interval_index;
} EEPROM_DATA;

EEPROM_DATA EepromData; //Current EEPROM settings

//pulled from time.h
typedef struct {
  uint8_t Second;
  uint8_t Minute;
  uint8_t Hour;
  uint8_t Wday;   // day of week, sunday is day 1
  uint8_t Day;
  uint8_t Month;
  uint8_t Year;   // offset from 2001;
  bool timeUpdated;
  bool dateUpdated;
} TimeElements;

void clockButtonPressed(void);
void enterButtonPressed(void);
void downButtonPressed(void);
void upButtonPressed(void);

Button* clockButton;
Button* enterButton;
Button* downButton;
Button* upButton;

//Operating modes
bool inSubMenu = false;
//blink rate on setup menus
#define SETUP_FLASH_RATE 200
#define DATE_SCREEN_TIMEOUT 5000//ms
unsigned long setupTimeout;
bool setupDisplayState = false;
bool dateShownFlag = false;
bool commandProcessedFlag = false; //just for LED status indicator


enum ClockButtonModesEnum { CLOCK, DATE, TIME_SET, DATE_SET, ALARM_SET, TUNE_SET, BRIGHT_SET, FORMAT_SET, TEMP_SET, COLON_SET, AMPMIND_SET, AUTO_DATE_INTERVAL_SET };
ClockButtonModesEnum clockMode = CLOCK;
#define MENU_PAGE_1_END FORMAT_SET
#define FIRST_CLOCK_MENU_MODE TIME_SET
#define LAST_CLOCK_MENU_MODE AUTO_DATE_INTERVAL_SET

enum TimeSetMenuEnum { TIME_HOUR, TIME_MIN, TIME_FORMAT };
TimeSetMenuEnum timeSetMode = TIME_HOUR;

enum DateSetMenuEnum { DATE_YEAR, DATE_MONTH, DATE_DAY };
DateSetMenuEnum dateSetMode = DATE_YEAR;

enum AlarmSetMenuEnum { ALARM_HOUR, ALARM_MIN, ALARM_STATE };
AlarmSetMenuEnum alarmSetMode = ALARM_HOUR;

enum FormatSetMenuEnum { DAY_MONTH, FONT_STYLE };
FormatSetMenuEnum formatSetMode = DAY_MONTH;

enum BrightnessSetMenuEnum { BRIGHT_VALUE, BRIGHT_AUTO };
BrightnessSetMenuEnum brightSetMode = BRIGHT_VALUE;

#define TEMPMODE_OFF    0
#define TEMPMODE_F      1
#define TEMPMODE_C      2

#define COLONMODE_OFF   0
#define COLONMODE_ON    1
#define COLONMODE_FLASH 2

#define AMPMIND_OFF     0
#define AMPMIND_ON      1
#define AMPMIND_FLASH   2


int lastSeconds = -1;
bool alarmRinging = false;    //true when alarm is on
bool alarmCancelled = false;  //alarm cancelled by user
bool musicPlaying = false;    //true if playing a song
bool clockColon = false;      //show/hide colon
bool debugMode = false;     //show sensor values on date screen, plus other debug options

unsigned int light_sensor_ch0 = 0;
unsigned int light_sensor_ch1 = 0;
bool light_sensor_valid = false;
uint8_t active_brightness_level = 0;

uint32_t date_screen_entry_time = 0;

static const String tempModeStrings[] = {"OFF", "F", "C"};
#define NUM_TEMP_MODES 3

static const String colonModeStrings[] = {"OFF", "ON", "FLASH"};
#define NUM_COLON_MODES 3

#define ampmIndModeStrings   colonModeStrings
#define NUM_AMPMIND_MODES 3

static const uint16_t auto_date_intervals[] = {0, 10, 15, 30, 60, 300, 600, 900, 1800, 3600, 7200, 14400, 21600, 43200}; //in seconds;
#define NUM_AUTO_DATE_INTERVALS (sizeof(auto_date_intervals) / sizeof(auto_date_intervals[0]))

/* Number of days in each month */
const uint8_t dom[] = { 31, 28, 31, 30, 31, 30, 31, 31, 30, 31, 30, 31 };

//Temporary time structure
TimeElements newTime = { 0 };

const uint32_t led_chip_select_pins[NUM_DISPLAY_DRIVERS] = { PA0, PA1, PA2, PA3, PA4, PA5, PA6, PA7, PA8 };
//display driver objects
xx6932 display_drivers[NUM_DISPLAY_DRIVERS];
//LED_DIN is not used, but provided here to keep the library happy
SPIClass SPI_2(LED_DOUT, LED_DIN, LED_CLK);
//TRANSMITRECEIVE is necessary so that it waits for transmission to complete
SPISettings spi_settings(500000, LSBFIRST, SPI_MODE3, SPI_TRANSMITRECEIVE);

Generic_LM75_11Bit temp_sensor;

LTR303 light_sensor;

HardwareSerial Serial1(PA10, PA9);

static void cmd_print_help       (char *args, char *response, size_t response_len);
static void cmd_print_version    (char *args, char *response, size_t response_len);
static void cmd_dump_config      (char *args, char *response, size_t response_len);
static void cmd_set_time         (char *args, char *response, size_t response_len);
static void cmd_set_date         (char *args, char *response, size_t response_len);
static void cmd_set_time_format  (char *args, char *response, size_t response_len);
static void cmd_set_brightness   (char *args, char *response, size_t response_len);
static void cmd_set_alarm        (char *args, char *response, size_t response_len);
static void cmd_save_settings    (char *args, char *response, size_t response_len);
static void cmd_fact_reset       (char *args, char *response, size_t response_len);
static void cmd_show_date        (char *args, char *response, size_t response_len);
static void cmd_get_date_time    (char *args, char *response, size_t response_len);
static void cmd_handle_reboot    (char *args, char *response, size_t response_len);
static void cmd_handle_bootloader(char *args, char *response, size_t response_len);

//if you have one command that's named a subset of another one, be sure to list the longer one first
extern "C" const cli_command cli_commands[] = {
        cmd_def(cmd_print_help,                 "?",            "prints out the list of available commands"),
        cmd_def(cmd_print_help,                 "help",         "prints out the list of available commands"),
        cmd_def(cmd_print_version,              "ver?",         "Prints firmware version."                 ),
        cmd_def(cmd_dump_config,                "config?",      "Prints the saved system config."          ),
        cmd_def(cmd_get_date_time,              "date_time?",   "Prints the current date & time."          ),
        cmd_def(cmd_set_time,                   "set_time",     "Set time hour minute second"              ),
        cmd_def(cmd_set_date,                   "set_date",     "Set date year month day"                  ),
        cmd_def(cmd_set_time_format,            "set_format",   "Set display format 12hr=0/1"              ),
        cmd_def(cmd_set_brightness,             "set_bright",   "Set brightness 0-7 [auto=0/1]"            ),
        cmd_def(cmd_set_alarm,                  "set_alarm",    "Set alarm hour minute [on=0/1]"           ),
        cmd_def(cmd_show_date,                  "show_date",    "Shows the date screen"                    ),
        cmd_def(cmd_save_settings,              "save_config",  "Saves the active configuration to EEPROM" ),
        cmd_def(cmd_fact_reset,                 "fact_reset",   "Resets all settings to factory defaults." ),
        cmd_def(cmd_handle_reboot,              "reboot",       "Reboots the device."                      ),
        cmd_def(cmd_handle_bootloader,          "bootload",     "Reboots the device into bootloader mode"  ),
        cmd_def(NULL, NULL, NULL),
};


void setup()
{
  bool config_reset = false;

#if defined(WANT_DEBUG) || defined(WANT_CLI)
  Serial1.begin(115200);
#endif

  EEPROM.init();

  config_reset = readEepromData();

  //Initialize buttons
  clockButton = new Button(SW_CLOCK, SW_CLOCK, CLOCK_BUTTON_HOLD_TIME);
  clockButton->Held(clockButtonHeld);
  clockButton->Background(feed_watchdog);
  enterButton = new Button(SW_ENTER);
  enterButton->Background(feed_watchdog);
  downButton = new Button(SW_DOWN);
  downButton->Repeat(downButtonPressed);
  downButton->Background(feed_watchdog);
  upButton = new Button(SW_UP);
  upButton->Repeat(upButtonPressed);
  upButton->Background(feed_watchdog);

  //Initialize sound
  pinMode(SPEAKER, OUTPUT);
  digitalWrite(SPEAKER, LOW);

  SPI_2.begin();

  //Initialize display drivers
  for (int i = 0; i < NUM_DISPLAY_DRIVERS; i += 1) {
    display_drivers[i].set_spi_instance(&SPI_2);
    display_drivers[i].set_chip_select_pin(led_chip_select_pins[i]);
    display_drivers[i].set_spi_settings(&spi_settings);
  }

  if (EepromData.autoBrightness) {
    //start at minimum brightness and allow auto-brightness to ramp us up if necessary
    active_brightness_level = 0;
  } else {
    active_brightness_level = EepromData.brightness;
  }
  for (int i = 0; i < NUM_DISPLAY_DRIVERS; i += 1) {
    display_drivers[i].init();
    display_drivers[i].set_brightness(active_brightness_level);
  }

  Wire.begin();
  temp_sensor.disableShutdownMode();
  light_sensor.begin();
  delay(100);
  //set the integration time to 50, sample interval of 50
  light_sensor.setMeasurementRate(0, 0);
  //gain is set to 4 empirically
  light_sensor.setControl(2, false, true);
  delay(15);

  //reset if down button is held on boot
  if (digitalRead(SW_DOWN) == LOW) {
    loadDefaults();
    writeEepromData();
    config_reset = true;
  }

  pinMode(HB_LED, OUTPUT);
  digitalWrite(HB_LED, HIGH);//LED is active low, default off

  //make sure we're using the 32KHz external crystal if we want remotely accurate timekeeping
  rtc.setClockSource(STM32RTC::LSE_CLOCK);
  rtc.begin(STM32RTC::HOUR_24);

  if(!rtc.isTimeSet())
  {
    debug_println("RTC not set");
    rtc.setTime(0, 0, 0);
    rtc.setDate(1, 1, tmYearFromCalendar(2023));
  }
  rtc.getTime(&newTime.Hour, &newTime.Minute, &newTime.Second, NULL, NULL);
  rtc.getDate(&newTime.Wday, &newTime.Day, &newTime.Month, &newTime.Year);
  debug_println("Time: " + String(rtc.getHours()) + ":" + String(rtc.getMinutes()) + ":" + String(rtc.getSeconds()));
  debug_println("Date: " + String(rtc.getDay()) + "/" + String(rtc.getMonth()) + "/" + String(rtc.getYear()));
  newTime.timeUpdated = false;
  newTime.dateUpdated = false;

  clockMode = CLOCK;

  if (config_reset) {
    displayString(0, 0, "DEFAULT SETTINGS LOADED");
    updateDisplay();
    delay(5000);
  }

  showTime(true);
#ifdef WANT_CLI
  SerialUSB.begin();
#endif
  IWatchdog.begin(1000000);
}

void loop()
{
  #ifdef WANT_CLI
  handleCLIUSB();
  handleCLISerial();
  #endif

  if (millis() % 100 == 0) {
    testButtons();

    readLightSensor();

    if (clockMode == CLOCK)
    {
      if (EepromData.auto_show_date_interval_index <  NUM_AUTO_DATE_INTERVALS &&
          auto_date_intervals[EepromData.auto_show_date_interval_index] != 0) {
        if (getSecondOfDay() % auto_date_intervals[EepromData.auto_show_date_interval_index] == 0) {
          if (dateShownFlag == false) {
            dateShownFlag = true;
            switchToDateScreen();
            return; //avoid showing new time for 100ms before switching to date screen
          }
        } else {
          dateShownFlag = false;
        }
      }
      showTime(false);
      if (EepromData.alarmEnable && EepromData.alarmHour == rtc.getHours() && EepromData.alarmMinute == rtc.getMinutes())
      {
        if (!alarmCancelled)
        {
          alarmRinging = true;
          playSong(melodies[EepromData.tune]);
        }
      }
      else
      {
        alarmCancelled = false;
        alarmRinging = false;
      }

    } else if (clockMode == DATE) {
      if (millis() - date_screen_entry_time > DATE_SCREEN_TIMEOUT) {
        clockMode = CLOCK;
      } else {
        showDate(rtc.getDay(), rtc.getMonth(), rtc.getYear());
      }
    }
    else
    {
      showSetup(false);
    }

    // delay(100);
    if (debugMode) {
      digitalWrite(HB_LED, !digitalRead(HB_LED));
    } else {
      //blink LED for one cycle if command received
      if (commandProcessedFlag) {
        commandProcessedFlag = false;
        digitalWrite(HB_LED, LOW);
      } else {
        digitalWrite(HB_LED, HIGH);
      }
    }
  }
  IWatchdog.reload();
}

#ifdef WANT_CLI
void handleCLIUSB(void) {
    bool valid_command;
    if (SerialUSB.available()) {
      char line[128];
      char response[1024];
      memset(line, 0, sizeof(line));
      memset(response, 0, sizeof(response));
      size_t lineLength = SerialUSB.readBytesUntil('\n', line, sizeof(line) - 1);
      line[sizeof(line) - 1] = '\0';
      valid_command = parse_command(line, response, sizeof(response) - 1);
      if (!valid_command) {
        SerialUSB.println("Unrecognized command.");
      } else {
        commandProcessedFlag = true;
        SerialUSB.println(response);
      }
    }
}
void handleCLISerial(void) {
    bool valid_command;
    if (Serial1.available()) {
      char line[128];
      char response[1024];
      memset(line, 0, sizeof(line));
      memset(response, 0, sizeof(response));
      size_t lineLength = Serial1.readBytesUntil('\n', line, sizeof(line) - 1);
      line[sizeof(line) - 1] = '\0';
      valid_command = parse_command(line, response, sizeof(response) - 1);
      if (!valid_command) {
        Serial1.println("Unrecognized command.");
      } else {
        commandProcessedFlag = true;
        Serial1.println(response);
      }
    }
}
#endif


void updateRTCandSettings(void) {
    //Update time
    //reset seconds when updating time so as to allow for synchronization with an external clock,
    //but only if time was actually updated by the user while in the settings menu.  This avoids accumulating
    //offset while modifying other settings.
    if (newTime.timeUpdated) {
      debug_println("Saving Time: " + String(newTime.Hour) + ":" + String(newTime.Minute));
      debug_println("       From: " + String(rtc.getHours()) + ":" + String(rtc.getMinutes()));
      newTime.Second = 0;
      rtc.setTime(newTime.Hour, newTime.Minute, newTime.Second, 0, rtc.AM);
    }
    newTime.timeUpdated = false;

    if (newTime.dateUpdated) {
      debug_println("Saving Date: " + String(tmYearToCalendar(newTime.Year)) + "-" + String(newTime.Month) + "-" + String(newTime.Day));
      debug_println("       From: " + String(tmYearToCalendar(rtc.getYear())) + "-" + String(rtc.getMonth()) + "-" + String(rtc.getDay()));
      rtc.setDate(newTime.Wday, newTime.Day, newTime.Month, newTime.Year);
    }
    newTime.dateUpdated = false;

    if (!rtc.isTimeSet())
    {
      debug_println("Set Time Failed");
    }
    writeEepromData();
    showTime(true);
}
//---------------------------------------------------------------
//Test if any buttons have been pressed
void testButtons(void)
{
  //Single press buttons
  if (clockButton->Pressed())
  {
    clockButtonPressed();
  }
  if (enterButton->Pressed())
  {
    enterButtonPressed();
  }

  //Don't need to check result of pressed since the button handler will invoke its repeat function
  upButton->Pressed();
  downButton->Pressed();
}

//---------------------------------------------------------------
//Handle CLOCK btton
void clockButtonPressed(void)
{
  bool menuEnd = false;
  if (cancelAlarm()) return;

  inSubMenu = false;
  if (clockMode == CLOCK) {
    clockMode = FIRST_CLOCK_MENU_MODE;//jump from clock to menu
  } else if (clockMode == DATE) {
    clockMode = CLOCK;//jump from date to clock
  } else if (clockMode == LAST_CLOCK_MENU_MODE) {
    clockMode = CLOCK;//jump from last menu back to clock
    menuEnd = true;
  } else {
    clockMode = (ClockButtonModesEnum)((int)clockMode + 1);//jump to next menu item
  }
  //update RTC only if we've just left the menu
  if (menuEnd)
  {
    updateRTCandSettings();
  }
  else
  {
    if (clockMode == FIRST_CLOCK_MENU_MODE)
    {
      rtc.getDate(&newTime.Wday, &newTime.Day, &newTime.Month, &newTime.Year);
      rtc.getTime(&newTime.Hour, &newTime.Minute, &newTime.Second, NULL, NULL);
      debug_println("Loading Time: " + String(newTime.Hour) + ":" + String(newTime.Minute));
    }
    showSetup(true);
  }
}

void clockButtonHeld(void)
{
  if (clockMode != CLOCK && clockMode != DATE) {
    clockMode = CLOCK;//jump from last menu back to clock
    updateRTCandSettings();
  }
}

//---------------------------------------------------------------
//Handle ENTER btton
void enterButtonPressed(void)
{
  if (cancelAlarm()) return;

  if (clockMode == CLOCK) {
    switchToDateScreen();
  } else if (clockMode == DATE) {
    clockMode = CLOCK;
  } else {
    if (!inSubMenu)
    {
      timeSetMode = TIME_HOUR;
      dateSetMode = DATE_YEAR;
      alarmSetMode = ALARM_HOUR;
      formatSetMode = DAY_MONTH;
      inSubMenu = true;
    }
    else
    {
      switch (clockMode)
      {
        case TIME_SET: timeSetMode = (timeSetMode == TIME_FORMAT) ? TIME_HOUR : (TimeSetMenuEnum)((int)timeSetMode + 1); break;
        case DATE_SET: dateSetMode = (dateSetMode == DATE_DAY) ? DATE_YEAR : (DateSetMenuEnum)((int)dateSetMode + 1); break;
        case ALARM_SET: alarmSetMode = (alarmSetMode == ALARM_STATE) ? ALARM_HOUR : (AlarmSetMenuEnum)((int)alarmSetMode + 1); break;
        case FORMAT_SET: formatSetMode = (formatSetMode == FONT_STYLE) ? DAY_MONTH : (FormatSetMenuEnum)((int)formatSetMode + 1); break;
        case BRIGHT_SET: brightSetMode = (brightSetMode == BRIGHT_AUTO) ? BRIGHT_VALUE : (BrightnessSetMenuEnum)((int)brightSetMode + 1); break;
        default: break;
      }
    }
    showSetup(true);
  }
}
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

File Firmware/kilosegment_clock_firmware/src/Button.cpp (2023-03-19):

/*
Class: Button
Author: John Bradnam (jbrad2089@gmail.com)
Purpose: Arduino library to handle buttons
Modified by ArrestedLightning to handle "button held"
*/
#include "Button.h"

Button::Button(int pin)
{
  _init(pin, pin, false, 0, 0, true, DEFAULT_REPEAT_START_SPEED);
}

Button::Button(int name, int pin)
{
  _init(name, pin, false, 0, 0, true, DEFAULT_REPEAT_START_SPEED);
}

Button::Button(int name, int pin, unsigned long repeat_time)
{
  _init(name, pin, false, 0, 0, true, repeat_time);
}

Button::Button(int name, int pin, unsigned long repeat_time, bool activeLow)
{
  _init(name, pin, false, 0, 0, activeLow, repeat_time);
}

Button::Button(int name, int pin, int analogLow, int analogHigh, bool activeLow)
{
  _init(name, pin, true, analogLow, analogHigh, activeLow, DEFAULT_REPEAT_START_SPEED);
}


void Button::_init(int name, int pin, bool range, int analogLow, int analogHigh, bool activeLow, unsigned long repeat_speed) {
  _name = name;
  _pin = pin;
  _range = range;
  _low = analogLow;
  _high = analogHigh;
  _activeLow = activeLow;
  _heldTriggered = false;
  _backgroundCallback = NULL;
  _repeatCallback = NULL;
  _heldCallback = NULL;
  _repeat_speed = repeat_speed;
  if (!range) {
    //set pull resistors if button is in digital mode
    if (activeLow) {
      pinMode(_pin, INPUT_PULLUP);
    } else {
      pinMode(_pin, INPUT_PULLDOWN);
    }
  } else {
    //assume we will be reading the pin as an analog input
    pinMode(_pin, INPUT);
  }
}

//Set function to invoke in a delay or repeat loop
void Button::Background(void (*pBackgroundFunction)())
{
  _backgroundCallback = pBackgroundFunction;
}

//Set function to invoke if repeat system required
void Button::Repeat(void (*pRepeatFunction)())
{
  _repeatCallback = pRepeatFunction;
}

void Button::Held(void (*pHeldFunction)())
{
  _heldCallback = pHeldFunction;
}

  bool Button::IsDown()
{
	if (_range)
	{
		int value = analogRead(_pin);
		return (value >= _low && value < _high);
	}
	else
	{
		return (digitalRead(_pin) == LOW);
	}
}

//Tests if a button is pressed and released
//  returns true if the button was pressed and released
//	if repeat callback supplied, the callback is called while the key is pressed
bool Button::Pressed()
{
  bool pressed = false;
  if (IsDown())
  {
    unsigned long wait = millis() + DEBOUNCE_DELAY;
    while (millis() < wait)
    {
      if (_backgroundCallback != NULL)
      {
        _backgroundCallback();
      }
    }
    if (IsDown())
    {
  	  //Set up for repeat loop
  	  if (_repeatCallback != NULL)
  	  {
  	    _repeatCallback();
  	  }
  	  unsigned long speed = _repeat_speed;
  	  unsigned long time = millis() + speed;
      while (IsDown())
      {
        if (_backgroundCallback != NULL)
        {
          _backgroundCallback();
        }
        if (millis() >= time) {
          if (_heldCallback != NULL && !_heldTriggered)
          {
            _heldTriggered = true;
            _heldCallback();

          }
          if (_repeatCallback != NULL)
          {
            _repeatCallback();
            unsigned long faster = speed - REPEAT_INCREASE_SPEED;
            if (faster >= REPEAT_MAX_SPEED)
            {
              speed = faster;
            }
            time = millis() + speed;
          }
        }
      }
      //don't report pressed if the button was held
      if (!_heldTriggered) {
        pressed = true;
      }
    }
  }
  else //button is not pressed
  {
    //reset held down flag if button has been released
    _heldTriggered = false;
  }
  return pressed;
}

//Return current button state
int Button::State()
{
	if (_range)
	{
		int value = analogRead(_pin);
		if (_activeLow)
		{
			return (value >= _low && value < _high) ? LOW : HIGH;
		}
		else
		{
			return (value >= _low && value < _high) ? HIGH : LOW;
		}
	}
	else
	{
		return digitalRead(_pin);
	}
}

//Return current button name
int Button::Name()
{
	return _name;
}

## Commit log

2022-07-23 Initial commit with unmodified firmware
    [Board Outline.FCStd, Board Outline.dxf, Segment Mapping.ods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]
2022-07-30 Temp sensor support, update ASCII table, change menu logic
2022-08-01 Working on debug mode; fixed year setting, rough implementation of auto-brightness
    [kilosegment_clock_firmware.cpp]
2022-08-04 Use correct RTC library calls, fix set day, some EEPROM sanity checking
    [kilosegment_clock_firmware.cpp]
2022-08-28 Fix typo in file names
    [Board Outline.dxf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]
2022-09-03 improve config storage reliability, show message when defaults are loaded, Replace log10 with integer function
    [kilosegment_clock_firmware.cpp]
2023-03-19 Exit menu when clock button held down
2023-06-27 non-blocking main loop, additional filtering on light sensor
2023-09-30 Add default cases to switch statements
2023-11-30 Implement a simple command-line interface. Add a workaround for LED driver glitch.
    [kilosegment_clock_firmware.cpp]
2023-11-30 Switch to HID bootloader for smaller footprint and better reliability
2023-11-30 Enabled watchdog timer.
2023-11-30 Quick hack to avoid tripping watchdog when holding down buttons.
    [kilosegment_clock_firmware.cpp]
